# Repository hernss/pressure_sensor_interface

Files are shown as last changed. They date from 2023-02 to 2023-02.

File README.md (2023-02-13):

# Descripción del proyecto:

Se desea realizar un dispositivo que sirva de interface para un sensor analógico de presión. El sensor en cuestión es un sensor de presión absoluta que trabaja sobre una línea de aire comprimido, la salida de dicho sensor es del tipo 4-20mA y el rango te trabajo es de 0 a 10bar.
Este dispositivo tiene como objetivo mantener la línea de aire comprimido en un rango de presión predefinido por el usuario, y en caso de no encontrarse en dicho límite actúa como dispositivo de seguridad liberando la presión en la línea y haciendo sonar una alarma.
El núcleo de este proyecto es un Cortex M3 de la familia de STM el cual lleva implementado un sistema de control del estilo TDS el cual nos asegura el tiempo de respuesta en caso de presentarse una falla.
Por ser requerimiento de otra materia, se conectaron todos los periféricos a una línea de datos I2C. Estos periféricos son:

* Teclado Capacitivo (IQS316)
* Display LCD de 16 Caracteres 2 líneas con conversor I2C (PCF8754)
* Conversor Analógico Digital (ADS1115)
* Memoria EEPROM para parámetros de configuración (24LC16)
* Dos salidas a relé con optoacoplador de protección.

# Desarrollo en Kicad

Se optó por realizar dos PCB, uno para el teclado con el display y otro para el microcontrolador y los demás periféricos. Se desarrolló de esta manera ya que el teclado capacitivo necesitar ser implementado en el PCB y aplicado directamente sobre el panel frontal. Entonces, se hizo un PCB denominado PanelFrontal el cual lleva los pads del teclado capacitivo en la cara BOTTOM del PCB, se ubicaron los componentes en la cara TOP y se limitó el uso a solo componentes de montaje superficial, es así que al no tener componentes “through hole” no hay nada que sobresalga del lado BOTTOM y es así que el PCB puede ser apoyado directamente sobre el frente del gabinete. En el PCB denominado PlacaBase se implementó el micro-controlador y todos los periféricos ya que estos requieren varios componentes “through hole” y además de eso no hay una uniformidad de alturas lo cual complicaría el desarrollo en una sola placa junto al teclado.

# Calculo de los componentes:

## Fuente de Alimentación:
Nos vamos a encontrar con dos tipos de alimentación, el microcontrolador, la memoria EEPROM y el ADC se alimentan con 3,3V mientras que los demás dispositivos se alimentan con 5V. Es por esto que se decidió alimentar el dispositivo con una fuente externa de 5V DC 1A y se implementó en la placa base una fuente de alimentación de 3.3v basada en un LD1117 con sus respectivos capacitores.

## Capacitores de los cristales:
Para seleccionar estos capacitores vamos a referirnos a la hoja de datos de los cristales. Para el cristal de 8 MHz (ABM7-8.000MHZ-D2Y-T) vemos que la hoja de datos nos dice que capacitancia de carga es de 18 pF por ende se conectan dos capacitores de 18 pF en los pines del cristal a masa. Para el cristal de 32.768 KHz (ABS25-32.768KHZ-T) la hoja de datos nos dice que la capacitancia de carga es de 12.5 pF, en este caso se selecciona un capacitor de 12pF para conectar en los pines del cristal. Se diseña el circuito impreso de tal manera que ambas pistas que conectan al microcontrolador con el cristal tengan el mismo largo y la misma geometría.

## Leds internos de indicación:
Los leds se utilizaron los LTST-C171KRKT y LTST-C170KGKT ambos son excitados por una tensión de 3.3v ya que uno está conectado a una salida del microcontrolador y el otro directamente a los 3.3v de alimentación. Según la hoja de datos observamos que típicamente tienen 2v de tensión en directa. Se decidió usar una resistencia limitadora de 100 Ohms lo cual nos limitaría la corriente del diodo en 13 mA. Lo cual está por debajo de la corriente máxima de 30ma que acusa el fabricante.

I_F=(3.3v-2v)/(100 Ω)=13 mA

## Resistencias de los Optoacopladores:
Si nos referimos al datasheet de los optoacopladores PC817 vemos que la tensión en directa es de 1.2v mientras que la corriente es de 20 mA. En base a estos valores se calculó la resistencia limitadora.

R=(3.3v - 1.2v)/(20 mA)=105 Ω

Se adoptó una resistencia de 100 ohm siendo el valor comercial más cercano.

## Corriente de base en los transistores de los relés:
Se eligió los transistores BC846B para activar los relés. Estos transistores tienen una resistencia de base de 680 ohms. Si suponemos que los optoacopladores tiene la resistencia adecuada para su funcionamiento podemos calcular la corriente de base según la siguiente formula:

I_B=(5V- V_BE)/680Ω=(5V- 0.7v)/680Ω=6.3 mA

Teniendo en cuenta que el relé consume 80 mA, esta corriente nos asegura que el transistor se encuentra saturado con una tensión VCE menor a 0,2v

# Resistencia de entrada del ADC:
El sensor de presión con el que vamos a trabajar posee una salida de 4-20mA donde 4ma representa 0bar y 20mA 10bar. Es por esto que vamos a ajustar la resistencia para que esta corriente nos produzca una caída de tensión que podamos medir con el ADC. Se utilizó una resistencia de 100 ohms la cual se la eligió con una tolerancia de 0,1% ya que es fundamental que este valor de resistencia sea preciso ya que de ella depende la precisión de nuestra medición. Con este valor, la tensión en la entrada del ADC en el rango mínimo será de 0.4v y en el rango máximo de 2v. La tensión máxima admisible en la entrada del ADC es de 3.3v. Con esta configuración el ADC además de permitirnos medir el valor arrojado por el sensor nos da un margen como para medir si la entrada de corriente esta fuera de rango. El ADC tiene una resolución de 16bits, por ende tenemos una resolución de 3,3v / 2^16 = 50 µv/div, siendo para el rango mínimo de 0,4v / (50 µv/div) = 7943 y para el rango máximo 2v / (50 µv/div) = 39718

## Direcciones del Bus I2C:
Cada periférico tiene su propia dirección I2C para que todos puedan funcionar en el mismo bus. Estas especificaciones las obtenemos de las hojas de datos de los componentes. En general la mayoría tiene al menos un pin que podemos conectar a GND o Vcc para terminar de definir la dirección.
Para el caso de ADC el pin de configuración de dirección se conectó a GND asignándole una dirección “1001000x” (0x50h). En la memoria EEPROM los pines de dirección no se encuentran conectados ya que este tamaño de memoria no los implementa. La dirección I2C se usa en parte para direccionar internamente los bloques de memoria, es por esto que para la memoria se reservan las direcciones 0x60h hasta la 0x6Fh. El conversor I2C para el display LCD se le cablearon sus 3 pines de dirección a masa fijándole una dirección I2C de 0x70h. Para el integrado que controla el teclado capacitivo su pin de dirección se encuentra conectado a masa asignándole una dirección I2C de 0xE1h.
De esta manera, todos los periféricos nos quedan con direcciones distintas posibilitando la conexión al mismo bus I2C.

## Consumo total del Dispositivo:
Se analizaron los consumos máximos que podría llegar a tener el dispositivo así poder calcular la fuente de alimentación y el ancho de las pistas. Se analizaron solo los componentes más relevantes. Cada relé consume 80mA estando activados, el LCD tiene un consumo relevante el backligth que según la hoja de datos alcanza los 156 mA como máximo y podríamos sumarle algunos miliamperes mas por los demás componentes lo cual nos daría aproximadamente 330 mA sobre la línea de 5v.
 
# Diagrama Esquemático:

## Panel Frontal:
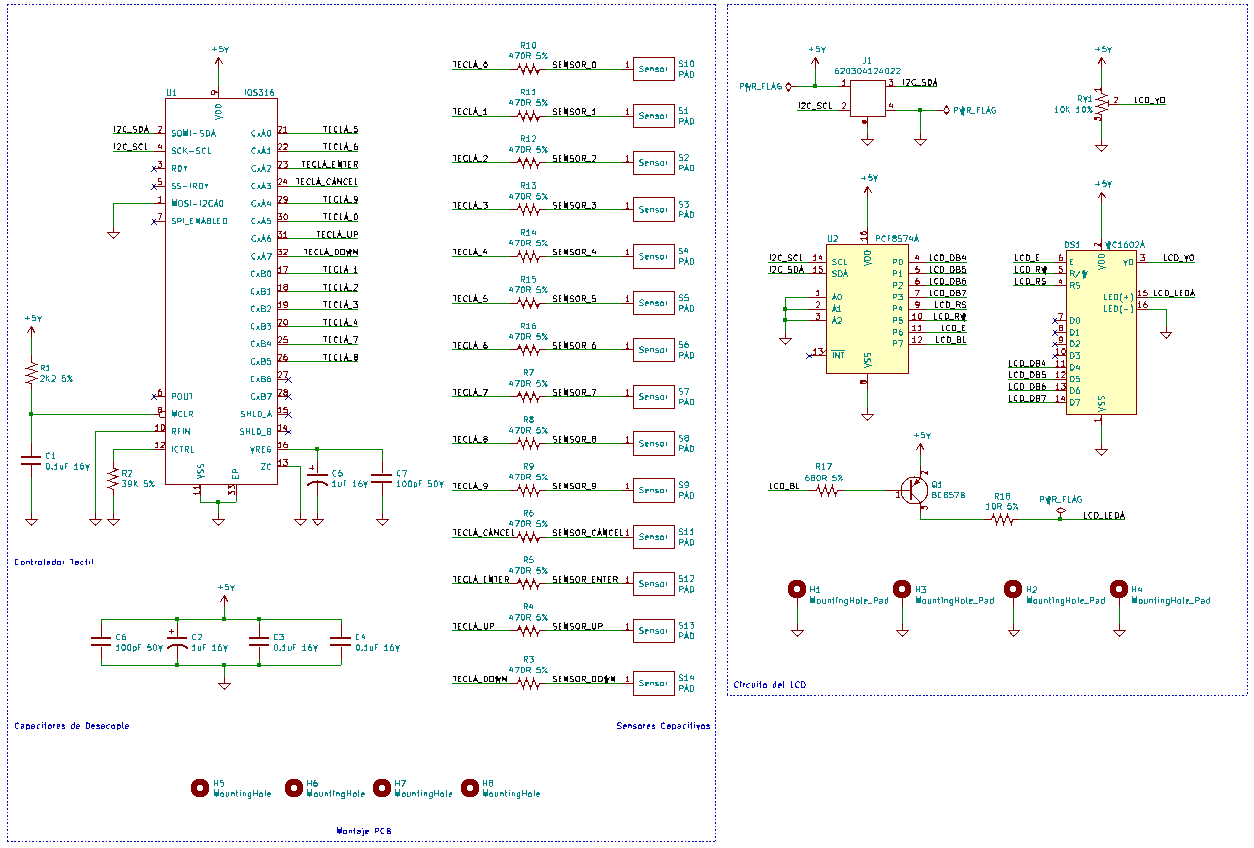
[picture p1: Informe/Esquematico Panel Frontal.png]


## Placa Base
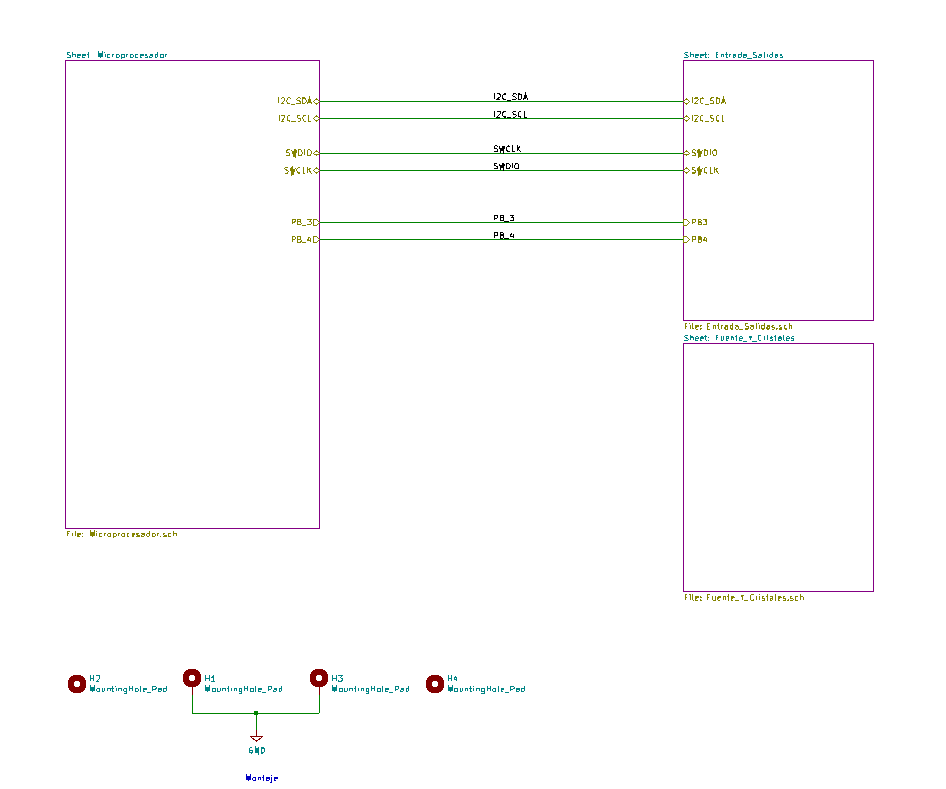
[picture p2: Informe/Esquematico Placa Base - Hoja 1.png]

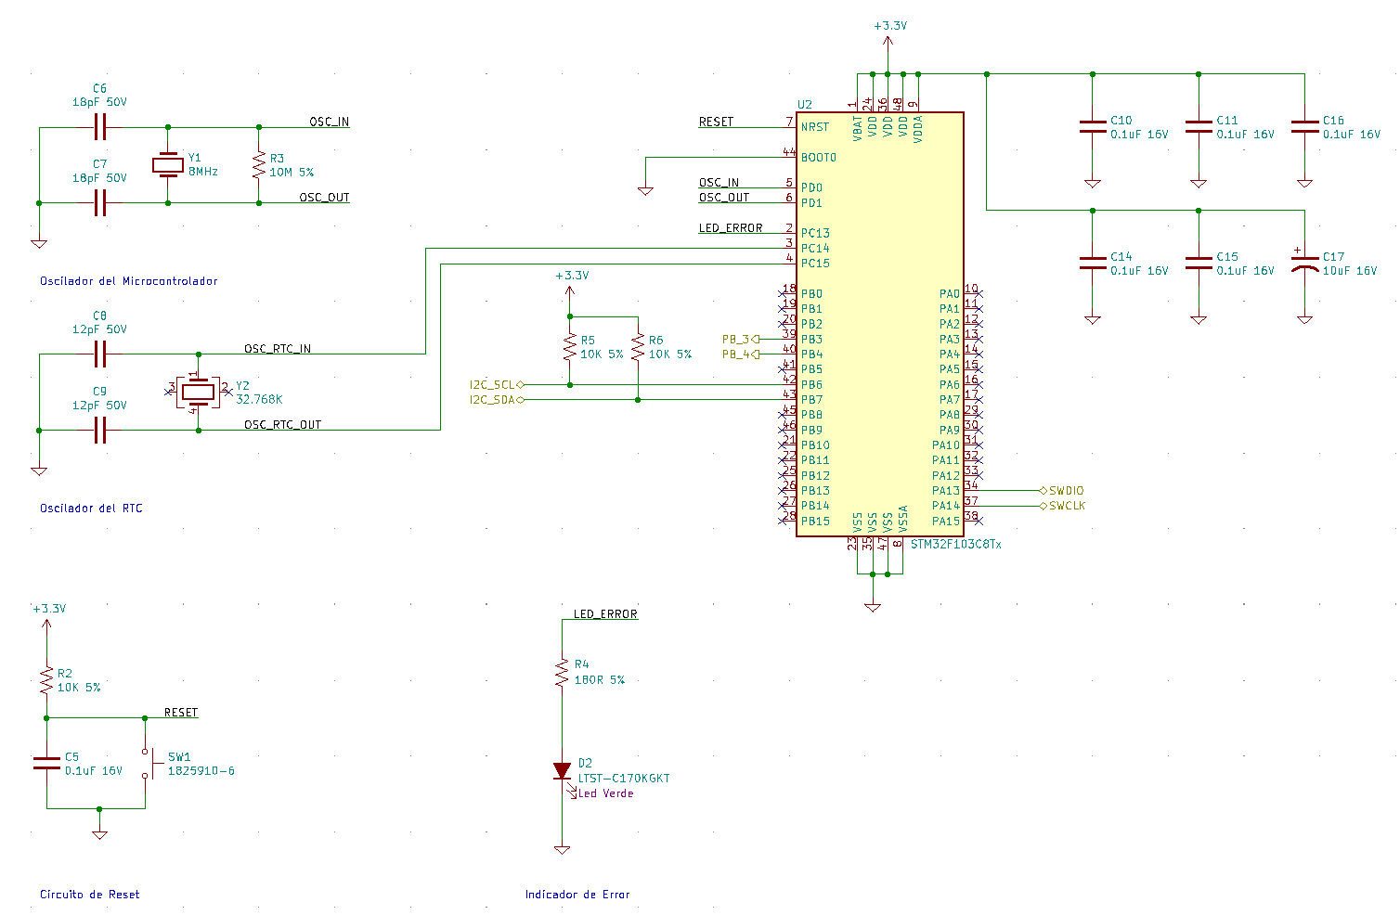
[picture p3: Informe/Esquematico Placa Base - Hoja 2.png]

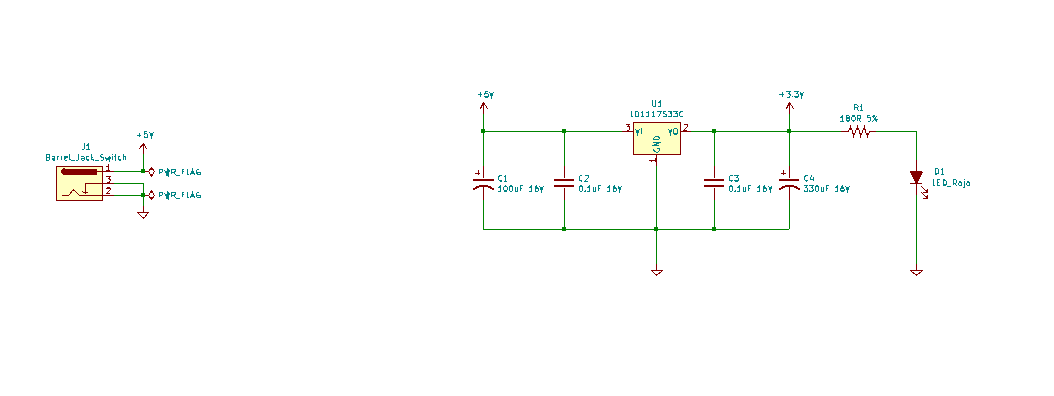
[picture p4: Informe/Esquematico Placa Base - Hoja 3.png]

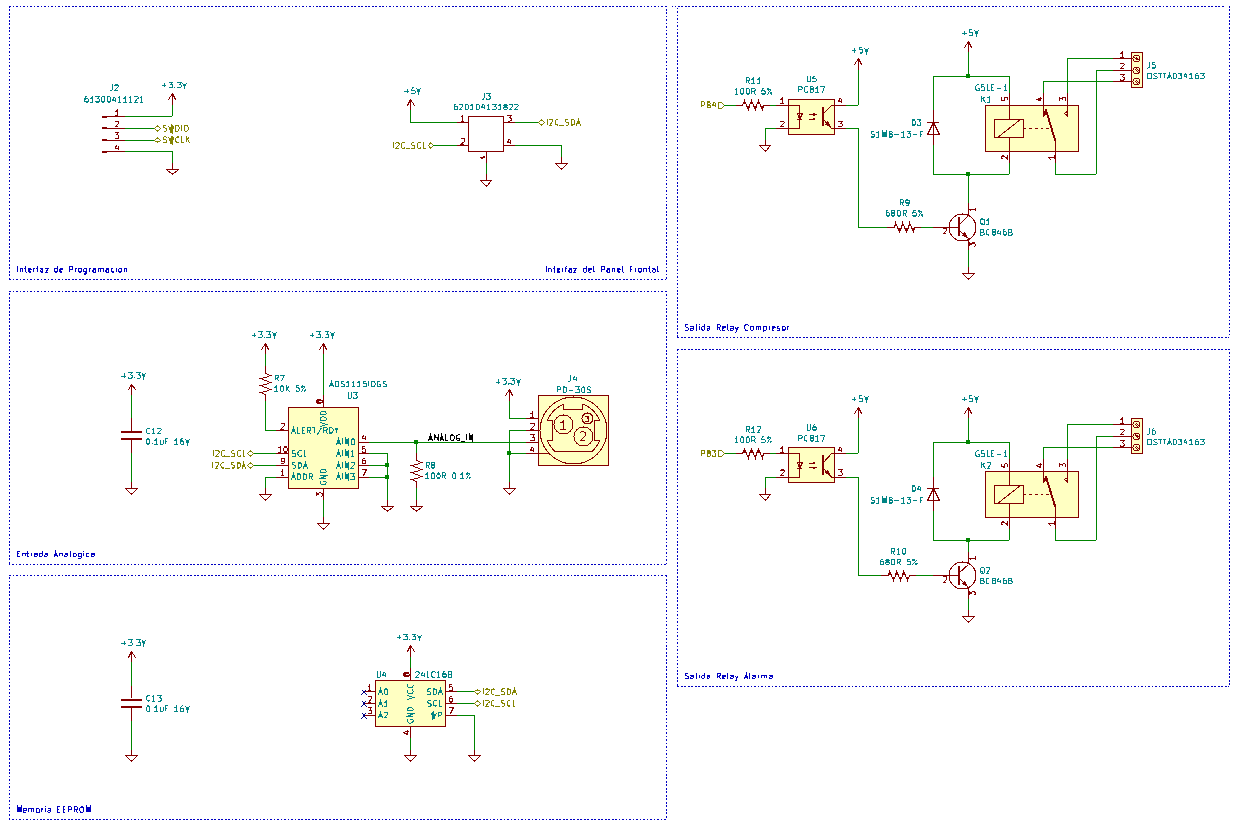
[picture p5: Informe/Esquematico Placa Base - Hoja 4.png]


# Circuito Impreso:

## Panel Frontal
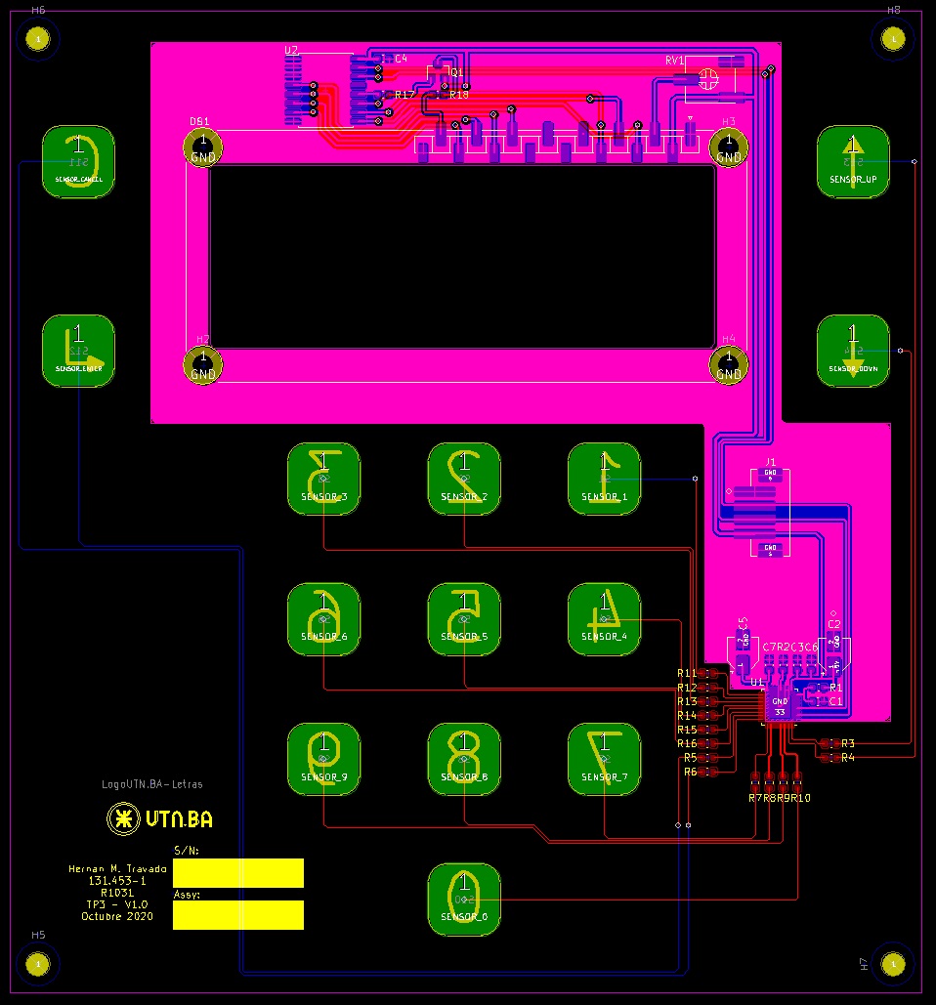
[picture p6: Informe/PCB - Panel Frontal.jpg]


## Placa Base
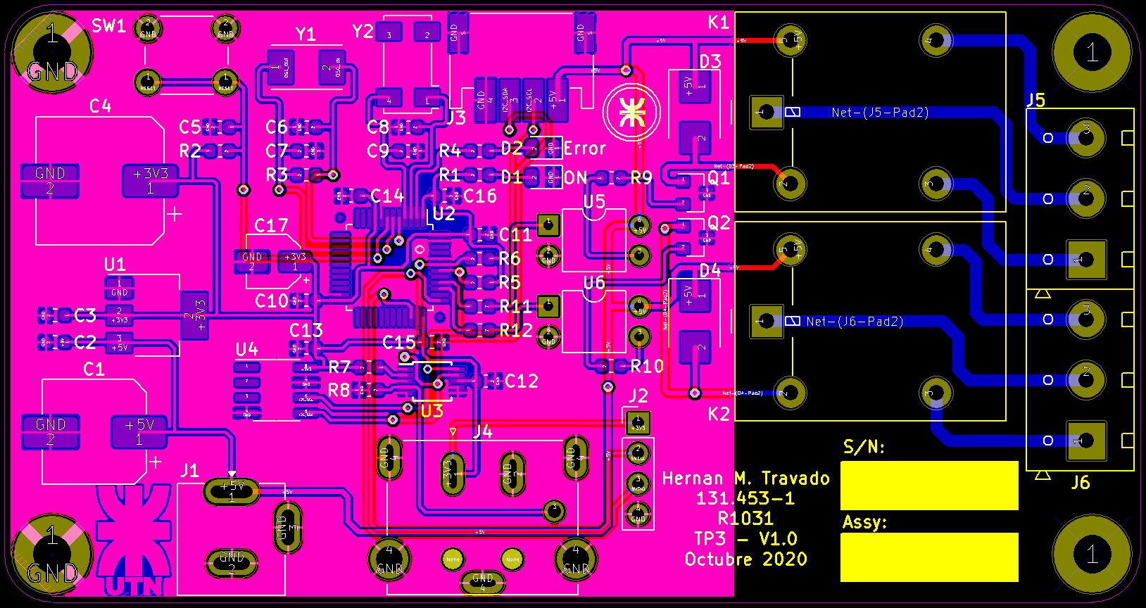
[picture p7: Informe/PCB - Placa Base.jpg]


# Vista 3D de la placa terminada:

## Panel Frontal
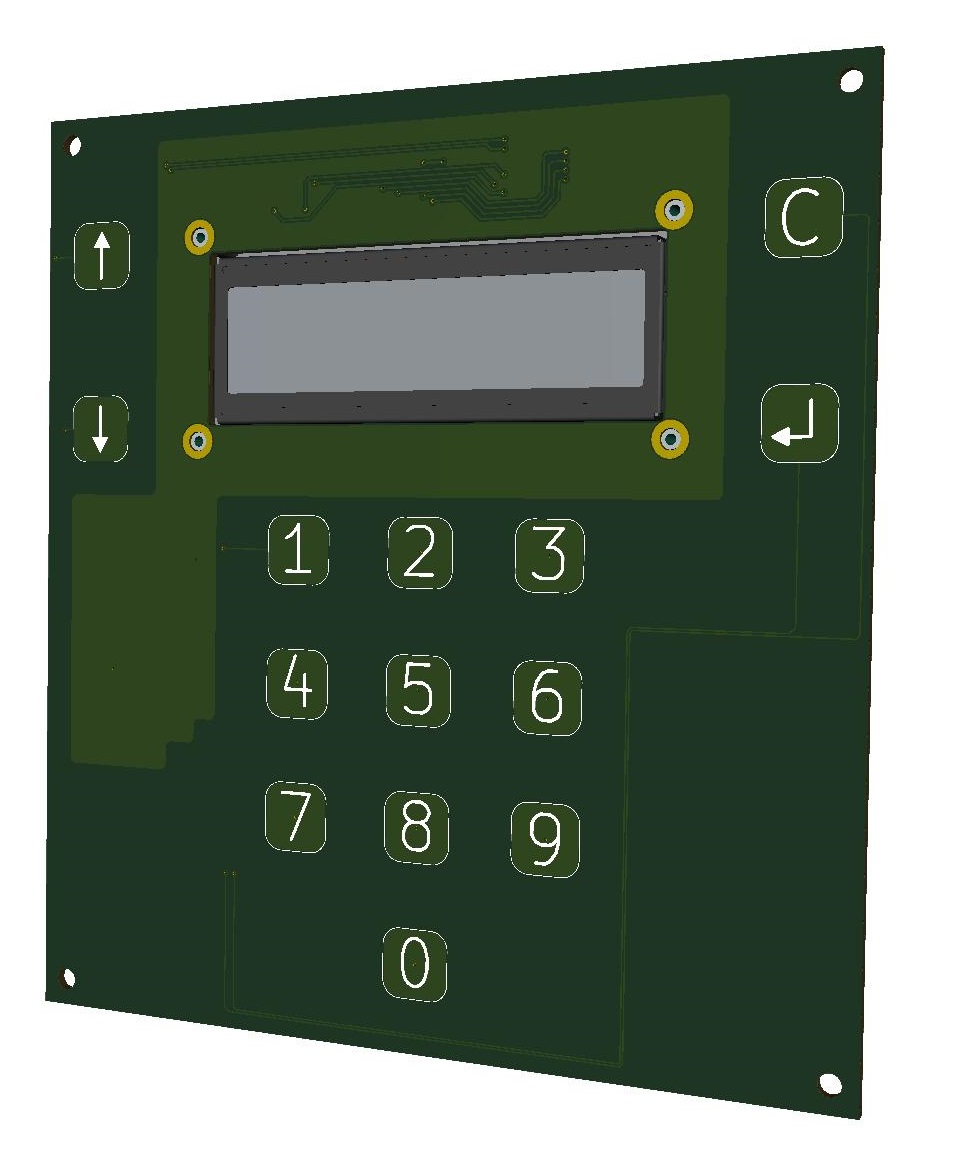
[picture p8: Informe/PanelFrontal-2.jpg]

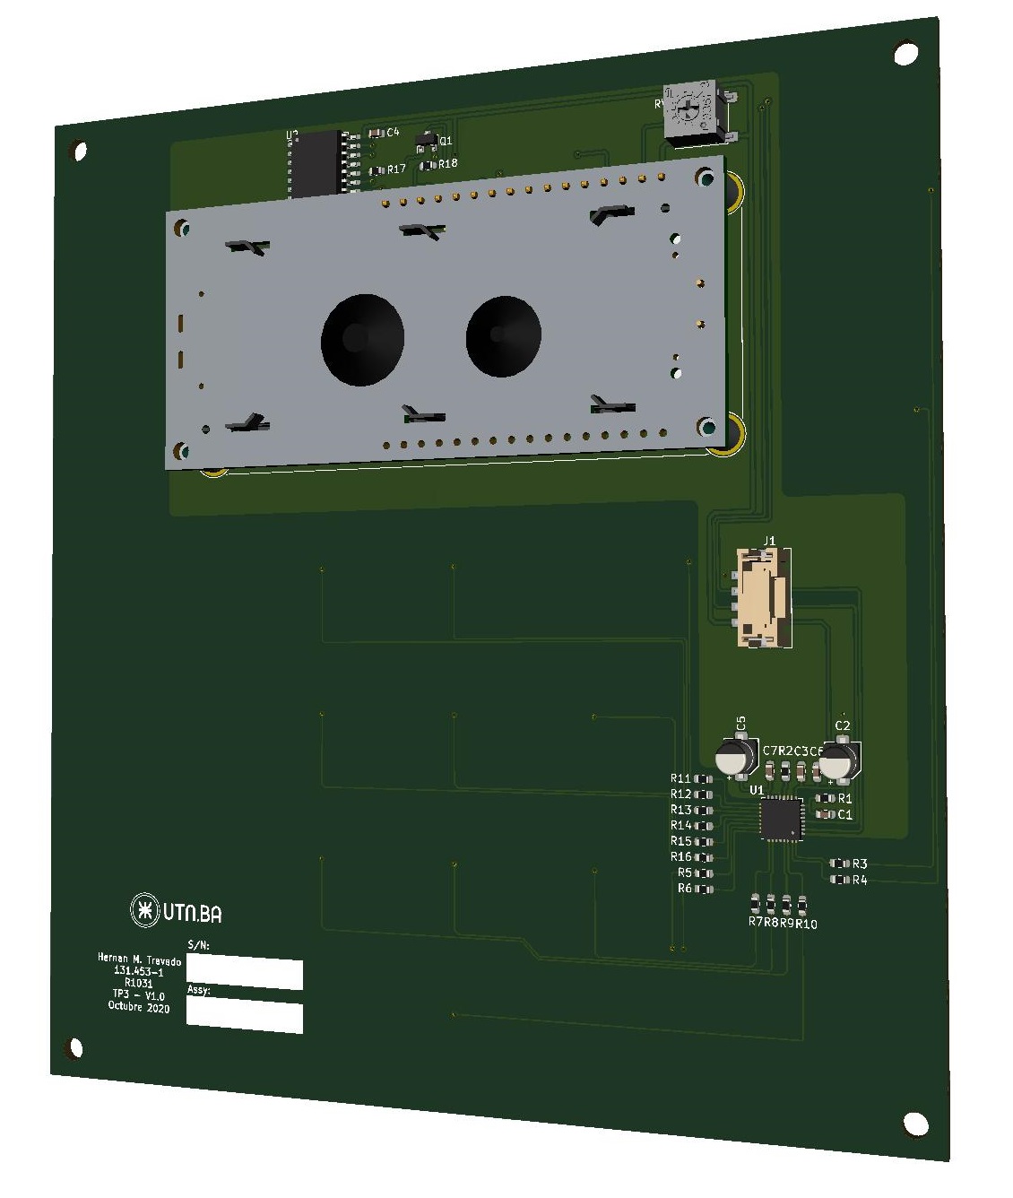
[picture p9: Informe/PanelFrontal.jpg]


## Placa Base
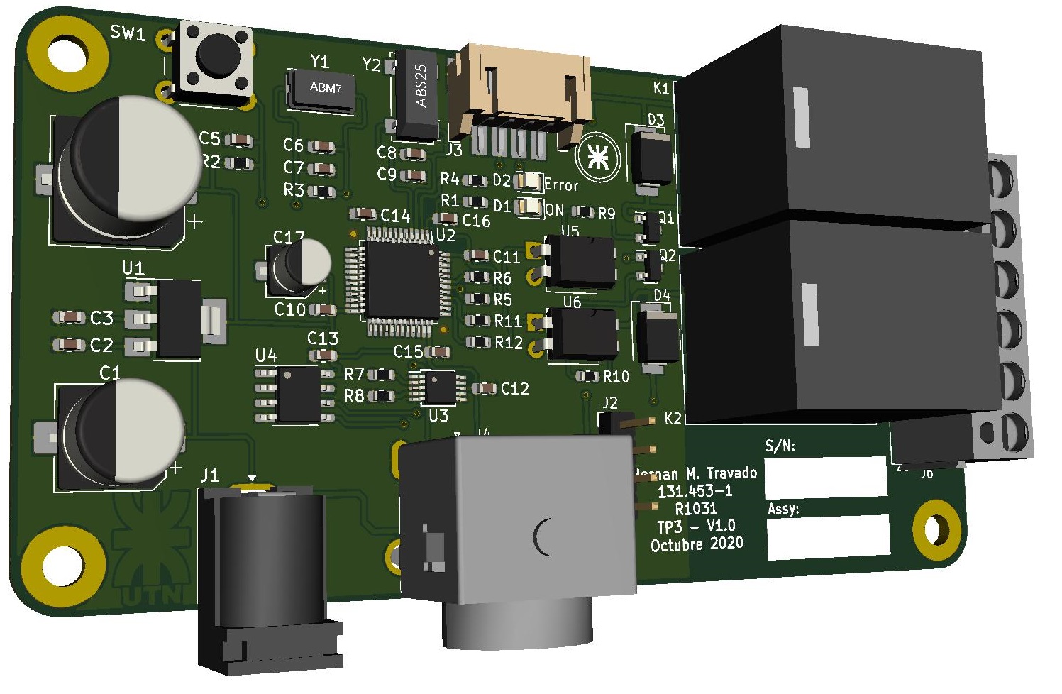
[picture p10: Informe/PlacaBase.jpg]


# Panelizado
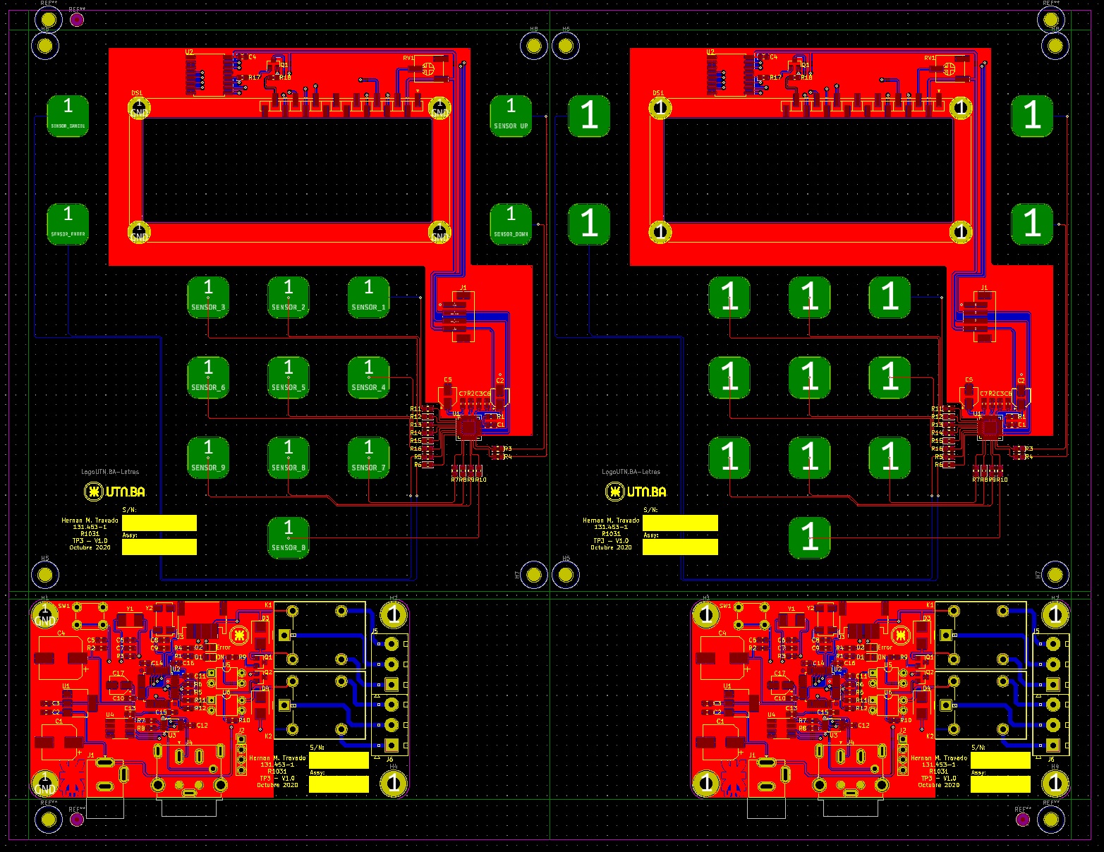
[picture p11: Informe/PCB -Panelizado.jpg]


# Gabinete

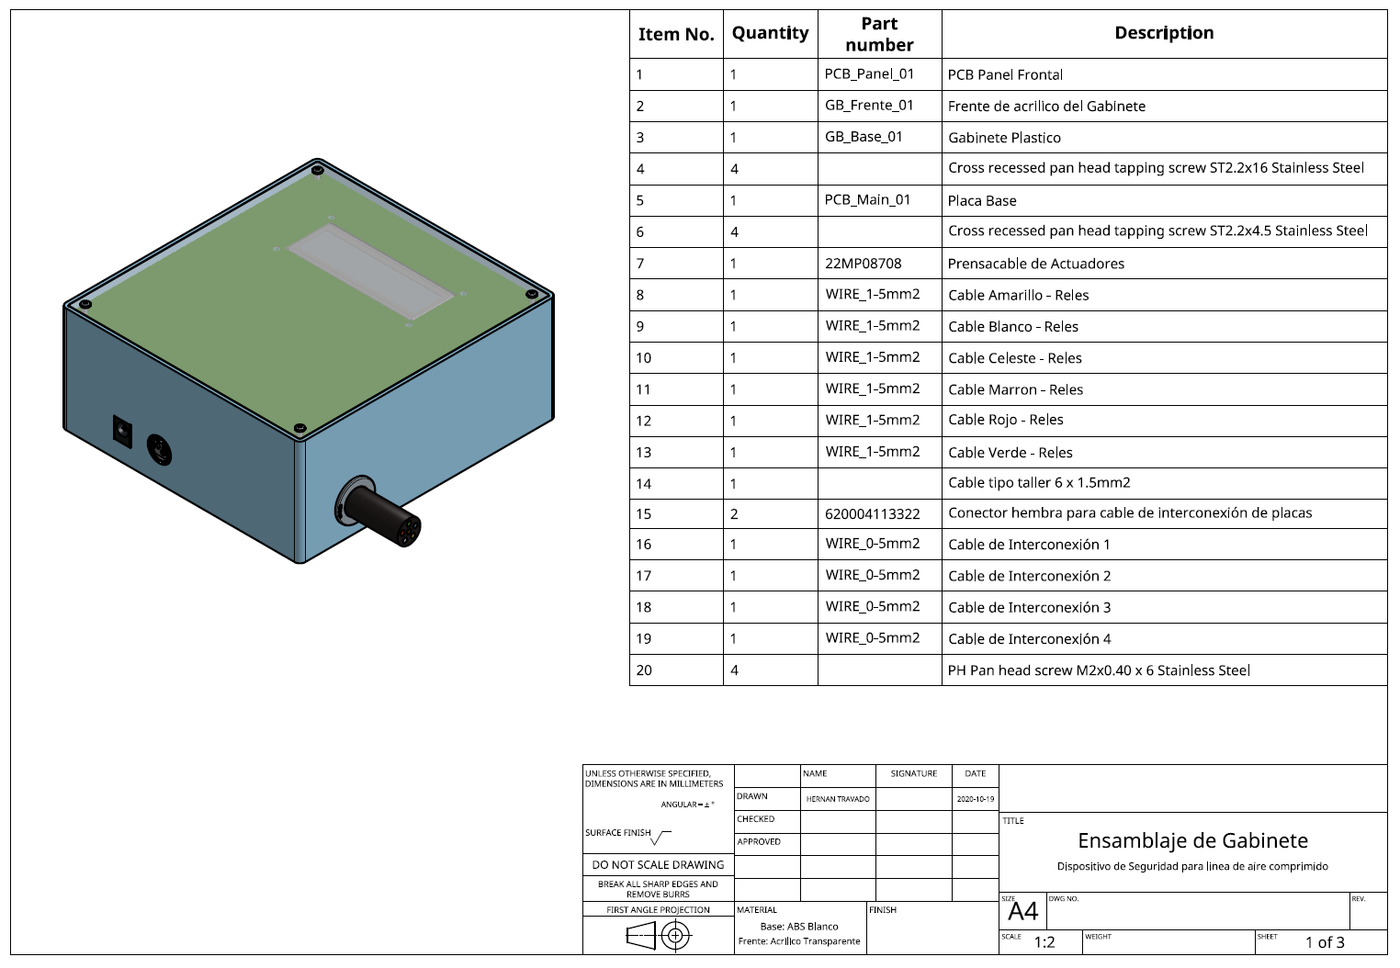
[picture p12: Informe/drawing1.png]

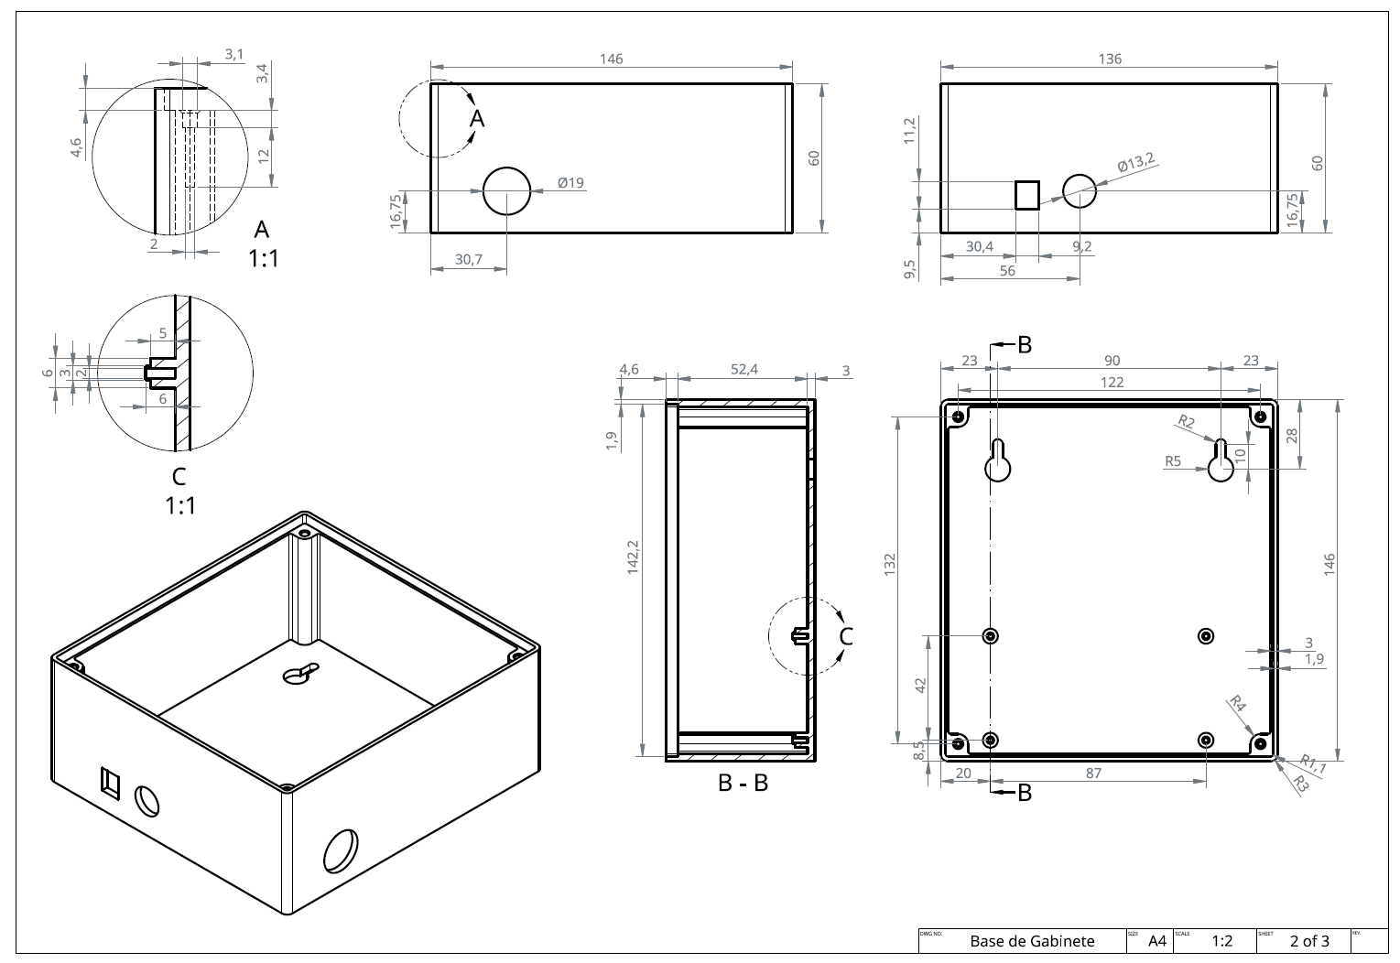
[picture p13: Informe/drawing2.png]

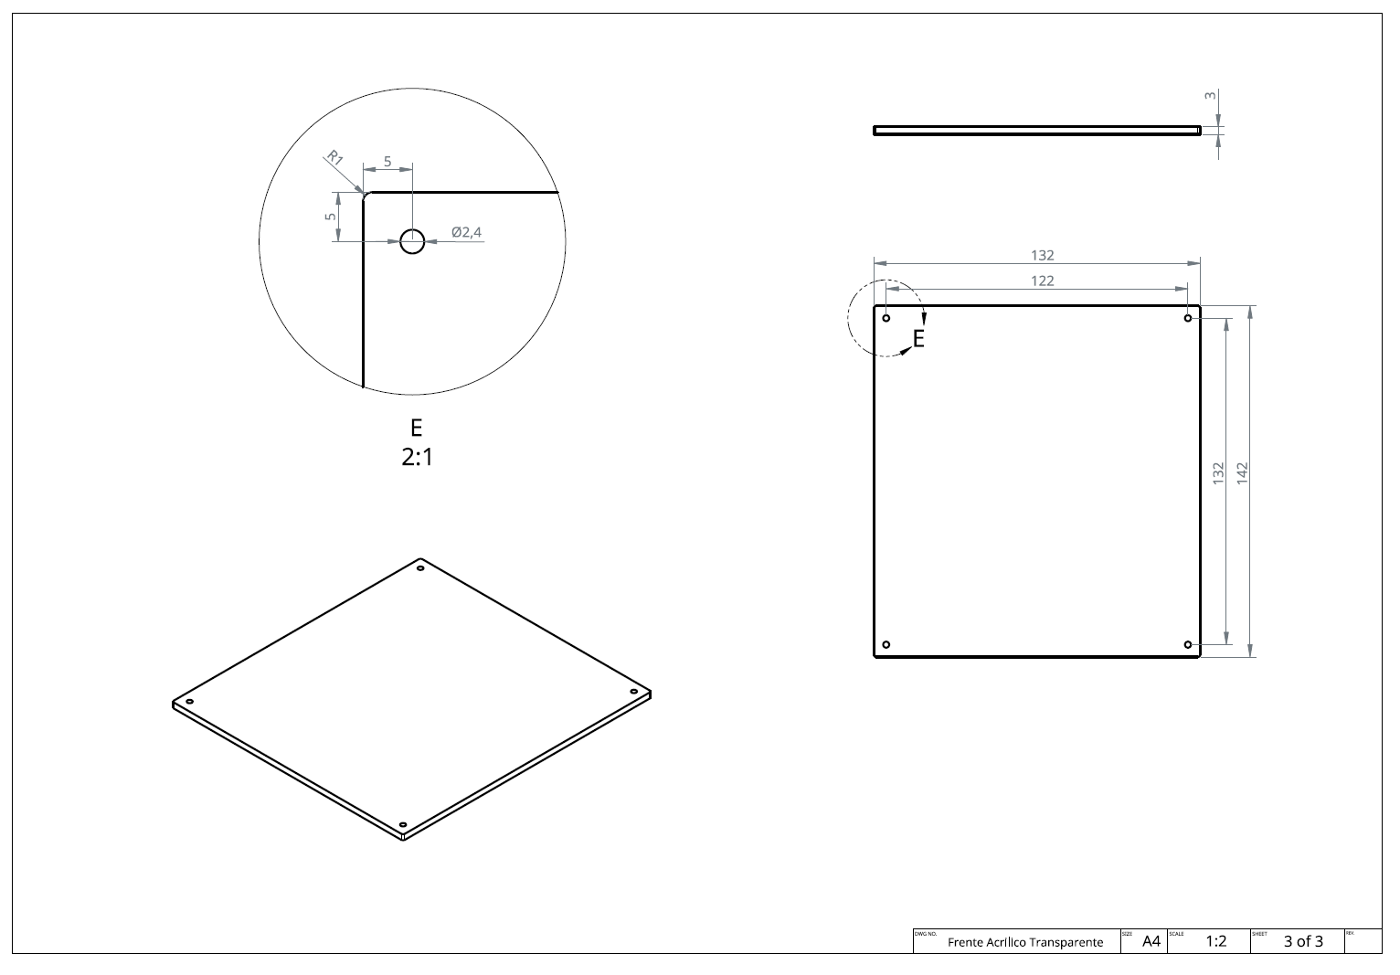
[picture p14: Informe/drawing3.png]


## Vista en 3D

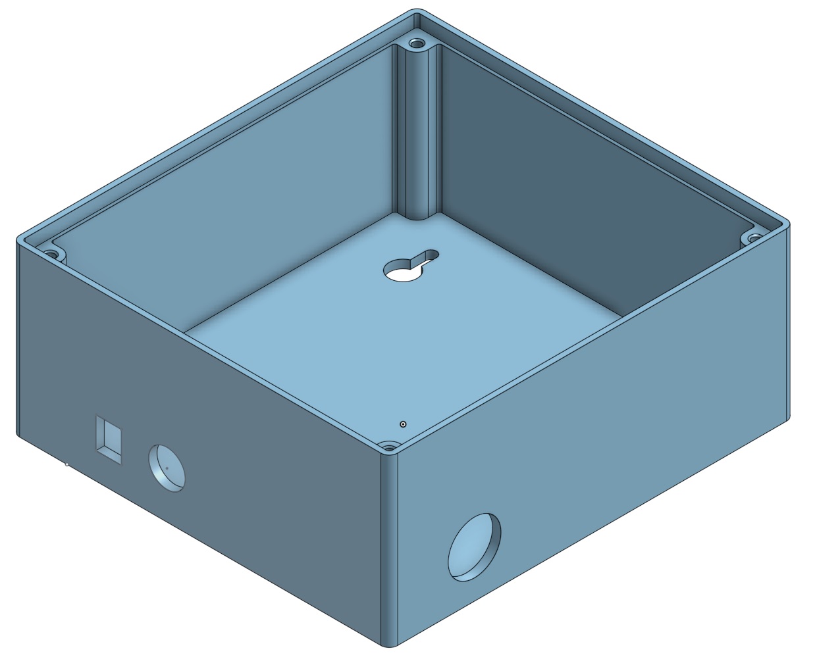
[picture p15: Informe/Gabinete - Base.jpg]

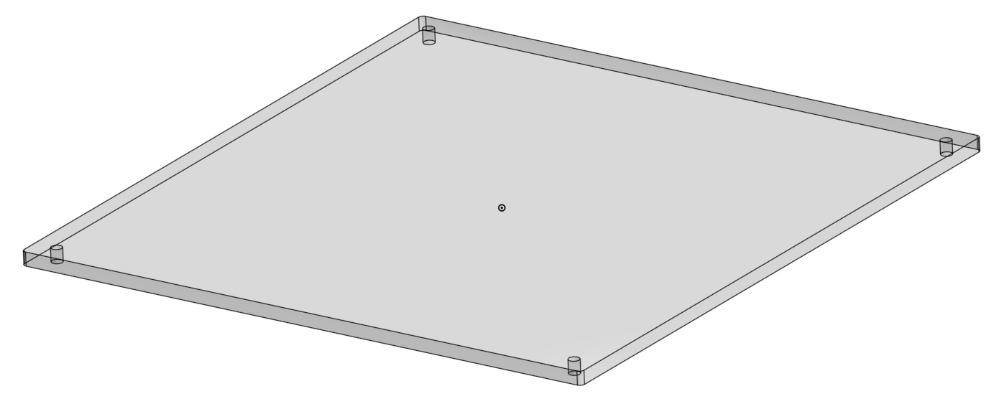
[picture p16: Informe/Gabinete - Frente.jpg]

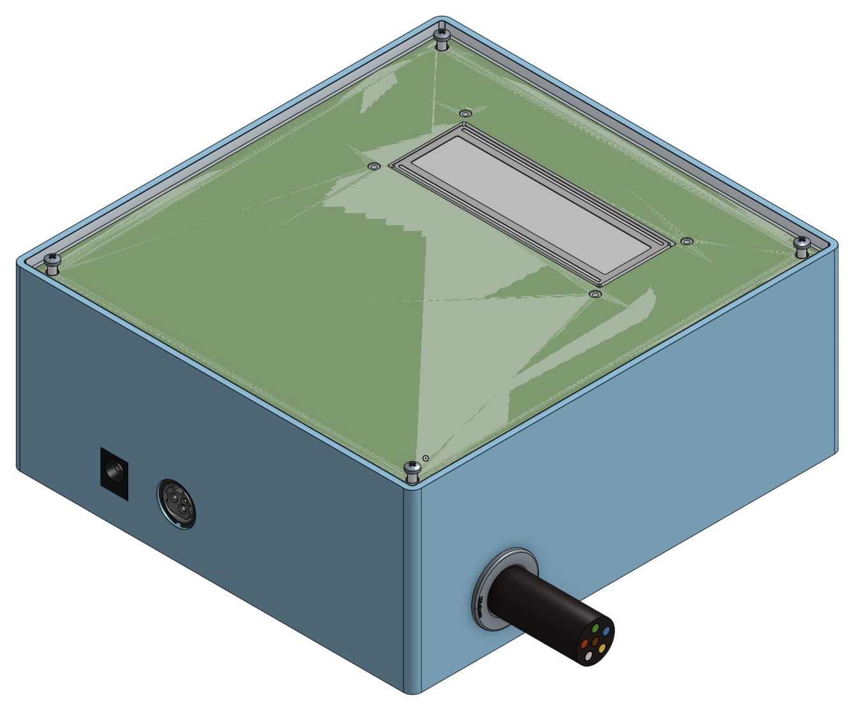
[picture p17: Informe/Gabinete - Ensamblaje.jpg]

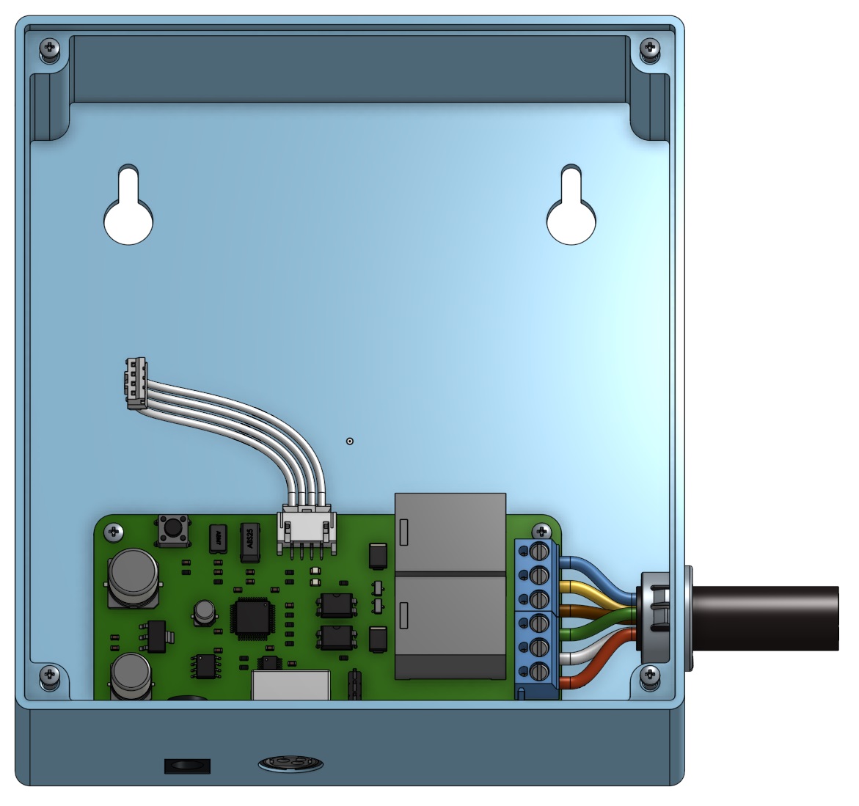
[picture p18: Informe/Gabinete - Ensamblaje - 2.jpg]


# Link a ON-Shape:

https://cad.onshape.com/documents/e1ddf4852ee30d10dbbbdde3/w/8d886781dbbcdb7a099e42b0/e/7b9d0c14e845cfce50a3e853

# Links a Octopart:

## Panel Frontal:

https://octopart.com/bom-tool/DTLM5kml

## Placa Base:

https://octopart.com/bom-tool/Puk0rRIS

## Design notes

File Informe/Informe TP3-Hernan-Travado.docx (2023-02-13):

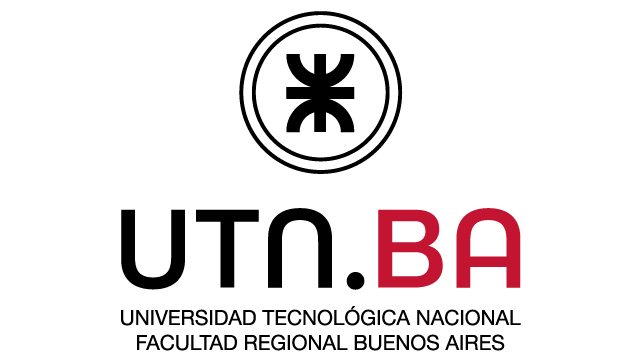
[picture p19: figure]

SISTEMAS DE REPRESENTACIÓN

Trabajo Práctico Nro. 3

Alumno: Hernán Matías Travado

Legajo: 131.453-1

Curso: R1031 – Jueves Tarde

Fecha de Entrega: 23/11/2020

Versión: 2.0

Profesores: Fernando Aló – Francisco Domínguez - Lucas Liaño

Tabla de Contenidos:

# Descripción del proyecto:

Se desea realizar un dispositivo que sirva de interface para un sensor analógico de presión. El sensor en cuestión es un sensor de presión absoluta que trabaja sobre una línea de aire comprimido, la salida de dicho sensor es del tipo 4-20mA y el rango te trabajo es de 0 a 10bar.

Este dispositivo tiene como objetivo mantener la línea de aire comprimido en un rango de presión predefinido por el usuario, y en caso de no encontrarse en dicho límite actúa como dispositivo de seguridad liberando la presión en la línea y haciendo sonar una alarma.

El núcleo de este proyecto es un Cortex M3 de la familia de STM el cual lleva implementado un sistema de control del estilo TDS el cual nos asegura el tiempo de respuesta en caso de presentarse una falla.

Por ser requerimiento de otra materia, se conectaron todos los periféricos a una línea de datos I2C. Estos periféricos son:

Teclado Capacitivo (IQS316)

Display LCD de 16 Caracteres 2 líneas con conversor I2C (PCF8754)

Conversor Analógico Digital (ADS1115)
Memoria EEPROM para parámetros de configuración (24LC16)

Dos salidas a relé con optoacoplador de protección.

# Desarrollo en Kicad

Se optó por realizar dos PCB, uno para el teclado con el display y otro para el microcontrolador y los demás periféricos. Se desarrolló de esta manera ya que el teclado capacitivo necesitar ser implementado en el PCB y aplicado directamente sobre el panel frontal. Entonces, se hizo un PCB denominado PanelFrontal el cual lleva los pads del teclado capacitivo en la cara BOTTOM del PCB, se ubicaron los componentes en la cara TOP y se limitó el uso a solo componentes de montaje superficial, es así que al no tener componentes “through hole” no hay nada que sobresalga del lado BOTTOM y es así que el PCB puede ser apoyado directamente sobre el frente del gabinete. En el PCB denominado PlacaBase se implementó el micro-controlador y todos los periféricos ya que estos requieren varios componentes “through hole” y además de eso no hay una uniformidad de alturas lo cual complicaría el desarrollo en una sola placa junto al teclado.

# Calculo de los componentes:

## Fuente de Alimentación:

Nos vamos a encontrar con dos tipos de alimentación, el microcontrolador, la memoria EEPROM y el ADC se alimentan con 3,3V mientras que los demás dispositivos se alimentan con 5V. Es por esto que se decidió alimentar el dispositivo con una fuente externa de 5V DC 1A y se implementó en la placa base una fuente de alimentación de 3.3v basada en un LD1117 con sus respectivos capacitores.

## Capacitores de los cristales:

Para seleccionar estos capacitores vamos a referirnos a la hoja de datos de los cristales. Para el cristal de 8 MHz (ABM7-8.000MHZ-D2Y-T) vemos que la hoja de datos nos dice que capacitancia de carga es de 18 pF por ende se conectan dos capacitores de 18 pF en los pines del cristal a masa. Para el cristal de 32.768 KHz (ABS25-32.768KHZ-T) la hoja de datos nos dice que la capacitancia de carga es de 12.5 pF, en este caso se selecciona un capacitor de 12pF para conectar en los pines del cristal. Se diseña el circuito impreso de tal manera que ambas pistas que conectan al microcontrolador con el cristal tengan el mismo largo y la misma geometría.

## Leds internos de indicación:

Los leds se utilizaron los LTST-C171KRKT y LTST-C170KGKT ambos son excitados por una tensión de 3.3v ya que uno está conectado a una salida del microcontrolador y el otro directamente a los 3.3v de alimentación. Según la hoja de datos observamos que típicamente tienen 2v de tensión en directa. Se decidió usar una resistencia limitadora de 100 Ohms lo cual nos limitaría la corriente del diodo en 13 mA. Lo cual está por debajo de la corriente máxima de 30ma que acusa el fabricante.

I_F =(3.3v-2v)/(100 Ω)=13 mA

## Resistencias de los Optoacopladores:

Si nos referimos al datasheet de los optoacopladores PC817 vemos que la tensión en directa es de 1.2v mientras que la corriente es de 20 mA. En base a estos valores se calculó la resistencia limitadora.

R=(3.3v - 1.2v)/(20 mA)=105 Ω

Se adoptó una resistencia de 100 ohm siendo el valor comercial más cercano.

## Corriente de base en los transistores de los relés:

Se eligió los transistores BC846B para activar los relés. Estos transistores tienen una resistencia de base de 680 ohms. Si suponemos que los optoacopladores tiene la resistencia adecuada para su funcionamiento podemos calcular la corriente de base según la siguiente formula:

I_B =(5V- V_(BE))/(680Ω)=(5V- 0.7v)/(680Ω)=6.3 mA

Teniendo en cuenta que el relé consume 80 mA, esta corriente nos asegura que el transistor se encuentra saturado con una tensión VCE menor a 0,2v

## Resistencia de entrada del ADC:

El sensor de presión con el que vamos a trabajar posee una salida de 4-20mA donde 4ma representa 0bar y 20mA 10bar. Es por esto que vamos a ajustar la resistencia para que esta corriente nos produzca una caída de tensión que podamos medir con el ADC. Se utilizó una resistencia de 100 ohms la cual se la eligió con una tolerancia de 0,1% ya que es fundamental que este valor de resistencia sea preciso ya que de ella depende la precisión de nuestra medición. Con este valor, la tensión en la entrada del ADC en el rango mínimo será de 0.4v y en el rango máximo de 2v. La tensión máxima admisible en la entrada del ADC es de 3.3v. Con esta configuración el ADC además de permitirnos medir el valor arrojado por el sensor nos da un margen como para medir si la entrada de corriente esta fuera de rango. El ADC tiene una resolución de 16bits, por ende tenemos una resolución de 3,3v / 2^16 = 50 µv/div, siendo para el rango mínimo de 0,4v / (50 µv/div) = 7943 y para el rango máximo 2v / (50 µv/div) = 39718

## Direcciones del Bus I2C:

Cada periférico tiene su propia dirección I2C para que todos puedan funcionar en el mismo bus. Estas especificaciones las obtenemos de las hojas de datos de los componentes. En general la mayoría tiene al menos un pin que podemos conectar a GND o Vcc para terminar de definir la dirección.

Para el caso de ADC el pin de configuración de dirección se conectó a GND asignándole una dirección “1001000x” (0x50h). En la memoria EEPROM los pines de dirección no se encuentran conectados ya que este tamaño de memoria no los implementa. La dirección I2C se usa en parte para direccionar internamente los bloques de memoria, es por esto que para la memoria se reservan las direcciones 0x60h hasta la 0x6Fh. El conversor I2C para el display LCD se le cablearon sus 3 pines de dirección a masa fijándole una dirección I2C de 0x70h. Para el integrado que controla el teclado capacitivo su pin de dirección se encuentra conectado a masa asignándole una dirección I2C de 0xE1h.

De esta manera, todos los periféricos nos quedan con direcciones distintas posibilitando la conexión al mismo bus I2C.

## Consumo total del Dispositivo:

Se analizaron los consumos máximos que podría llegar a tener el dispositivo así poder calcular la fuente de alimentación y el ancho de las pistas. Se analizaron solo los componentes más relevantes. Cada relé consume 80mA estando activados, el LCD tiene un consumo relevante el backligth que según la hoja de datos alcanza los 156 mA como máximo y podríamos sumarle algunos miliamperes mas por los demás componentes lo cual nos daría aproximadamente 330 mA sobre la línea de 5v.

# Estructura del ZIP entregado:

Travado_Hernan_v1.0.zip
├───BOM | Lista de Materiales | Archivos .xls /.ods con la lista de materiales del proyecto
├───Checklist | Checklist | Checklist actualizado del proyecto
├───Gabinete | Gabinete | Archivos STEP del Proyecto de OnShape
│ └───Planos | Planos | Dibujos con dimensiones de las piezas (1 hoja por pieza)
├───Informe | Informe | Informe de todo el proyecto en PDF
├───PanelFrontal | Proyecto Kicad | Proyecto de Kicad para el Panel Frontal
│ ├───footprints | Librerías de footprints | Carpeta contenedora de librerías de footprint
│ │ ├───LogoUTN.pretty | Librería del proyecto | Otras librerías
│ │ └───PanelFrontal.pretty | Librería del proyecto | Librería de footprints propias del proyecto
│ ├───gerber | Gerbers | Gerbers, archivos de fabricación, drill files, etc.
│ ├───libraries | Librería de símbolos | Carpeta contenedora de librerías de símbolos
│ ├───modelos3D | Modelos en 3D | Archivos .step, .stp o .wrl de los componentes
│ └───output | Output | Contiene la BOM en CSV y los esquemáticos en PDF
├───Panelizado | Panel | Contiene el Panelizado del PCB
│ ├───gerber | Gerbers | Gerbers, drill files, etc. del panel
│ └───modelos3D | Modelos en 3D | Archivos .step, .stp o .wrl de los componentes
└───PlacaBase | Proyecto Kicad | Proyecto de Kicad para la Placa Base
├───footprints | Librerías de footprints | Carpeta contenedora de librerías de footprint
│ ├───HMIconSTM32.pretty | Librería del proyecto | Librería de footprints propias del proyecto
│ └───LogoUTN.pretty | Librería del proyecto | Otras librerías
├───gerber | Gerbers | Gerbers, archivos de fabricación, drill files, etc.
├───libraries | Librería de símbolos | Carpeta contenedora de librerías de símbolos
├───modelos3D | Modelos en 3D | Archivos .step, .stp o .wrl de los componentes
└───output | Output | Contiene la BOM en CSV y los esquemáticos en PDF

# Diagrama Esquemático:

## Panel Frontal:


## Placa Base:


Hoja jerárquica principal.


Fuente de alimentación.


Esquemático del microcontrolador.


Esquemático de las entradas y salidas.

# Circuito Impreso:

## Panel Frontal:

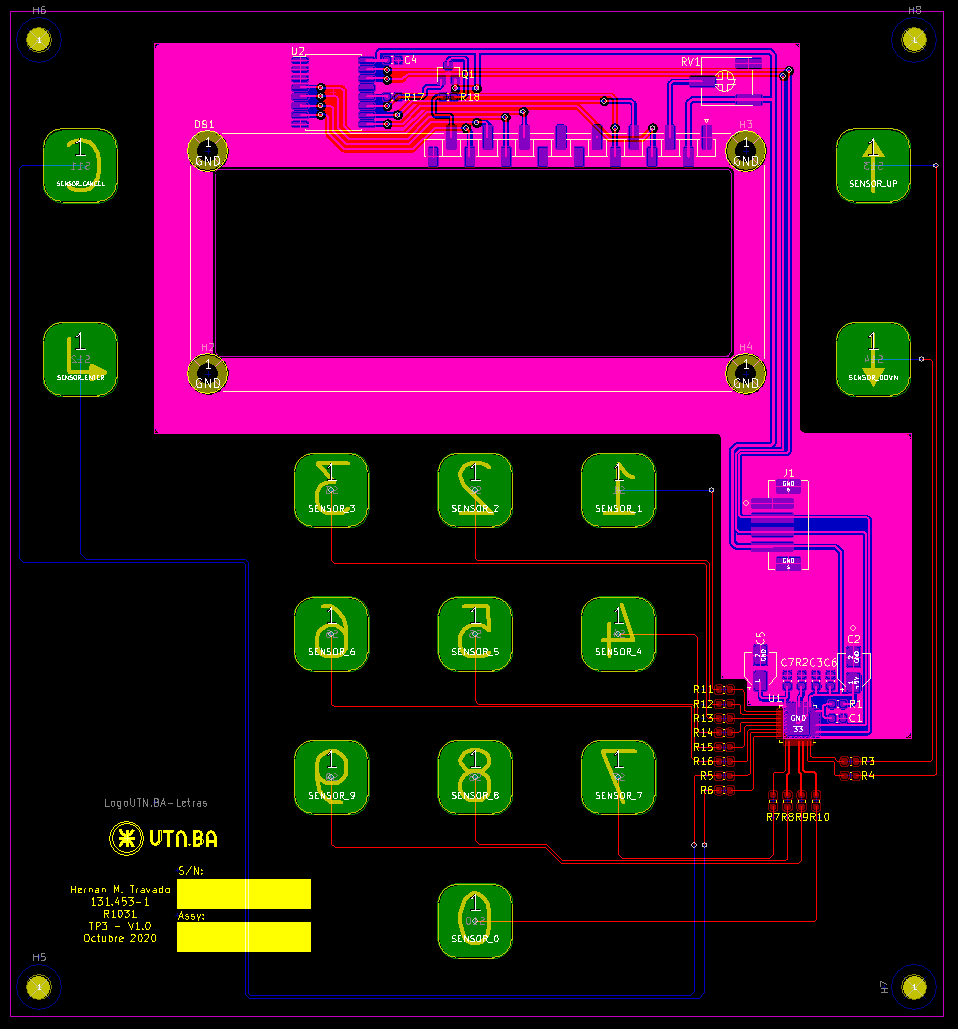
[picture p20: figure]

## Placa base:

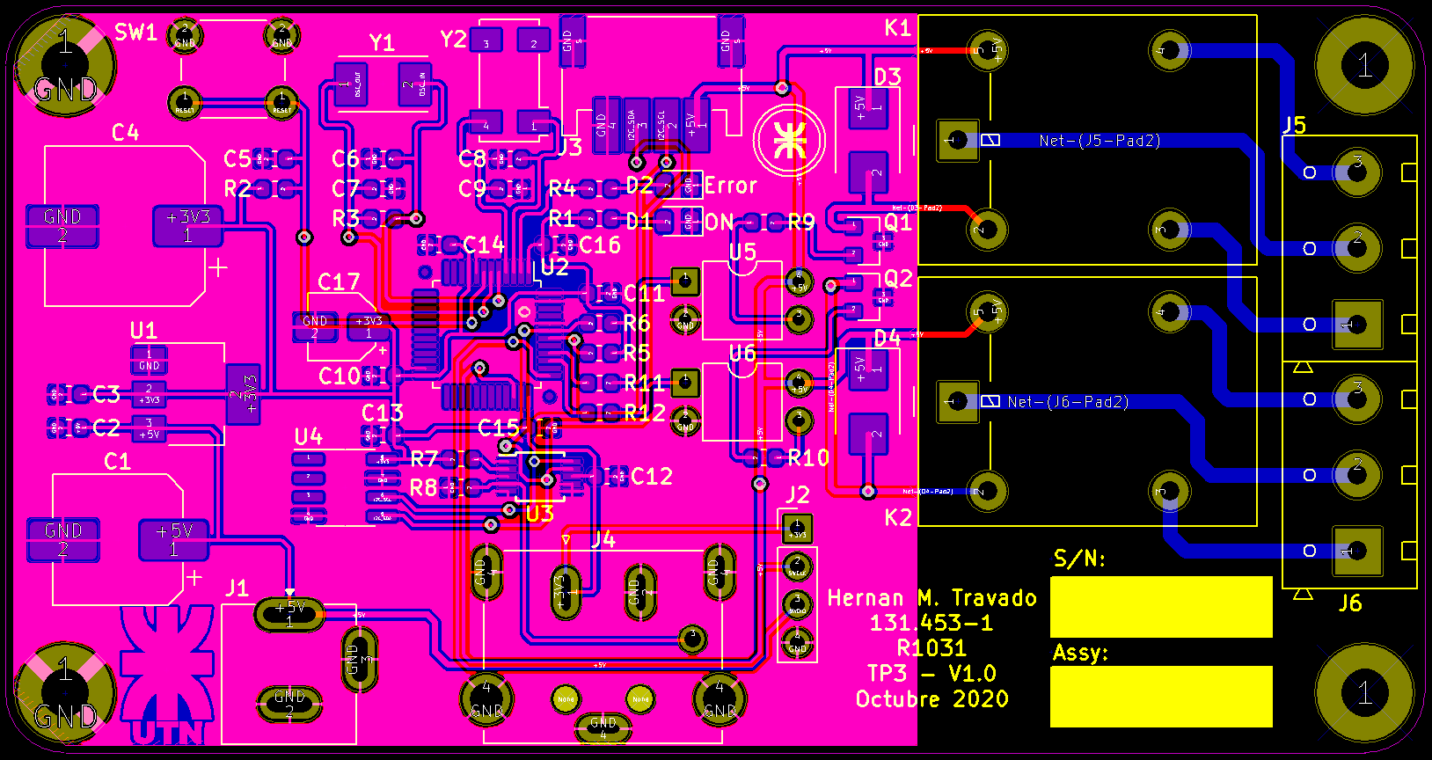
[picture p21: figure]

# Vista 3D de la placa terminada:

## Panel Frontal:

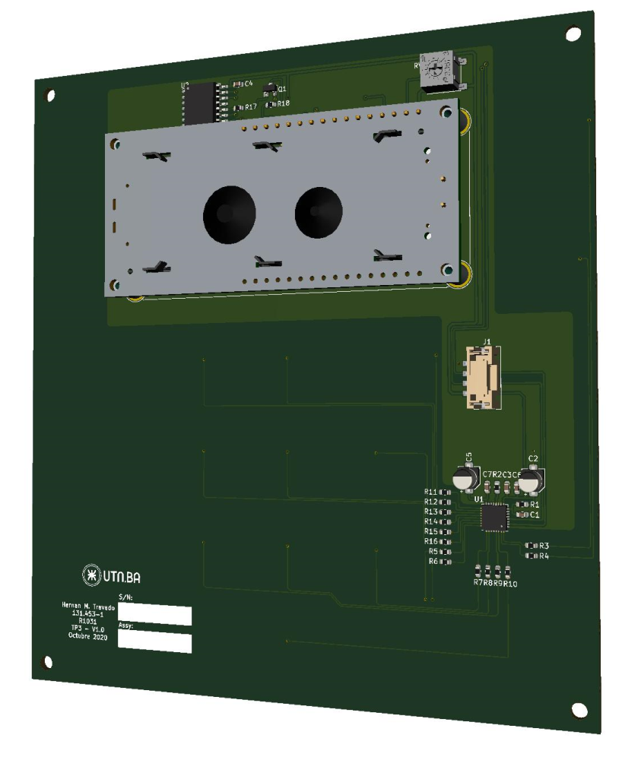
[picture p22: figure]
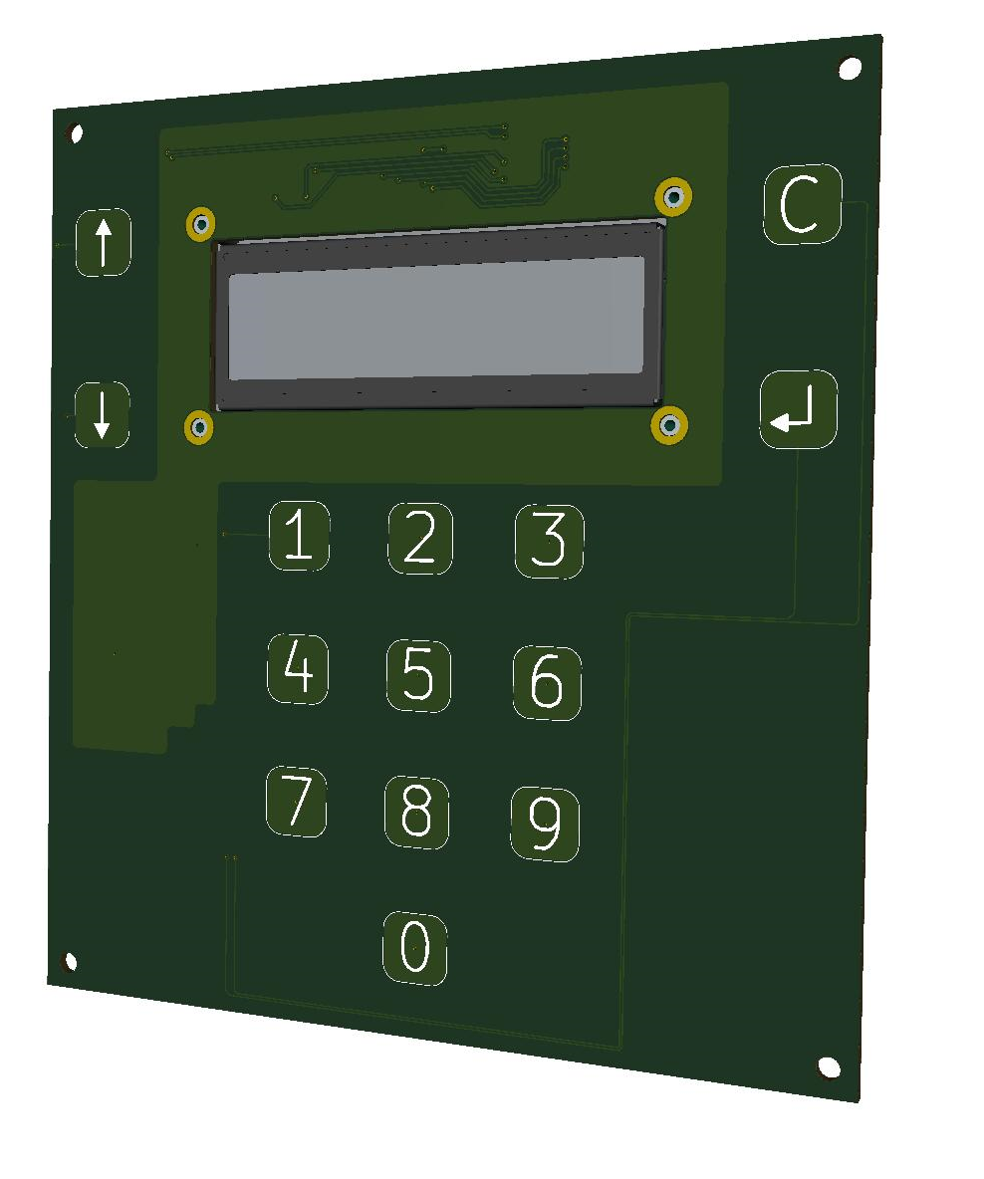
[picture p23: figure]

## Placa Base:

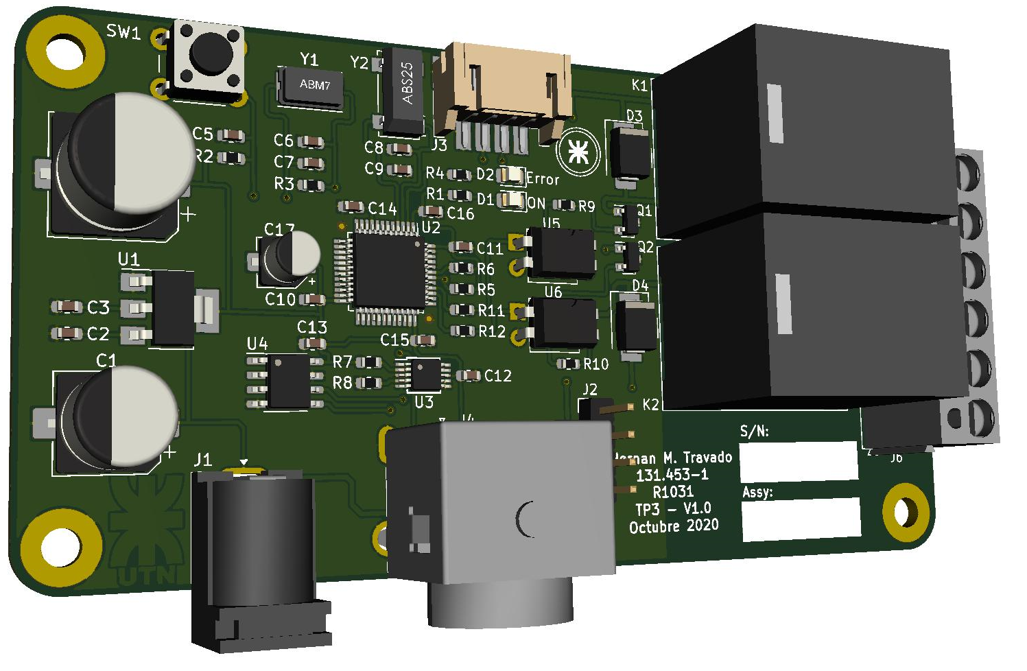
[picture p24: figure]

# Panelizado del PCB:

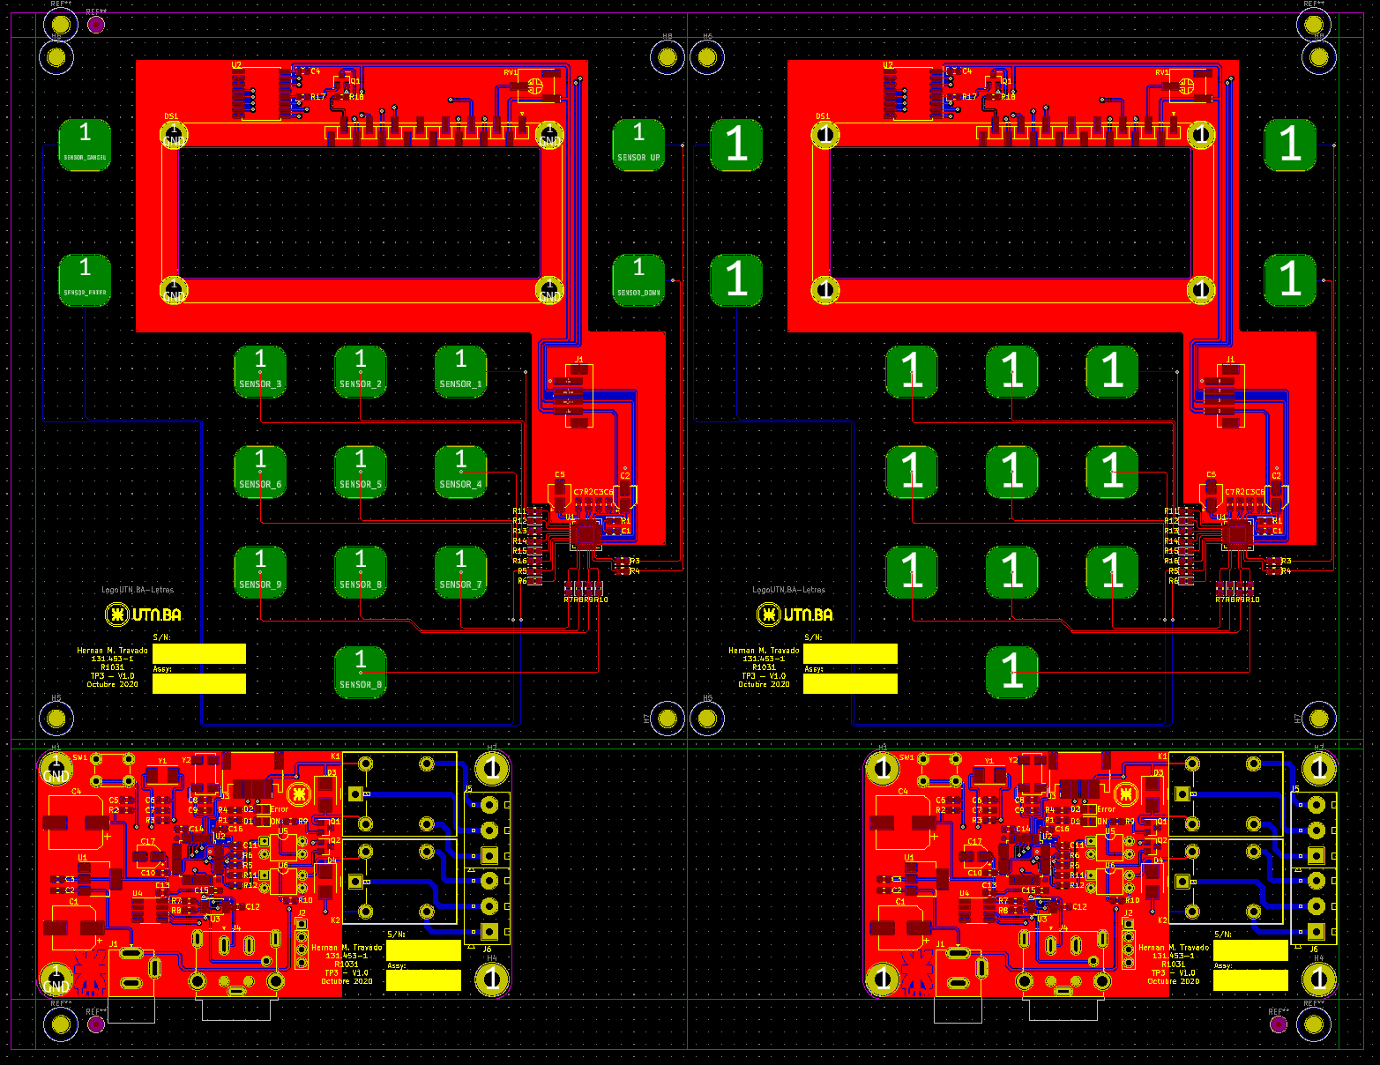
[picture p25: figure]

# Ejemplos de PCB y Overlay:

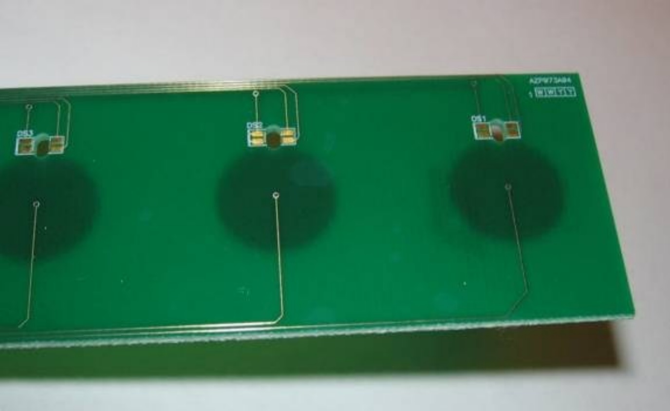
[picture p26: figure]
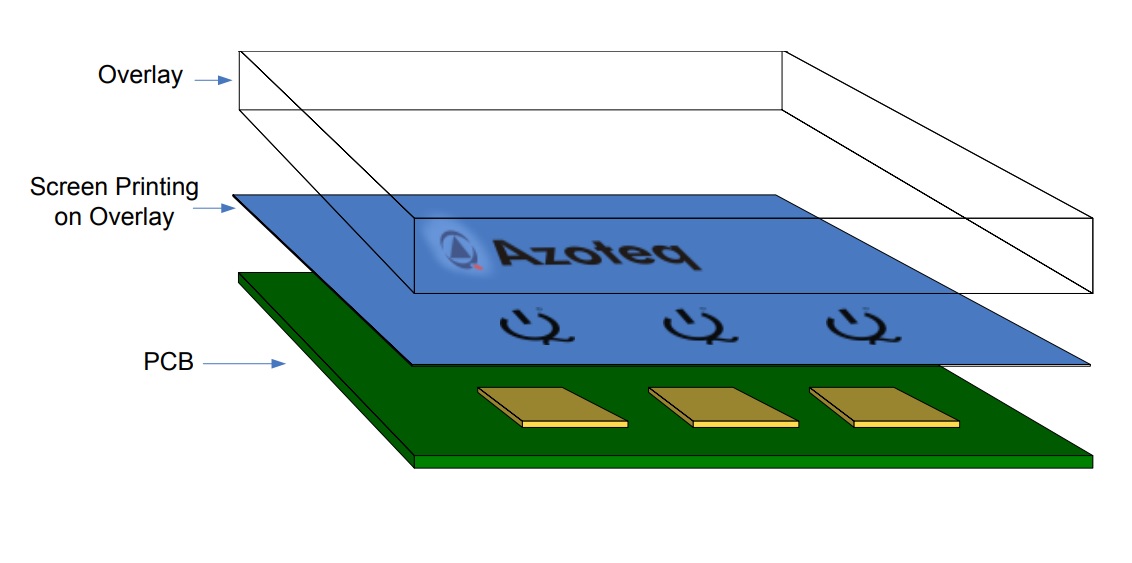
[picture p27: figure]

# Lista de Materiales (BOM):

Cant. | Valor | Fabricante | Numero de Parte
| Panel Frontal
3 | 0.1uF 16V | Samsung Electro-Mechanics | CL10B104KO8NNNC
2 | 1uF 16V | Panasonic Electronic Components | EEE-FC1V1R0R
2 | 100pF 50V | Samsung Electro-Mechanics | CL10C101JB8NNNC
1 | WC1602A | Newhaven Display Intl | NHD-0216K1Z-FL-YBW
4 | MountingHole_Pad | Wurth Elektronik | 9774070243R
1 | 620304124022 | Wurth Elektronik | 620304124022
1 | BC857B | ON Semiconductor | BC857BLT1G
1 | 2K2 5% | Yageo | RC0603JR-072K2L
1 | 39K 5% | Yageo | RC0603JR-0739KL
14 | 470R 5% | Yageo | RC0603JR-07100RL
1 | 680R 5% | Yageo | RC0603JR-07680RL
1 | 10R 5% | Yageo | RC0603JR-0710RL
1 | 10K 10% | Bourns Inc. | 3361P-1-103GLF
14 | PAD
1 | IQS316 | Azoteq (Pty) Ltd. | IQS316-0-QFR
1 | PCF8574A | NXP USA Inc. | PCF8574AT/3,518
| Placa Base
1 | 100uF 16V | Panasonic Electronic Components | EEE-HB1C101AP
10 | 0.1uF 16V | Samsung Electro-Mechanics | CL10B104KO8NNNC
1 | 330uF 16V | Panasonic Electronic Components | EEE-HB1C331AP
2 | 18pF 50V | Samsung Electro-Mechanics | CL10C180JB8NNNC
2 | 12pF 50V | Samsung Electro-Mechanics | CL10C120JB8NNNC
1 | 10uF 16V | Panasonic Electronic Components | EEE-HB1C100AR
1 | LTST-C171KRKT | Lite-On Inc. | LTST-C171KRKT
1 | LTST-C170KGKT | Lite-On Inc. | LTST-C170KGKT
2 | S1MB-13-F | Diodes Incorporated | S1MB-13-F
1 | PJ-002A | CUI Devices | PJ-002A
1 | 61300411121 | Wurth Elektronik | 61300411121
1 | 620104131822 | Wurth Elektronik | 620104131822
1 | PD-30S | CUI Devices | PD-30S
2 | OSTTA034163 | On Shore Technology Inc. | OSTTA034163
2 | G5LE-1 | Omron Electronics Inc-EMC Div | G5LE-14 DC5
2 | BC846B | ON Semiconductor | BC846BLT3G
2 | 180R 5% | Yageo | RC0603JR-07180RL
4 | 10K 5% | Yageo | AC0603JR-0710KL
1 | 10M 5% | Yageo | RC0603JR-0710ML
1 | 100R 0.1% | Yageo | RT0603BRD07100RL
2 | 680R 5% | Yageo | RC0603JR-07680RL
2 | 100R 5% | Yageo | RC0603JR-07100RL
1 | 1825910-6 | TE Connectivity ALCOSWITCH Switches | 1825910-6
1 | LD1117S33C | STMicroelectronics | LD1117S33CTR
1 | STM32F103C8Tx | STMicroelectronics | STM32F103C8T6TR
1 | ADS1115IDGS | Texas Instruments | ADS1115IDGSR
1 | 24LC16B | Microchip Technology | 24LC16BT-I/SN
2 | PC817 | SHARP/Socle Technology | PC81710NIP1B
1 | 8MHz | Abracon LLC | ABM7-8.000MHZ-D2Y-T
1 | 32.768K | Abracon LLC | ABS25-32.768KHZ-T

# Link a Octopart:

## Panel Frontal:

https://octopart.com/bom-tool/DTLM5kml

## Placa Base:

https://octopart.com/bom-tool/Puk0rRIS

# Checklist:

# | Ubicación de componentes | Comentarios | Cumple / No cumple / No aplica

1 | Orientación consistente de componentes SMD | | CUMPLE
2 | Espacio para herramientas de trabajo y extracción de ICs | | CUMPLE
3 | Verificar componentes polarizados | | CUMPLE
4 | Utilizar grilla de 50 mil (o 1.25mm) para componentes THT y 20 mils (o 0.5mm) para SMD | Se utilizó grilla de 0.25mm, Se alinearon todos los componentes respetando la misma separación | CUMPLE
5 | Verificar orientación de todos los conectores | | CUMPLE
6 | Verificar espacio mínimo entre cuerpo de componentes | | CUMPLE
7 | Capacitores de desacople (bypass) cerca de pines de alimentación de los IC | | CUMPLE
8 | Verificar terminadores en serie cercanos a la fuente | | CUMPLE
9 | Drivers I/O cercanos a donde las señales abandonan el PCB | | CUMPLE
10 | Pistas de alimentación y test points, todos etiquetados. | | CUMPLE
11 | Filtros EMI y RFI lo más cerca posible a puntos de entrada y salida en áreas blindadas. | No tiene filtro EMI ni RFI | NO APLICA
12 | Verificar que los potenciómetros incrementar la cantidad controlada en sentido de las agujas del reloj. | | CUMPLE
13 | Verificar si los orificios de montaje deben estar aislados eléctricamente o no. | | CUMPLE
14 | Verificar distancia de seguridad de los orificios de montaje hacia otros componentes. | | CUMPLE
15 | Verificar factor de forma de los pads SMD. | | CUMPLE
16 | Fiduciales locales y en panel para ensamble automático. | Se agregaron fiduciales locales en el microcontrolador por ser FP | CUMPLE
17 | Distancia de seguridad suficiente para ICs con zócalo. | No hay ICs con zócalos | NO APLICA
# | Ruteo/pistas | Comentarios | Cumple / No cumple / No aplica

18 | Comunes digitales y analógicos unidos en un solo punto. | | CUMPLE
19 | Verificar pistas debajo de componentes ruidosos o sensibles. | | CUMPLE
20 | No ubicar vías debajo de resistores de metalfilm u otros componentes con aislación pobre. | | CUMPLE
21 | Verificar pistas susceptibles a puentes de soldadura. | | CUMPLE
22 | Verificar pistas sin conexión en un extremo, a menos que sea a propósito. | | CUMPLE
23 | Asegurar que el CAD unifica o no señales Vcc/Vdd y Vss/GND según lo requiera el diseño. | | CUMPLE
24 | Utilizar múltiples vías en pistas de alta corriente y/o baja impedancia. | | CUMPLE
25 | Observar keepout de componentes y pistas. | No necesitamos keepout específicos en esta implementación | NO APLICA
26 | Utilizar planos de GND donde sea posible. | Se evitó usar plano de masa debajo de los relés para evitar cualquier cortocircuito con la tensión de la red | CUMPLE

# | Dimensiones | Comentarios | Cumple / No cumple / No aplica

27 | Diámetro de orificios debe considerar el metalizado. | | CUMPLE
28 | Diámetro de orificios más grande que el diámetro de pata al menos en 10 mils. | | CUMPLE
29 | Ancho de texto en silkscreen 0.20mm o más. | | CUMPLE
30 | Pad al menos 0.4mm más grande que drill. | | CUMPLE
31 | Componentes ubicados al menos a 1mm del borde del PCB. | | CUMPLE
32 | Test point ubicados al menos a 5mm del borde del PCB. | No utilizamos testpoints | NO APLICA
33 | Pistas al menos a 0.5mm del borde del PCB. | | CUMPLE
34 | Tolerancia de drills especificada. | | CUMPLE
35 | Tolerancia de máscara antisoldante especificada. | | CUMPLE
36 | Tolerancia de pistas especificada. | | CUMPLE
37 | Tolerancia de serigrafía especificada. | | CUMPLE
38 | Ancho de pista suficiente para la corriente que conduce. | | CUMPLE
39 | Distancia suficiente entre pistas de alto voltaje. | | CUMPLE
# | Serigrafía (silkscreen) | Comentarios | Cumple / No cumple / No aplica

40 | Evitar serigrafía sobre vías u orificios. | | CUMPLE
41 | Todos los textos y leyendas legibles en una o dos direcciones. | | CUMPLE
42 | Logo de la compañía en serigrafía y/o en cobre (logo de la facultad en nuestro caso) | | CUMPLE
43 | Nota de copyright en PCB. | No tiene un copyright especifico | NO CUMPLE
44 | Fecha en PCB. | | CUMPLE
45 | Número de parte en PCB. (En nuestro caso TP1/TP2, etc.) | | CUMPLE
46 | Revisión del PCB en serigrafía. (v1.0 o R01) | | CUMPLE
47 | Espacio para revisión de montaje en serigrafía. (ASSY) | | CUMPLE
48 | Espacio para número de serie en serigrafía. (S/N) | | CUMPLE
49 | Ubicar todo el texto de la serigrafía de manera tal que sea legible cuando los componentes están montados. | | CUMPLE
50 | Todos los ICs deben tener el pin 1 debidamente marcado y visible con el IC instalado. | | CUMPLE
51 | ICs de muchos pines deberían tener los pines extremos numerados para facilitar su identificación. | No tenemos ICs de muchos pines | NO APLICA
52 | Marcas cada 5 o 10 pines en ICs o conectores de muchos pines para facilitar su identificación. | No tenemos ICs de muchos pines | NO APLICA

# | Otros | Comentarios | Cumple / No cumple / No aplica

53 | Utilizar DRC y ERC habilitados en el CAD. (chequeo de errores en esquemático y PCB) | | CUMPLE
54 | Tomar las precauciones necesarias en circuitos de alta frecuencia. | | CUMPLE
55 | Colocar conectores y pines extra en prototipos para pruebas, por si es necesario. | Al ser una versión final no se consideraron necesarios | NO CUMPLE
56 | Verificar dimensiones y formas de orificios en conectores raros (rectangulares, ovalados). | | CUMPLE
57 | Verificar si la máscara antisoldante cubre o no cubre las vías. | | CUMPLE
58 | No rutear ángulos agudos. | | CUMPLE
59 | Verificar profundidad de la máscara antisoldante. | | CUMPLE
60 | Verificar el netlist manualmente o por inspección visual. | | CUMPLE
61 | Verificar si el origen de orificios es un pad de referencia. | | CUMPLE
62 | Anotar en layer auxiliar ancho del PCB, material y espesor del cobre. | | CUMPLE
63 | Utilizar aislamiento térmico (thermal relief) en capas internas de distribución de alimentación. | | CUMPLE
64 | Verificar que las aperturas para pasta de estaño sean del tamaño adecuado. | | CUMPLE
65 | Verificar si se permiten blind/buried vías en PCB multicapa. | No es un pcb multicapa | NO APLICA
66 | Definir correctamente el panelizado del PCB. | | CUMPLE
67 | Encapsulados metálicos de cristales de alta frecuencia deberían conectarse a GND. | Los cristales utilizados no tienen encapsulados metálicos | NO APLICA

# Gabinete:

## Planos de las piezas


## Vistas en 3D

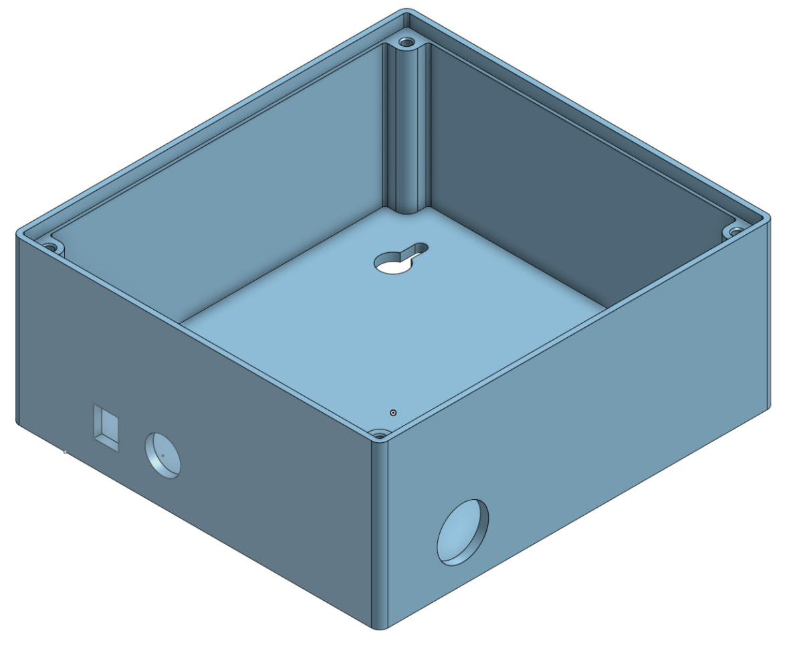
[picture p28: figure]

Gabinete - Base

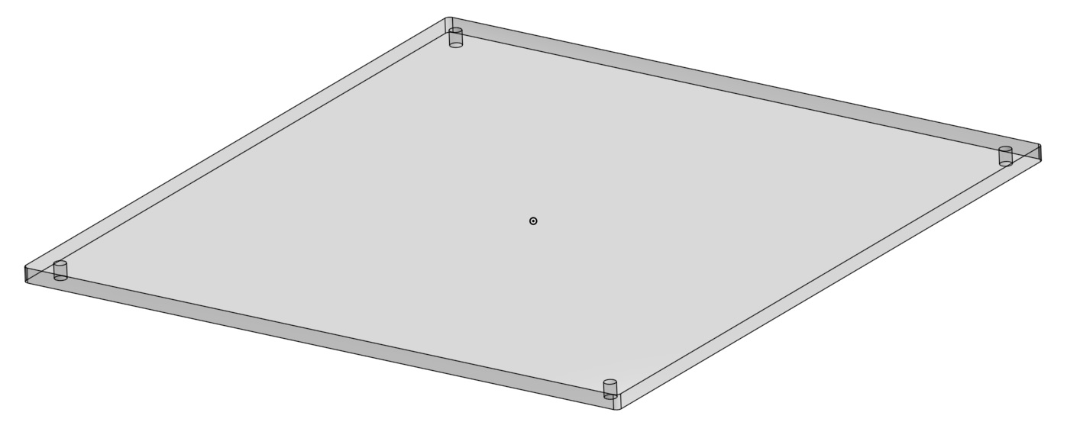
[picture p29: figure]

Gabinete – Frente Acrílico

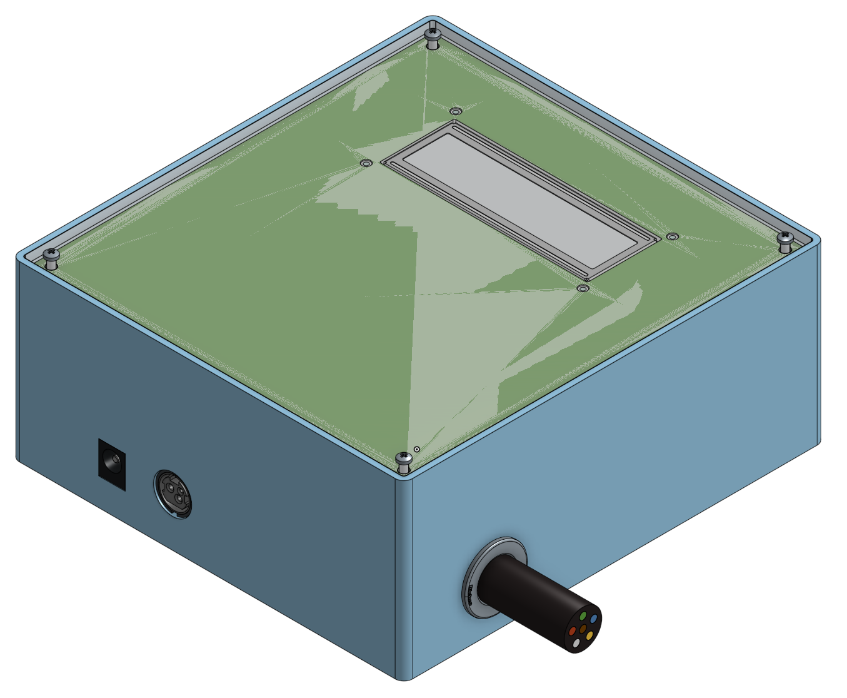
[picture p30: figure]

Gabinete – Ensamblaje

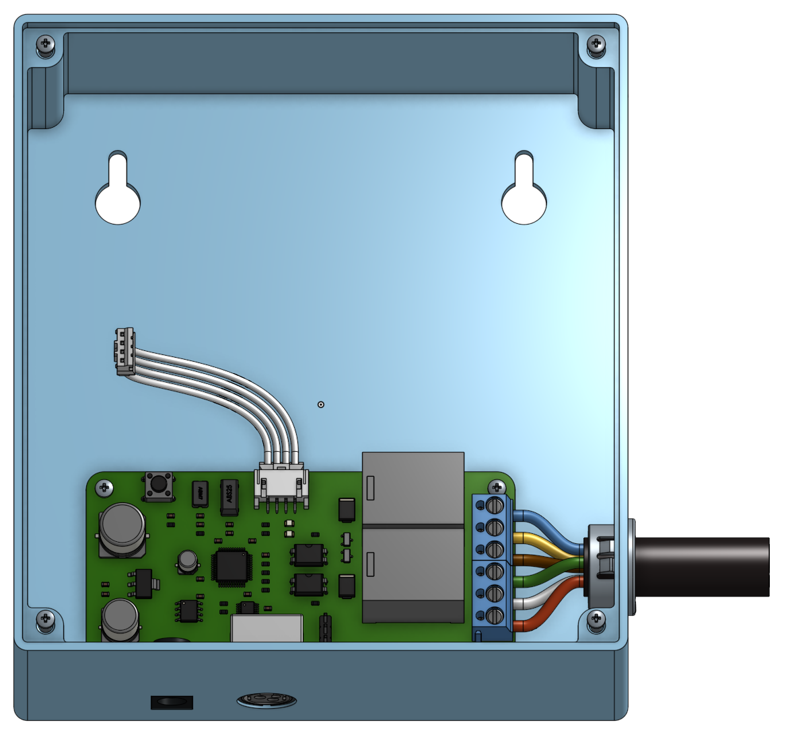
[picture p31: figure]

Gabinete – Vista Interior

# Link a ON-Shape:

https://cad.onshape.com/documents/e1ddf4852ee30d10dbbbdde3/w/8d886781dbbcdb7a099e42b0/e/7b9d0c14e845cfce50a3e853

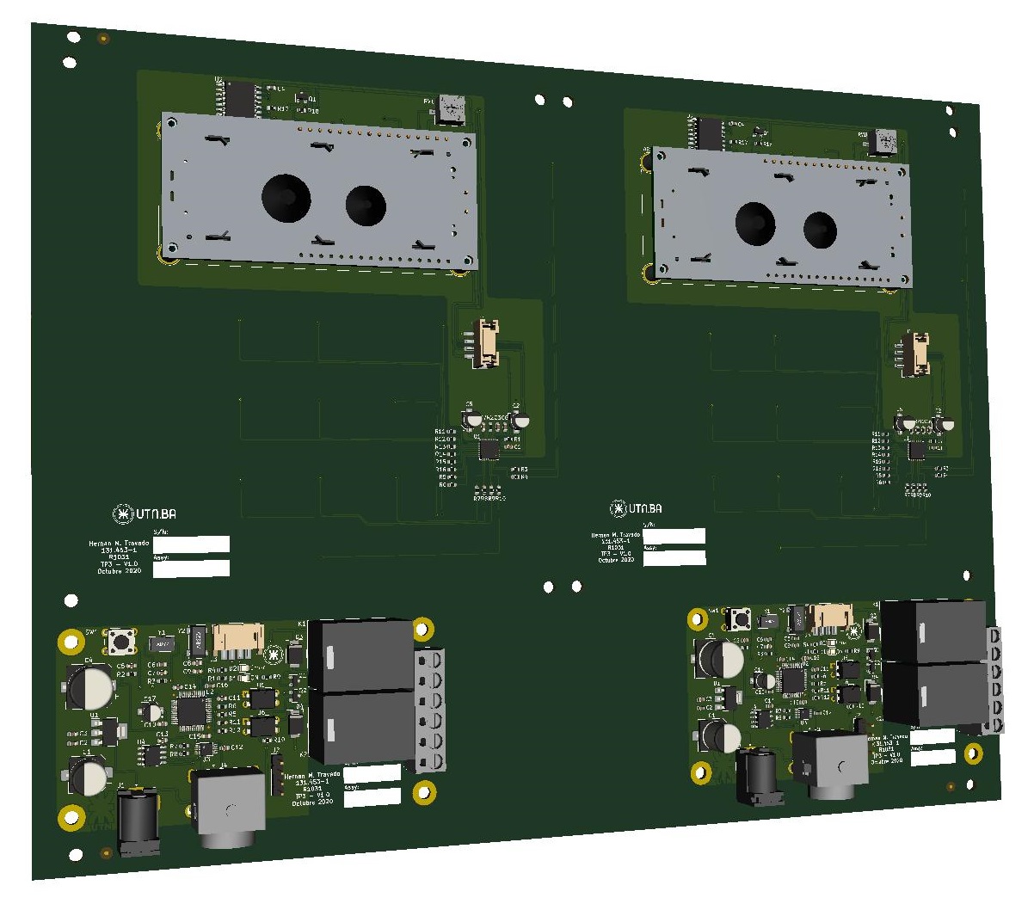
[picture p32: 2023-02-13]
Informe/Panelizado - 3D.jpg

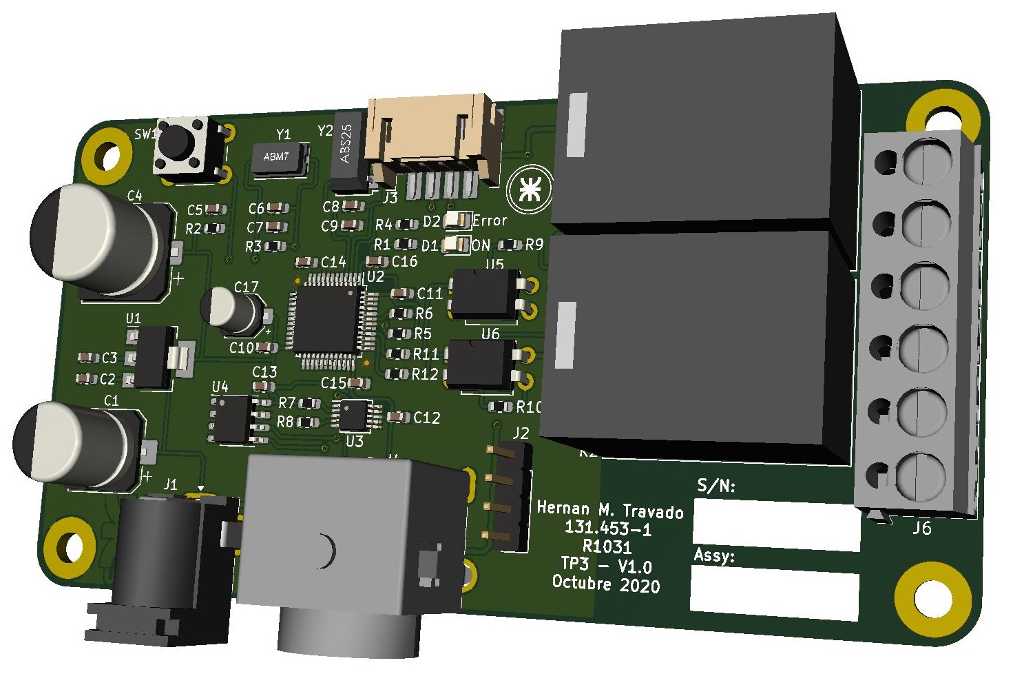
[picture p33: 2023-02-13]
Informe/PlacaBase-2.jpg

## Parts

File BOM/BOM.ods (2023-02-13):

Qty | Reference(s) | Value | Datasheet | Digikey P/N | Manufacturer | Manufacturer P/N | Notes
 | Panel Frontal
3 | C1, C3, C4 | 0.1uF 16V | https://media.digikey.com/pdf/Data%20Sheets/Samsung%20PDFs/CL_Series_MLCC_ds.pdf | 1276-1005-1-ND | Samsung Electro-Mechanics | CL10B104KO8NNNC
2 | C2, C5 | 1uF 16V | https://industrial.panasonic.com/cdbs/www-data/pdf/RDE0000/ABA0000C1172.pdf | PCE4024CT-ND | Panasonic Electronic Components | EEE-FC1V1R0R
2 | C6, C7 | 100pF 50V | https://media.digikey.com/pdf/Data%20Sheets/Samsung%20PDFs/CL_Series_MLCC_ds.pdf | 1276-1008-1-ND | Samsung Electro-Mechanics | CL10C101JB8NNNC
1 | DS1 | WC1602A | http://www.newhavendisplay.com/specs/NHD-0216K1Z-FL-YBW.pdf | NHD-0216K1Z-FL-YBW-ND | Newhaven Display Intl | NHD-0216K1Z-FL-YBW | Pin Header: 732-5369-ND
4 | H1, H2, H3, H4 | MountingHole_Pad | https://media.digikey.com/pdf/Data%20Sheets/Wurth%20Electronics%20PDFs/WA-SMSx_Performance_Flyer.pdf | 732-7107-1-ND | Wurth Elektronik | 9774070243R
1 | J1 | 620304124022 | https://katalog.we-online.de/em/datasheet/6203xx124022.pdf | 732-2709-1-ND | Wurth Elektronik | 620304124022 | Conector Hembra: 732-2874-ND (620004113322)
1 | Q1 | BC857B | http://www.onsemi.com/pub/Collateral/BC856ALT1-D.PDF | BC857BLT1GOSCT-ND | ON Semiconductor | BC857BLT1G
1 | R1 | 2K2 5% | https://www.yageo.com/upload/media/product/productsearch/datasheet/rchip/PYu-RC_Group_51_RoHS_L_11.pdf | 311-2.2KGRCT-ND | Yageo | RC0603JR-072K2L
1 | R2 | 39K 5% | https://www.yageo.com/upload/media/product/productsearch/datasheet/rchip/PYu-RC_Group_51_RoHS_L_11.pdf | 311-39KGRCT-ND | Yageo | RC0603JR-0739KL
14 | R3, R4, R5, R6, R7, R8, R9, R10, R11, R12, R13, R14, R15, R16 | 470R 5% | https://www.yageo.com/upload/media/product/productsearch/datasheet/rchip/PYu-RC_Group_51_RoHS_L_11.pdf | 311-100GRCT-ND | Yageo | RC0603JR-07100RL
1 | R17 | 680R 5% | https://www.yageo.com/upload/media/product/productsearch/datasheet/rchip/PYu-RC_Group_51_RoHS_L_11.pdf | 311-680GRCT-ND | Yageo | RC0603JR-07680RL
1 | R18 | 10R 5% | https://www.yageo.com/upload/media/product/productsearch/datasheet/rchip/PYu-RC_Group_51_RoHS_L_11.pdf | 311-10GRCT-ND | Yageo | RC0603JR-0710RL
1 | RV1 | 10K 10% | https://www.bourns.com/docs/Product-Datasheets/3361.pdf | 3361P-103GLFCT-ND | Bourns Inc. | 3361P-1-103GLF
14 | S1, S2, S3, S4, S5, S6, S7, S8, S9, S10, S11, S12, S13, S14 | PAD
1 | U1 | IQS316 | http://www.azoteq.com/images/stories/pdf/iqs316_datasheet.pdf | 1790-1042-1-ND | Azoteq (Pty) Ltd | IQS316-0-QFR | Application Note: https://www.azoteq.com/images/stories/pdf/azd008_design_guidelines_for_touchpads.pdf
1 | U2 | PCF8574A | https://www.nxp.com/docs/en/data-sheet/PCF8574_PCF8574A.pdf | 568-1074-1-ND | NXP USA Inc. | PCF8574AT/3,518
 | Placa Base
1 | C1 | 100uF 16V | https://industrial.panasonic.com/cdbs/www-data/pdf/RDE0000/ABA0000C1157.pdf | PCE4744CT-ND | Panasonic Electronic Components | EEE-HB1C101AP
10 | C2, C3, C5, C10, C11, C12, C13, C14, C15, C16 | 0.1uF 16V | https://media.digikey.com/pdf/Data%20Sheets/Samsung%20PDFs/CL_Series_MLCC_ds.pdf | 1276-1005-1-ND | Samsung Electro-Mechanics | CL10B104KO8NNNC
1 | C4 | 330uF 16V | https://industrial.panasonic.com/cdbs/www-data/pdf/RDE0000/ABA0000C1157.pdf | PCE4748CT-ND | Panasonic Electronic Components | EEE-HB1C331AP
2 | C6, C7 | 18pF 50V | https://media.digikey.com/pdf/Data%20Sheets/Samsung%20PDFs/CL_Series_MLCC_ds.pdf | 1276-1089-1-ND | Samsung Electro-Mechanics | CL10C180JB8NNNC
2 | C8, C9 | 12pF 50V | https://media.digikey.com/pdf/Data%20Sheets/Samsung%20PDFs/CL_Series_MLCC_ds.pdf | 1276-1254-1-ND | Samsung Electro-Mechanics | CL10C120JB8NNNC
1 | C17 | 10uF 16V | https://industrial.panasonic.com/cdbs/www-data/pdf/RDE0000/ABA0000C1157.pdf | PCE4743CT-ND | Panasonic Electronic Components | EEE-HB1C100AR
1 | D1 | LTST-C171KRKT | http://optoelectronics.liteon.com/upload/download/DS22-2000-109/LTST-C171KRKT.pdf | 160-1427-2-ND | Lite-On Inc. | LTST-C171KRKT | Led Rojo
1 | D2 | LTST-C170KGKT | http://optoelectronics.liteon.com/upload/download/DS22-2000-109/LTST-C171KRKT.pdf | 160-1414-1-ND | Lite-On Inc. | LTST-C170KGKT | Led Verde
2 | D3, D4 | S1MB-13-F | https://www.diodes.com/assets/Datasheets/ds16003.pdf | S1MB-FDICT-ND | Diodes Incorporated | S1MB-13-F
1 | J1 | PJ-002A | https://www.cuidevices.com/product/resource/digikeypdf/pj-002a.pdf | CP-002A-ND | CUI Devices | PJ-002A
1 | J2 | 61300411121 | https://katalog.we-online.de/em/datasheet/6130xx11121.pdf | 732-5317-ND | Wurth Elektronik | 61300411121
1 | J3 | 620104131822 | https://katalog.we-online.de/em/datasheet/6201xx131822.pdf | 732-2713-1-ND | Wurth Elektronik | 620104131822 | Conector Hembra: 732-2874-ND (620004113322)
1 | J4 | PD-30S | https://www.cuidevices.com/product/resource/digikeypdf/pd-30s.pdf | CP-7230-ND | CUI Devices | PD-30S | Plug: https://www.digikey.com/product-detail/en/cui-devices/PDP-30/CP-7330-ND/2119403
2 | J5, J6 | OSTTA034163 | https://www.on-shore.com/wp-content/uploads/OSTTAXX4163.pdf | ED2581-ND | On Shore Technology Inc. | OSTTA034163
2 | K1, K2 | G5LE-1 | http://www.omron.com/ecb/products/pdf/en-g5le.pdf | Z1011-ND | Omron Electronics Inc-EMC Div | G5LE-14 DC5
2 | Q1, Q2 | BC846B | http://www.onsemi.com/pub/Collateral/BC846ALT1-D.PDF | BC846BLT3GOSCT-ND | ON Semiconductor | BC846BLT3G
2 | R1, R4 | 180R 5% | https://www.yageo.com/upload/media/product/productsearch/datasheet/rchip/PYu-RC_Group_51_RoHS_L_11.pdf | 311-180GRCT-ND | Yageo | RC0603JR-07180RL
4 | R2, R5, R6, R7 | 10K 5% | https://www.yageo.com/upload/media/product/productsearch/datasheet/rchip/PYu-AC_51_RoHS_L_7.pdf | 311-10KLECT-ND | Yageo | AC0603JR-0710KL
1 | R3 | 10M 5% | https://www.yageo.com/upload/media/product/productsearch/datasheet/rchip/PYu-RC_Group_51_RoHS_L_11.pdf | 311-10MGRCT-ND | Yageo | RC0603JR-0710ML
1 | R8 | 100R 0.1% | https://www.yageo.com/upload/media/product/productsearch/datasheet/rchip/PYu-RT_1-to-0.01_RoHS_L_11.pdf | YAG1497DKR-ND | Yageo | RT0603BRD07100RL
2 | R9, R10 | 680R 5% | https://www.yageo.com/upload/media/product/productsearch/datasheet/rchip/PYu-RC_Group_51_RoHS_L_11.pdf | 311-680GRCT-ND | Yageo | RC0603JR-07680RL
2 | R11, R12 | 100R 5% | https://www.yageo.com/upload/media/product/productsearch/datasheet/rchip/PYu-RC_Group_51_RoHS_L_11.pdf | 311-100GRCT-ND | Yageo | RC0603JR-07100RL
1 | SW1 | 1825910-6 | https://www.te.com/commerce/DocumentDelivery/DDEController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 | 450-1650-ND | TE Connectivity ALCOSWITCH Switches | 1825910-6
1 | U1 | LD1117S33C | https://www.st.com/content/ccc/resource/technical/document/datasheet/99/3b/7d/91/91/51/4b/be/CD00000544.pdf/files/CD00000544.pdf/jcr:content/translations/en.C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 | 497-1241-1-ND | STMicroelectronics | LD1117S33CTR
1 | U2 | STM32F103C8Tx | https://www.st.com/resource/en/datasheet/stm32f103cb.pdf | 497-17666-1-ND | STMicroelectronics | STM32F103C8T6TR
1 | U3 | ADS1115IDGS | http://www.ti.com/lit/ds/symlink/ads1113.pdf | 296-38849-1-ND | Texas Instruments | ADS1115IDGSR
1 | U4 | 24LC16B | https://ww1.microchip.com/downloads/en/DeviceDoc/20001703M.pdf | 24LC16BT-I/SNCT-ND | Microchip Technology | 24LC16BT-I/SN
2 | U5, U6 | PC817 | https://media.digikey.com/pdf/Data%20Sheets/Sharp%20PDFs/PC817_Spec.pdf | 425-2763-ND | SHARP/Socle Technology | PC817X1NSZ0F
1 | Y1 | 8MHz | https://abracon.com/Resonators/abm7.pdf | 535-9831-1-ND | Abracon LLC | ABM7-8.000MHZ-D2Y-T
1 | Y2 | 32.768K | https://abracon.com/Resonators/abs25.pdf | 535-9166-1-ND | Abracon LLC | ABS25-32.768KHZ-T

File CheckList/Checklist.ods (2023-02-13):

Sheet: Completa
# | Ubicación de componentes | Comentarios | Cumple / No cumple / No aplica
1 | Orientación consistente de componentes SMD |  | CUMPLE
2 | Espacio para herramientas de retrabajo y extraccion de ICs |  | CUMPLE
3 | Verificar componentes polarizados |  | CUMPLE
4 | Utilizar grilla de 50 mil (o 1.25mm) para componentes THT y 20 mils (o 0.5mm) para SMD | Se utilizo grilla de 0.25mm, Se alinearon todos los componentes respetando la misma separacion | CUMPLE
5 | Verificar orientación de todos los conectores |  | CUMPLE
6 | Verificar espacio mínimo entre cuerpo de componentes |  | CUMPLE
7 | Capacitores de desacople (bypass) cerca de pines de alimentación de los IC |  | CUMPLE
8 | Verificar terminadores en serie cercanos a la fuente |  | CUMPLE
9 | Drivers I/O cercanos a donde las señales abandonan el PCB |  | CUMPLE
10 | Pistas de alimentación y test points, todos etiquetados. |  | CUMPLE
11 | Filtros EMI y RFI lo más cerca posible a puntos de entrada y salida en áreas blindadas. | No tiene filtro EMI ni RFI | NO APLICA
12 | Verificar que los potenciómetros incrementar la cantidad controlada en sentido de las agujas del reloj. |  | CUMPLE
13 | Verificar si los orificios de montaje deben estar aislados eléctricamente o no. |  | CUMPLE
14 | Verificar distancia de seguridad de los orificios de montaje hacia otros componentes. |  | CUMPLE
15 | Verificar factor de forma de los pads SMD. |  | CUMPLE
16 | Fiduciales locales y en panel para ensamle automático. | Se agregaron fiduciales locales en el microcontrolador por ser FP | CUMPLE
17 | Distancia de seguridad suficiente para ICs con zócalo. | No hay ICs con zocalos | NO APLICA
# | Ruteo/pistas | Comentarios | Cumple / No cumple / No aplica
18 | Comunes digitales y analógicos unidos en un solo punto. |  | CUMPLE
19 | Verificar pistas debajo de componentes ruidosos o sensibles. |  | CUMPLE
20 | No ubicar vias debajo de resistores de metalfilm u otros componentes con aislación pobre. |  | CUMPLE
21 | Verificar pistas susceptibles a puentes de soldadura. |  | CUMPLE
22 | Verificar pistas sin conexión en un extremo, a menos que sea a propósito. |  | CUMPLE
23 | Asegurar que el CAD unifica o no señales Vcc/Vdd y Vss/GND según lo requiera el diseño. |  | CUMPLE
24 | Utilizar múltiples vías en pistas de alta corriente y/o baja impedancia. |  | CUMPLE
25 | Observar keepout de componentes y pistas. | No necesitamos keepout especificos en esta implementacion | NO APLICA
26 | Utilizar planos de GND donde sea posible. | Se evito usar plano de masas debajos de los reles para evitar cualquier cortocircuito con la tension de la red | CUMPLE
# | Dimensiones | Comentarios | Cumple / No cumple / No aplica
27 | Diámetro de orificios debe considerar el metalizado. |  | CUMPLE
28 | Diámetro de orificios más grande que el diámetro de pata al menos en 10 mils. |  | CUMPLE
29 | Ancho de texto en silkscreen 0.20mm o más. |  | CUMPLE
30 | Pad al menos 0.4mm más grande que drill. |  | CUMPLE
31 | Componentes ubicados al menos a 1mm del borde del PCB. |  | CUMPLE
32 | Test point ubicados al menos a 5mm del borde del PCB. | No utilizamos testpoints | NO APLICA
33 | Pistas al menos a 0.5mm del borde del PCB. |  | CUMPLE
34 | Tolerancia de drills especificada. |  | CUMPLE
35 | Tolerancia de máscara antisoldante especificada. |  | CUMPLE
36 | Tolerancia de pistas especificada. |  | CUMPLE
37 | Tolerancia de serigrafía especificada. |  | CUMPLE
38 | Ancho de pista suficiente para la corriente que conduce. |  | CUMPLE
39 | Distancia suficiente entre pistas de alto voltaje. |  | CUMPLE
# | Serigrafía (silkscreen) | Comentarios | Cumple / No cumple / No aplica
40 | Evitar serigrafía sobre vías u orificios. |  | CUMPLE
41 | Todos los textos y leyendas legibles en una o dos direcciones. |  | CUMPLE
42 | Logo de la compañía en serigrafía y/o en cobre (logo de la facultad en nuestro caso) |  | CUMPLE
43 | Nota de copyright en PCB. | No tiene un copyright especifico | NO CUMPLE
44 | Fecha en PCB. |  | CUMPLE
45 | Número de parte en PCB. (en nuesto caso TP1/TP2, etc) |  | CUMPLE
46 | Revisión del PCB en serigrafía. (v1.0 o R01) |  | CUMPLE
47 | Espacio para revisión de montaje en serigrafía. (ASSY) |  | CUMPLE
48 | Espacio para número de serie en serigrafía. (S/N) |  | CUMPLE
49 | Ubicar todo el texto de la serigrafía de manera tal que sea legible cuando los componentes están montados. |  | CUMPLE
50 | Todos los ICs deben tener el pin 1 debidamente marcado y visible con el IC instalado. |  | CUMPLE
51 | ICs de muchos pines deberían tener los pines extremos numerados para facilitar su identificación. | No tenemos ICs de muchos pines | NO APLICA
52 | Marcas cada 5 o 10 pines en ICs o conectores de muchos pines para facilitar su identificación. | No tenemos ICs de muchos pines | NO APLICA
# | Otros | Comentarios | Cumple / No cumple / No aplica
53 | Utilizar DRC y ERC habilitados en el CAD. (chequeo de errores en esquemático y PCB) |  | CUMPLE
54 | Tomar las precauciones necesarias en circuitos de alta frecuencia. |  | CUMPLE
55 | Colocar conectores y pines extra en prototipos para pruebas, por si es necesario. | Al ser una version final no se consideraron necesarios | NO CUMPLE
56 | Verificar dimensiones y formas de orificios en conectores raros (rectangulares, ovalados). |  | CUMPLE
57 | Verificar si la máscara antisoldante cubre o no cubre las vías. |  | CUMPLE
58 | No rutear ángulos agudos. |  | CUMPLE
59 | Verificar profundidad de la máscara antisoldante. |  | CUMPLE
60 | Verificar el netlist manualmente o por inspección visual. |  | CUMPLE
61 | Verificar si el origen de orificios es un pad de referencia. |  | CUMPLE
62 | Anotar en layer auxiliar ancho del PCB, material y espesor del cobre. |  | CUMPLE
63 | Utilizar aislamiento térmico (thermal relief) en capas internas de distribución de alimentación. |  | CUMPLE
64 | Verificar que las aperturas para pasta de estaño sean del tamaño adecuado. |  | CUMPLE
65 | Verificar si se permiten blind/buried vias en PCB multicapa. | No es un pcb multicapa | NO APLICA
66 | Definir correctamente el panelizado del PCB. |  | CUMPLE
67 | Encapsulados metálicos de cristales de alta frecuencia deberían conectarse a GND. | Los cristales utilizados no tienen encapsulados metalicos | NO APLICA

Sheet: Reducida
# | Ubicación de componentes | Comentarios | Cumple / No cumple / No aplica
1 | Orientación consistente de componentes SMD
2 | Espacio para herramientas de retrabajo y extraccion de ICs
3 | Verificar componentes polarizados
4 | Utilizar grilla de 50 mil (o 1.25mm) para componentes THT y 20 mils (o 0.5mm) para SMD
5 | Verificar orientación de todos los conectores
6 | Verificar espacio mínimo entre cuerpo de componentes
7 | Capacitores de desacople (bypass) cerca de pines de alimentación de los IC
8 | Pistas de alimentación y test points, todos etiquetados.
9 | Verificar que los potenciómetros incrementar la cantidad controlada en sentido de las agujas del reloj.
10 | Verificar distancia de seguridad de los orificios de montaje hacia otros componentes.
11 | Fiduciales locales y en panel para ensamle automático.
# | Ruteo/pistas | Comentarios | Cumple / No cumple / No aplica
12 | Verificar pistas debajo de componentes ruidosos o sensibles.
13 | Verificar pistas sin conexión en un extremo, a menos que sea a propósito.
14 | Utilizar múltiples vías en pistas de alta corriente y/o baja impedancia.
15 | Observar keepout de componentes y pistas.
16 | Utilizar planos de GND donde sea posible.
# | Dimensiones | Comentarios | Cumple / No cumple / No aplica
17 | Ancho de texto en silkscreen 0.20mm o más.
18 | Componentes ubicados al menos a 1mm del borde del PCB.
19 | Test point ubicados al menos a 5mm del borde del PCB.
20 | Pistas al menos a 0.5mm del borde del PCB.
21 | Ancho de pista suficiente para la corriente que conduce.
# | Serigrafía (silkscreen) | Comentarios | Cumple / No cumple / No aplica
22 | Evitar serigrafía sobre vías u orificios.
23 | Todos los textos y leyendas legibles en una o dos direcciones.
24 | Logo de la compañía en serigrafía y/o en cobre (logo de la facultad en nuestro caso)
25 | Nota de copyright en PCB.
26 | Fecha en PCB.
27 | Número de parte en PCB. (en nuesto caso TP1/TP2, etc)
28 | Revisión del PCB en serigrafía. (v1.0 o R01)
29 | Espacio para revisión de montaje en serigrafía. (ASSY)
30 | Espacio para número de serie en serigrafía. (S/N)
31 | Ubicar todo el texto de la serigrafía de manera tal que sea legible cuando los componentes están montados.
32 | Todos los ICs deben tener el pin 1 debidamente marcado y visible con el IC instalado.
33 | ICs de muchos pines deberían tener los pines extremos numerados para facilitar su identificación.
34 | Marcas cada 5 o 10 pines en ICs o conectores de muchos pines para facilitar su identificación.
# | Otros | Comentarios | Cumple / No cumple / No aplica
35 | Utilizar DRC y ERC habilitados en el CAD. (chequeo de errores en esquemático y PCB)
36 | Verificar si la máscara antisoldante cubre o no cubre las vías.
37 | No rutear ángulos agudos.
38 | Anotar en layer auxiliar ancho del PCB, material y espesor del cobre.
39 | Utilizar aislamiento térmico (thermal relief) en capas internas de distribución de alimentación.
40 | Definir correctamente el panelizado del PCB.

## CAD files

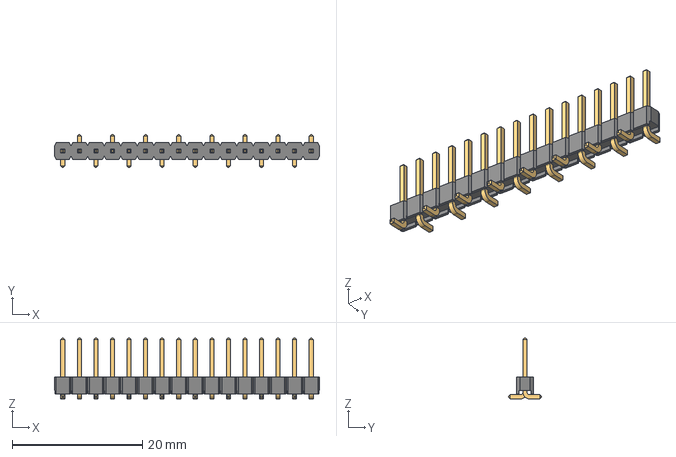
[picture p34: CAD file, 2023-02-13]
Panelizado/modelos3D/NREC016SABC.stp
40.6 x 5.00 x 9.33 mm
6100xx18221_PIN x 16

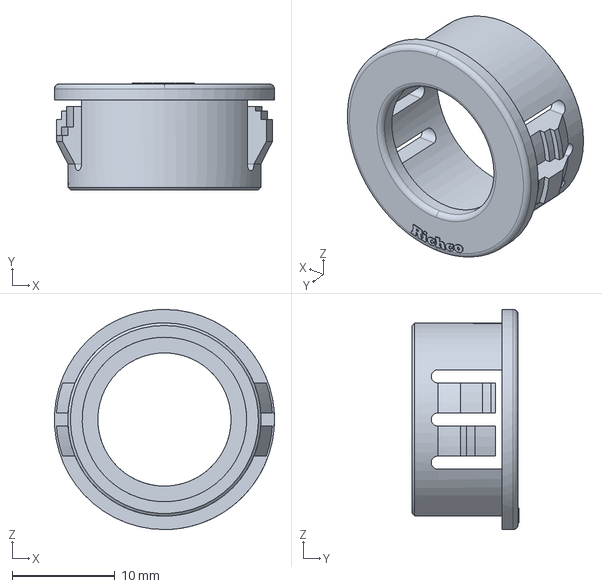
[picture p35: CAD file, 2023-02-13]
PlacaBase/modelos3D/PGSB-22.stp
21.4 x 10.4 x 21.4 mm

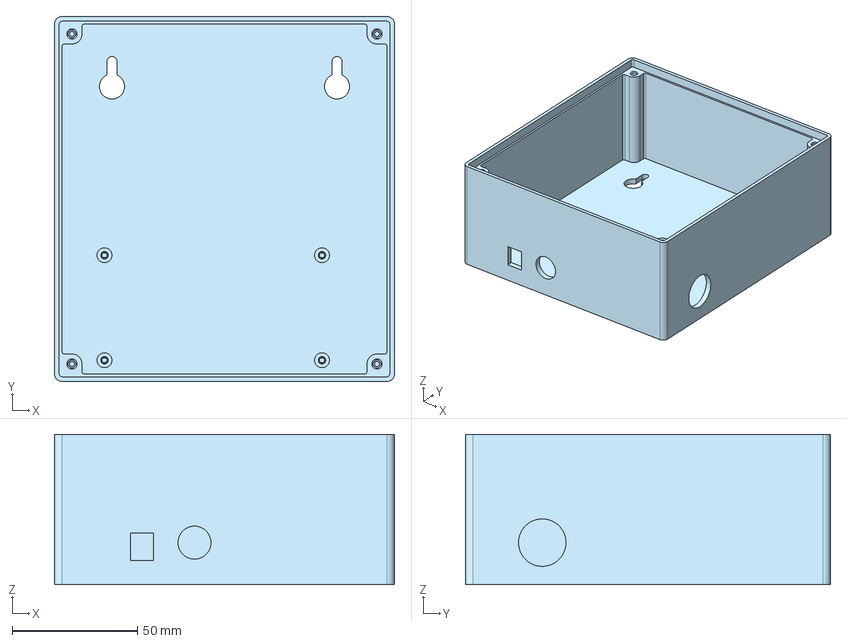
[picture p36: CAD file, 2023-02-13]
Gabinete/Gabinete - Base.step
136.0 x 146.0 x 60.0 mm

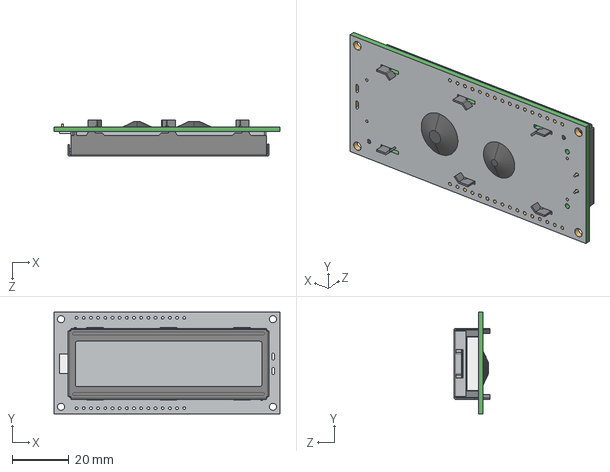
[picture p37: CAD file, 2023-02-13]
Panelizado/modelos3D/NHD-0216.STEP
80.0 x 36.0 x 12.7 mm

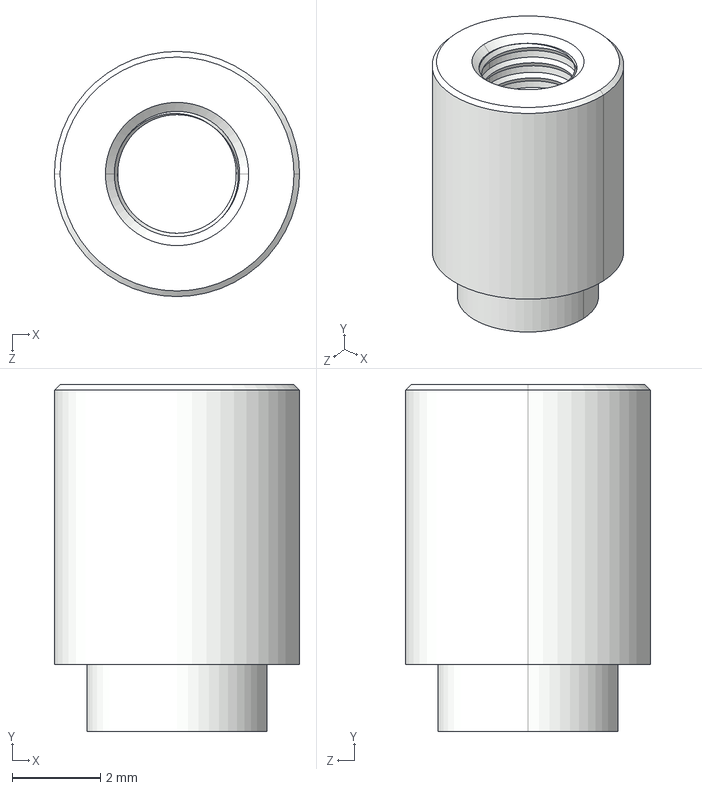
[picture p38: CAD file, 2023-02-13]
PlacaBase/modelos3D/keystone-4883.STEP
5.56 x 7.87 x 5.56 mm

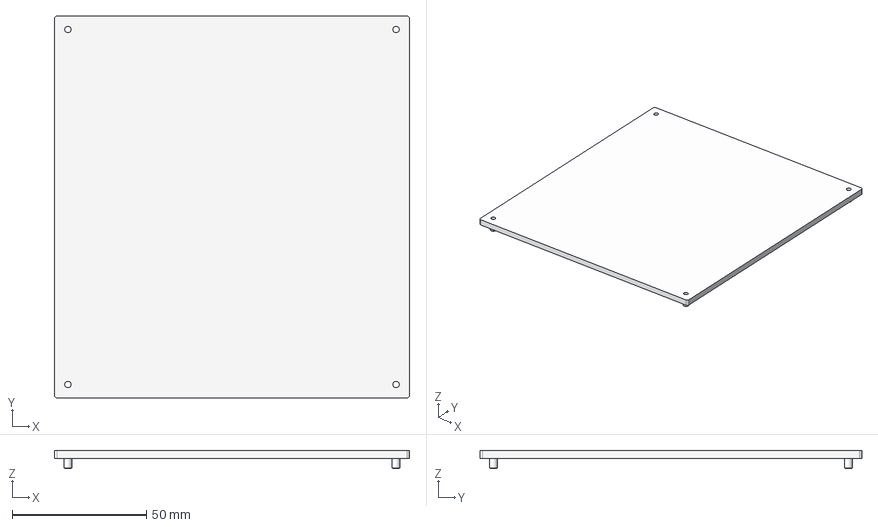
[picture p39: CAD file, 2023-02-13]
Gabinete/Gabinete - Frente Acrilico.step
132.0 x 142.0 x 6.80 mm

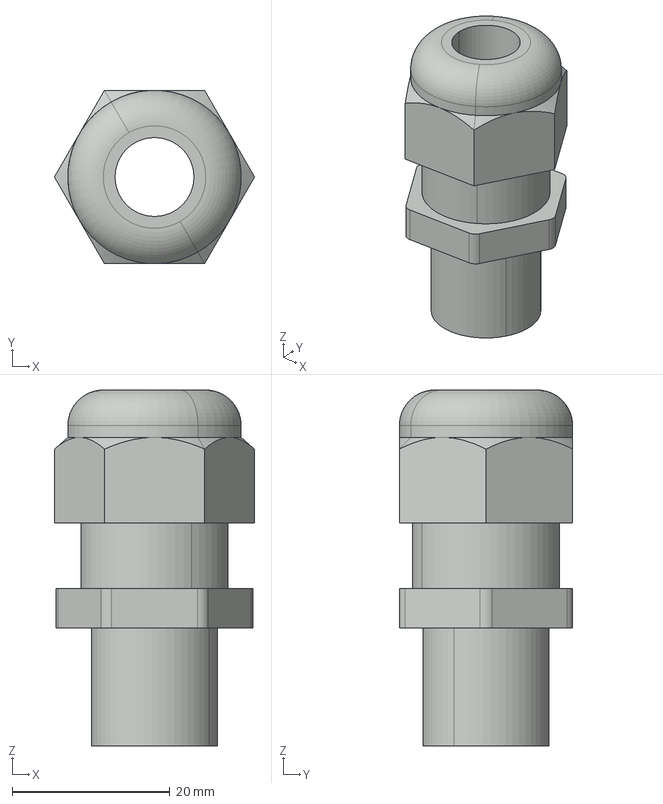
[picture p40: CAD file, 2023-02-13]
Panelizado/modelos3D/prensacable.stp
25.4 x 22.0 x 45.2 mm

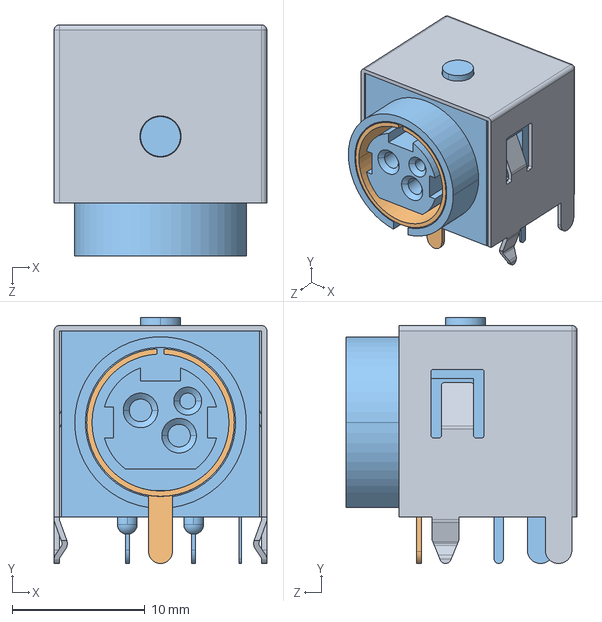
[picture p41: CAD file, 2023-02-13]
PlacaBase/modelos3D/CUI_DEVICES_PD-30S.step
16.0 x 18.5 x 17.4 mm

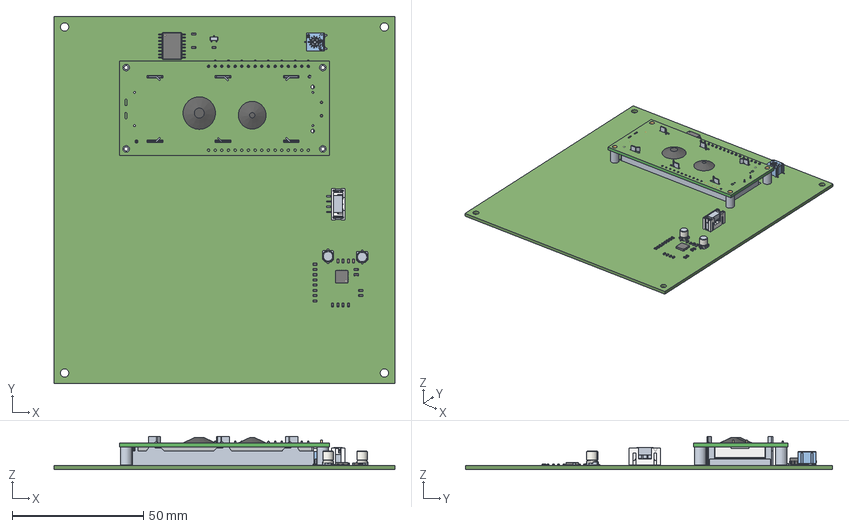
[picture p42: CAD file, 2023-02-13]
Gabinete/PCB - PanelFrontal.step
130.0 x 140.0 x 12.7 mm

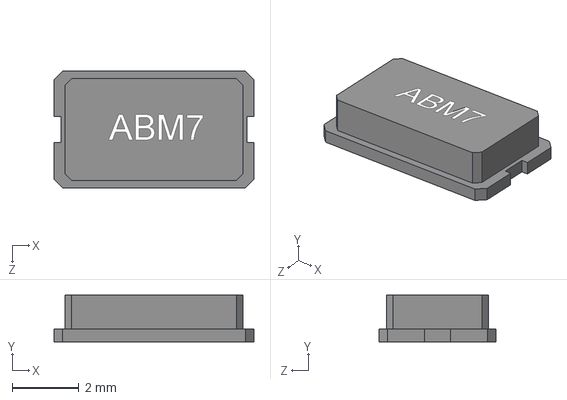
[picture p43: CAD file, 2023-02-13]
PlacaBase/modelos3D/ABM7.STEP
5.99 x 1.40 x 3.51 mm

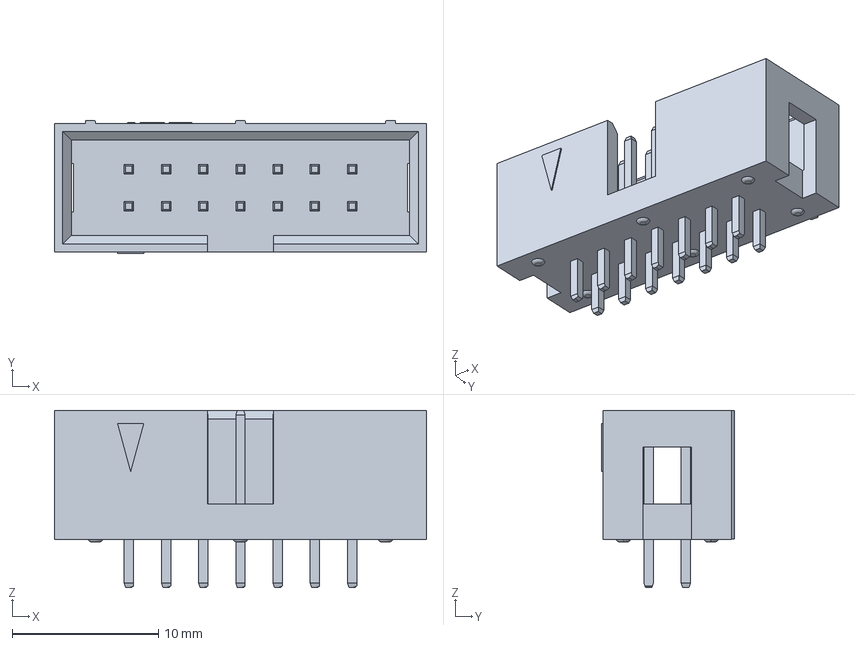
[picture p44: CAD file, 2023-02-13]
PlacaBase/modelos3D/302-S141.step
25.4 x 9.10 x 12.1 mm

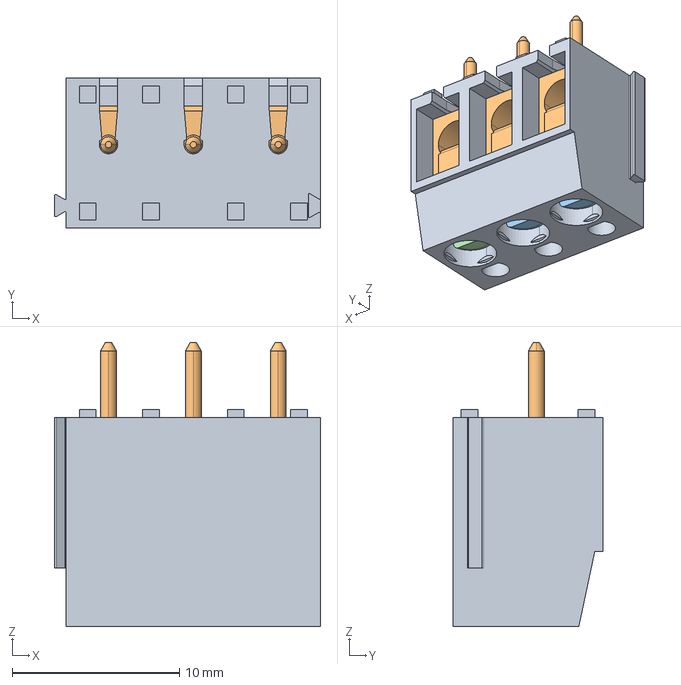
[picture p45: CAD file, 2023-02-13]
Panelizado/modelos3D/OSTTA034163.stp
15.9 x 9.00 x 17.0 mm

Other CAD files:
Gabinete/PGSB-22.step
Gabinete/620004113322.step
Gabinete/Cross recessed pan head tapping screw ST2.2x16.step
Gabinete/Cross recessed pan head tapping screw ST2.2x4.5.step
Gabinete/PH Pan head screw M2x0.40 x 6.step
PanelFrontal/modelos3D/3361p001.stp
PanelFrontal/modelos3D/3362F001XXX0A.stp
PanelFrontal/modelos3D/620104131822.stp
PanelFrontal/modelos3D/620304124022.stp
PanelFrontal/modelos3D/9774070243R.stp
Panelizado/modelos3D/3361p001.stp
Panelizado/modelos3D/3362F001XXX0A.stp
Panelizado/modelos3D/620104131822.stp
Panelizado/modelos3D/620304124022.stp
Panelizado/modelos3D/9774070243R.stp
Panelizado/modelos3D/ABS25.STEP
Panelizado/modelos3D/Omron-G5LE-14.step
Panelizado/modelos3D/PJ-002A.step
PlacaBase/modelos3D/3362F001XXX0A.stp
PlacaBase/modelos3D/620104131822.stp
PlacaBase/modelos3D/9774070243R.stp
PlacaBase/modelos3D/ABS25.STEP
PlacaBase/modelos3D/Omron-G5LE-14.step
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

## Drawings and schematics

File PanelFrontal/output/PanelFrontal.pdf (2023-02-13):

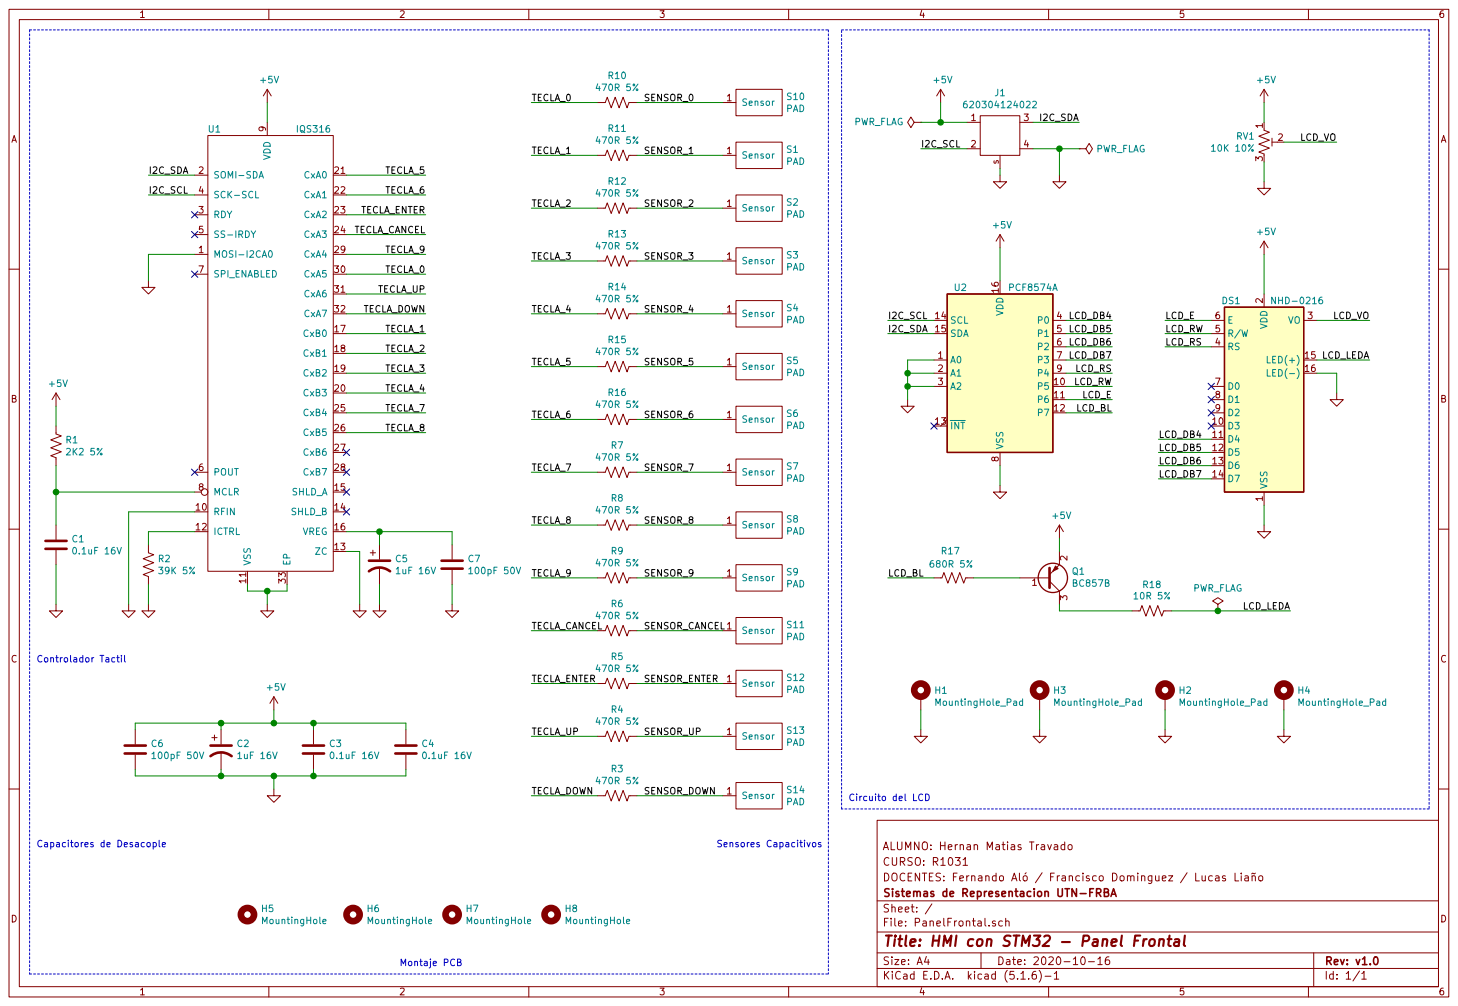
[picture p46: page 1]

DOCENTES: Fernando Aló / Francisco Dominguez / Lucas Liaño CURSO: R1031 ALUMNO: Hernan Matias Travado H6MountingHole

Id: 1/1 Title: HMI con STM32 - Panel Frontal File: PanelFrontal.sch Sheet: / Sistemas de Representacion UTN-FRBA

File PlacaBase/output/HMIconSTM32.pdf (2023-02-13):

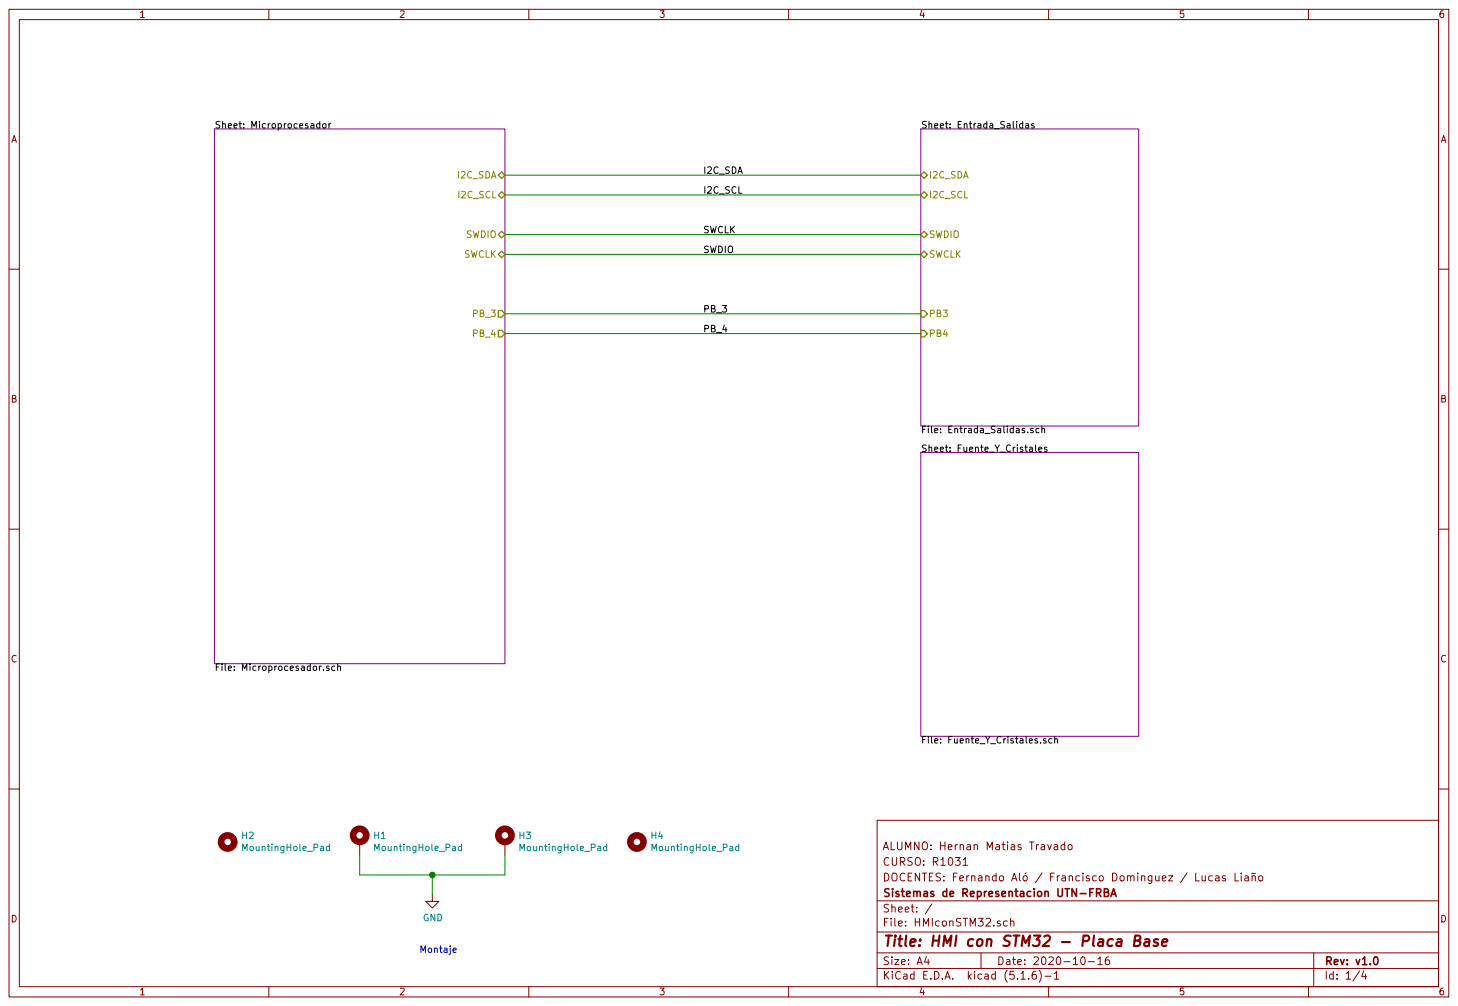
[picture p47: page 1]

DOCENTES: Fernando Aló / Francisco Dominguez / Lucas Liaño CURSO: R1031 ALUMNO: Hernan Matias Travado Sheet: Fuente_Y_Cristales File: Fuente_Y_Cristales.sch

File: HMIconSTM32.sch Sheet: / Sistemas de Representacion UTN-FRBA

Id: 1/4 Title: HMI con STM32 - Placa Base

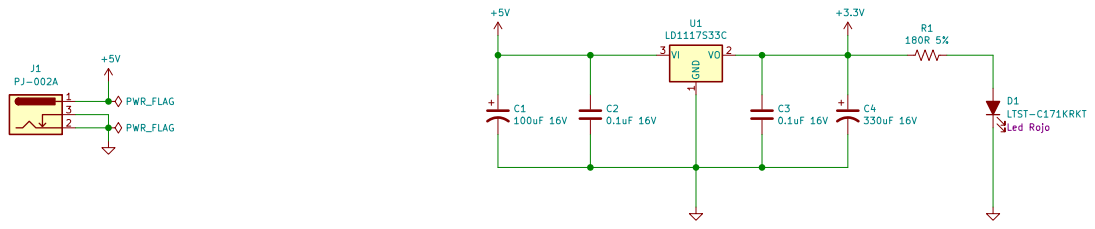
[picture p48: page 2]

DOCENTES: Fernando Aló / Francisco Dominguez / Lucas Liaño CURSO: R1031 ALUMNO: Hernan Matias Travado

Sistemas de Representacion UTN-FRBA
Sheet: /Fuente_Y_Cristales/
File: Fuente_Y_Cristales.sch
Id: 2/4 Title: HMI con STM32 - Placa Base

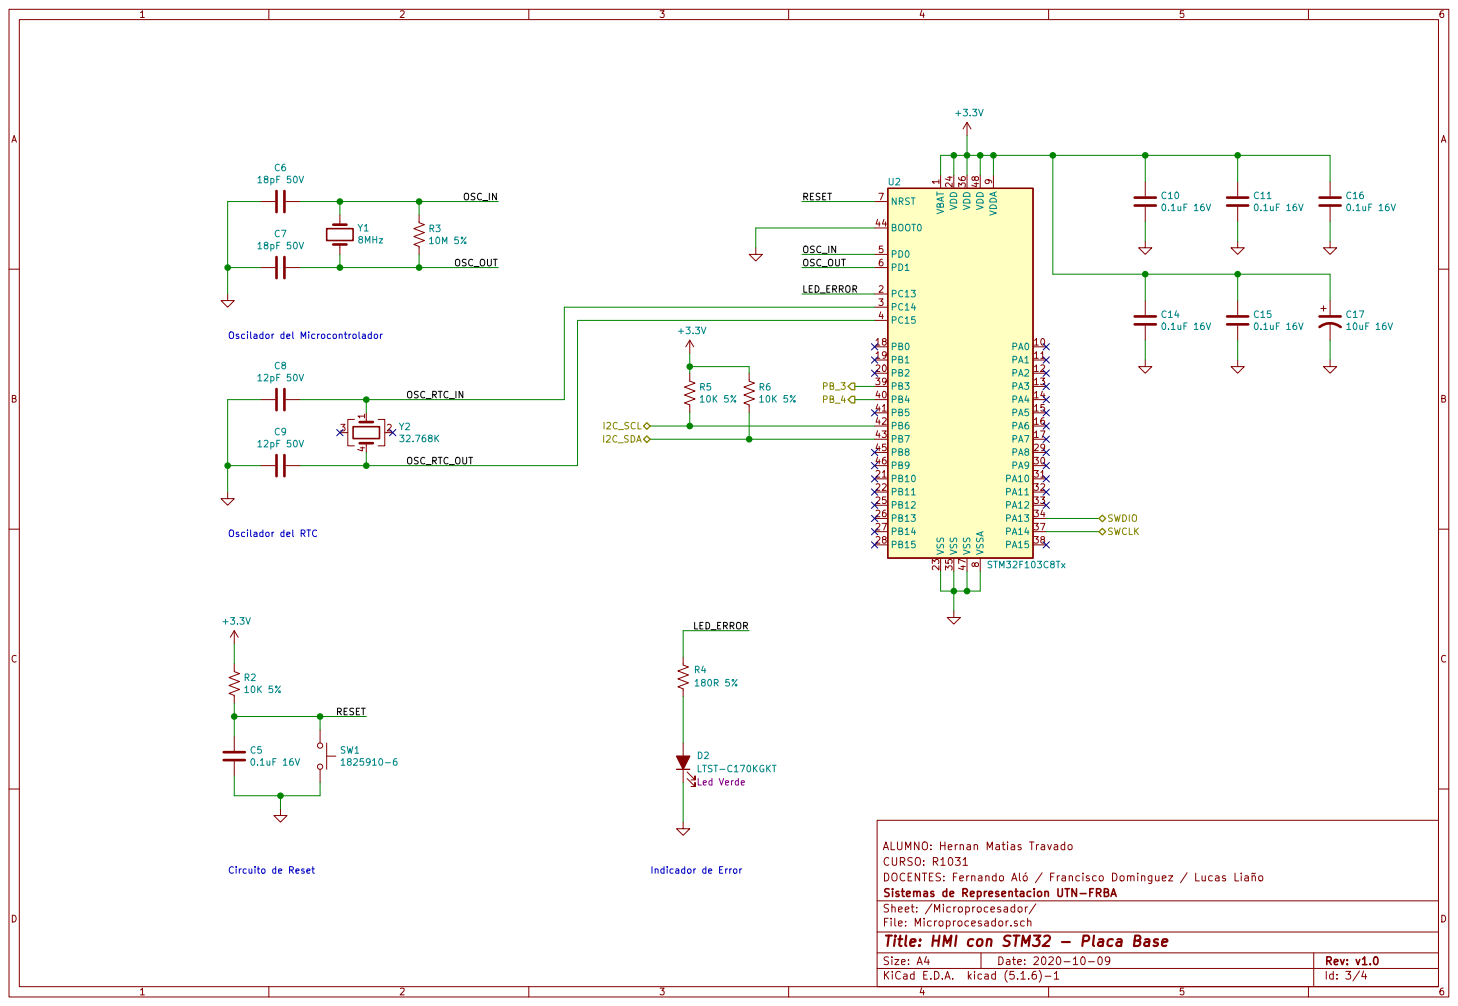
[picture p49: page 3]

Oscilador del Microcontrolador Circuito de Reset Oscilador del RTC

1 VDD 24 VDD 36 VDD 48 VDDA

9 VSS 23 VSS 35 VSS 47 VSSA

DOCENTES: Fernando Aló / Francisco Dominguez / Lucas Liaño CURSO: R1031 ALUMNO: Hernan Matias Travado

Sistemas de Representacion UTN-FRBA
Sheet: /Microprocesador/
File: Microprocesador.sch
Id: 3/4 Title: HMI con STM32 - Placa Base

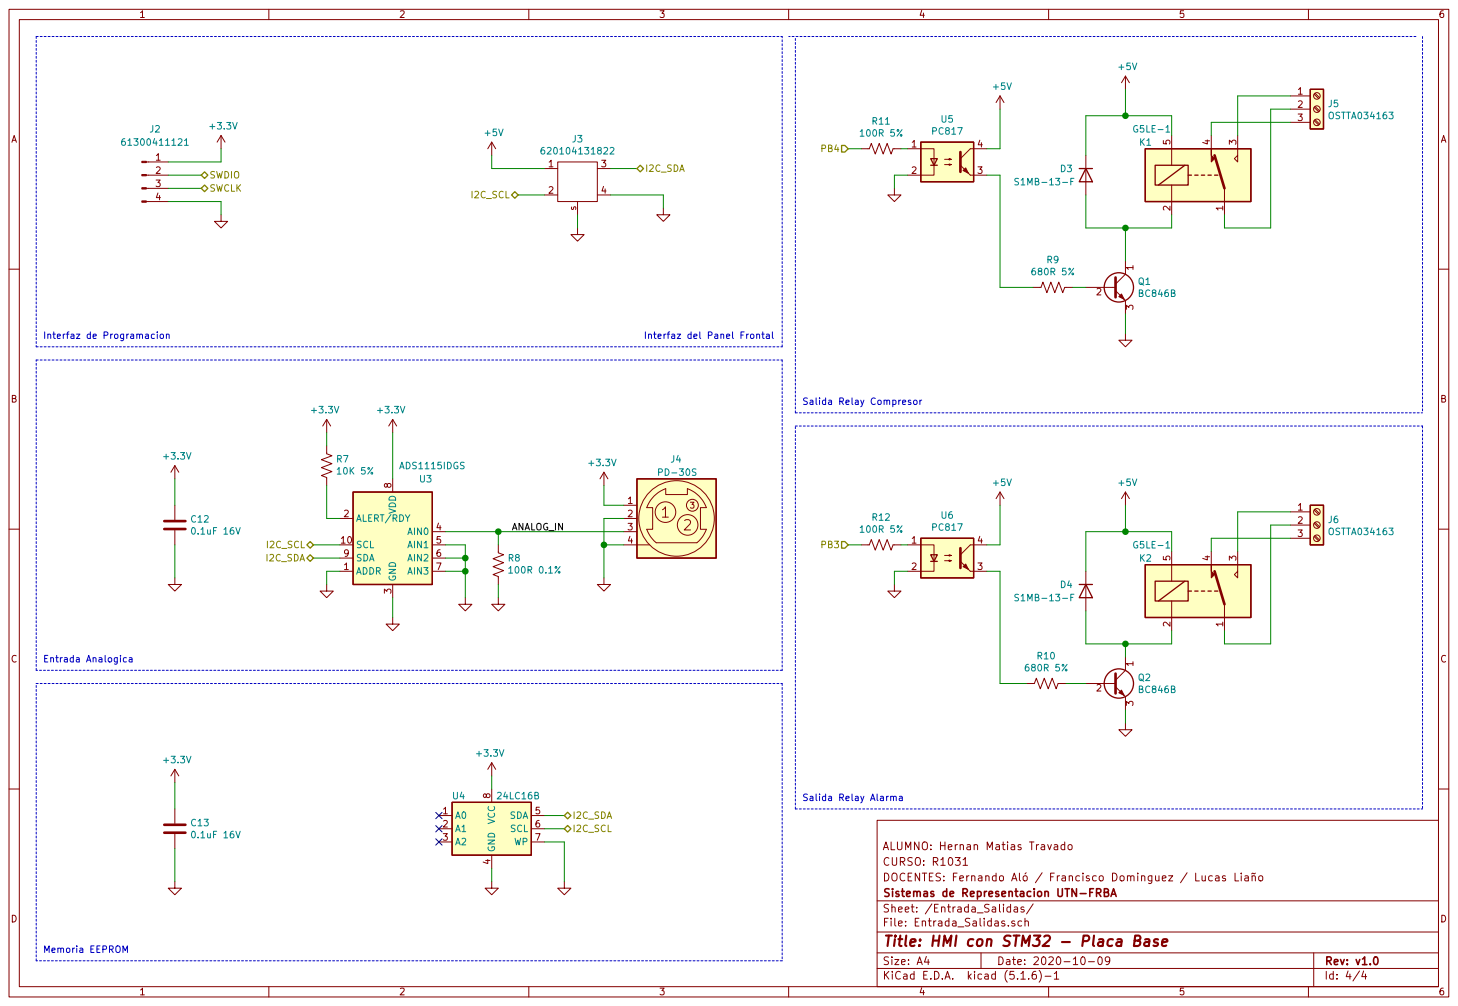
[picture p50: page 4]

4 SDA 5 SCL 6 WP 7 VCC

DOCENTES: Fernando Aló / Francisco Dominguez / Lucas Liaño CURSO: R1031 ALUMNO: Hernan Matias Travado

Sistemas de Representacion UTN-FRBA
Sheet: /Entrada_Salidas/
File: Entrada_Salidas.sch
Id: 4/4 Title: HMI con STM32 - Placa Base

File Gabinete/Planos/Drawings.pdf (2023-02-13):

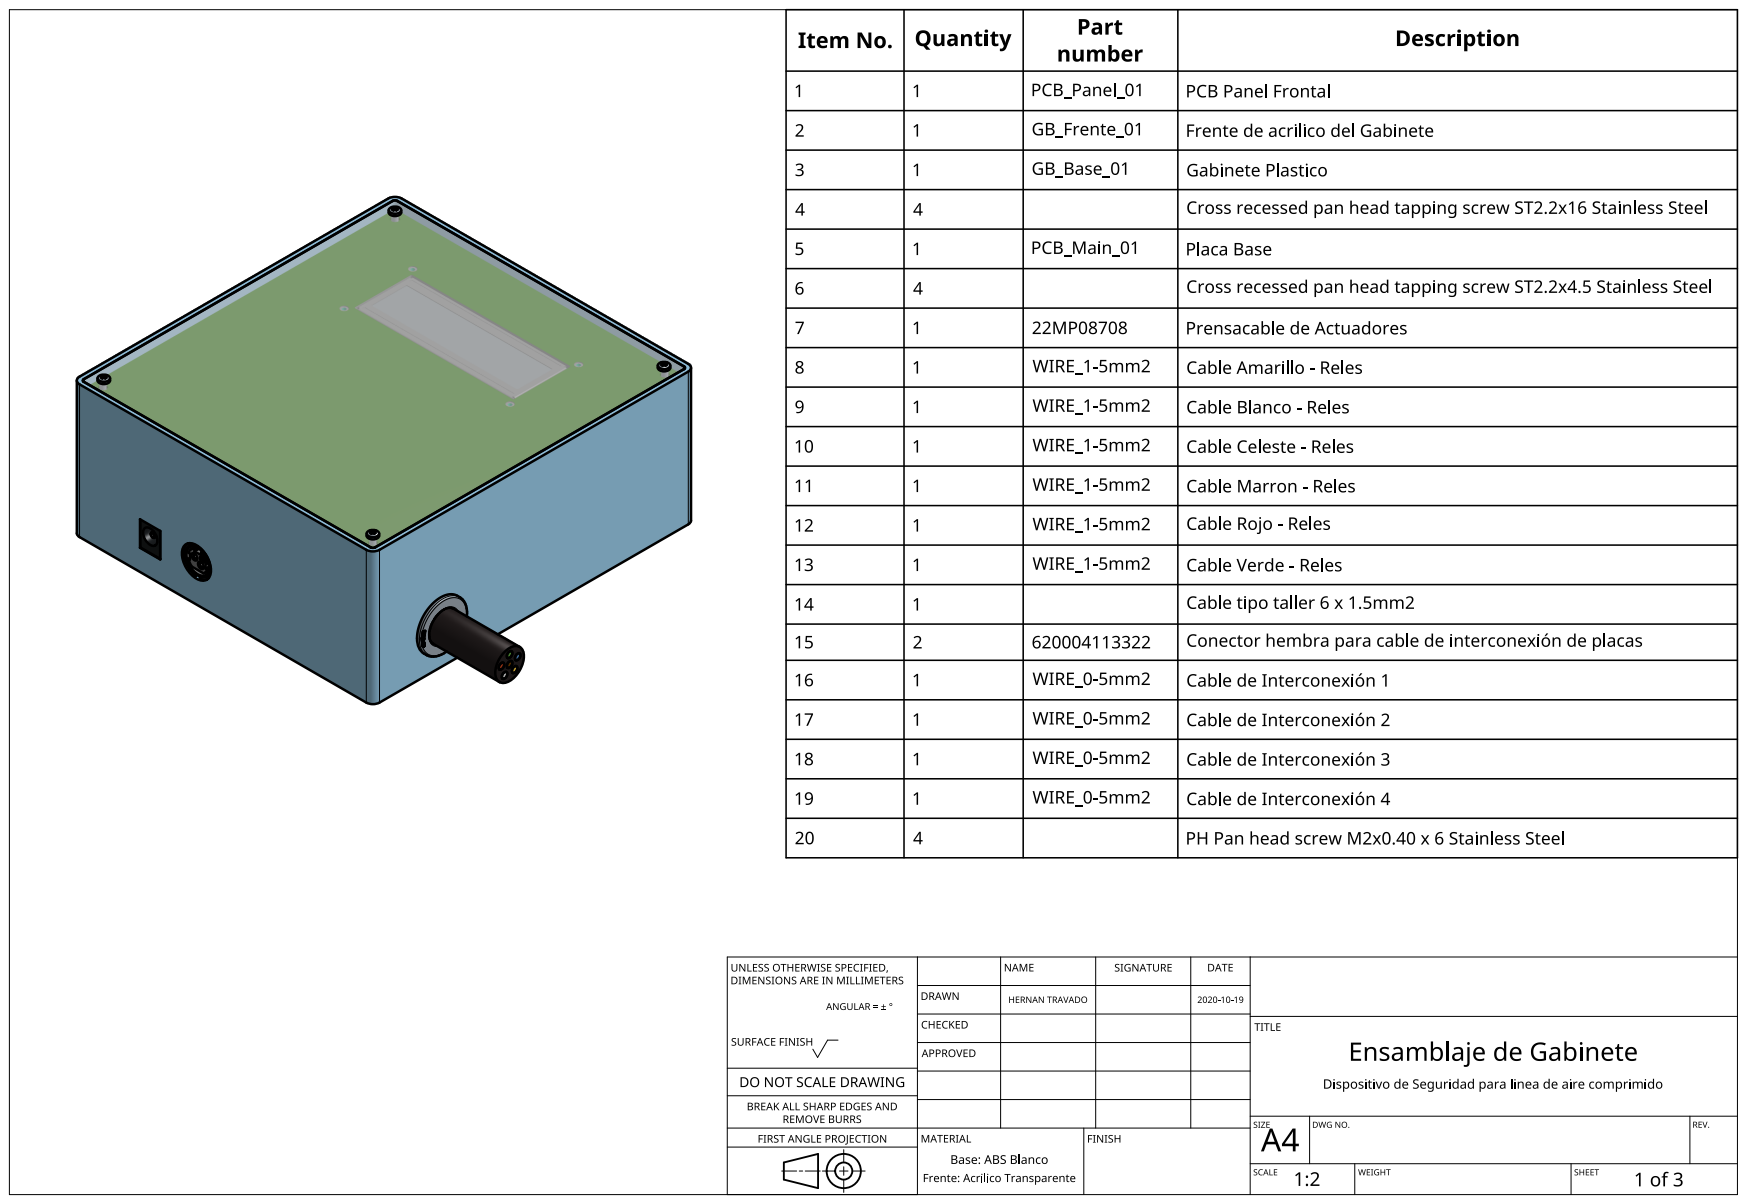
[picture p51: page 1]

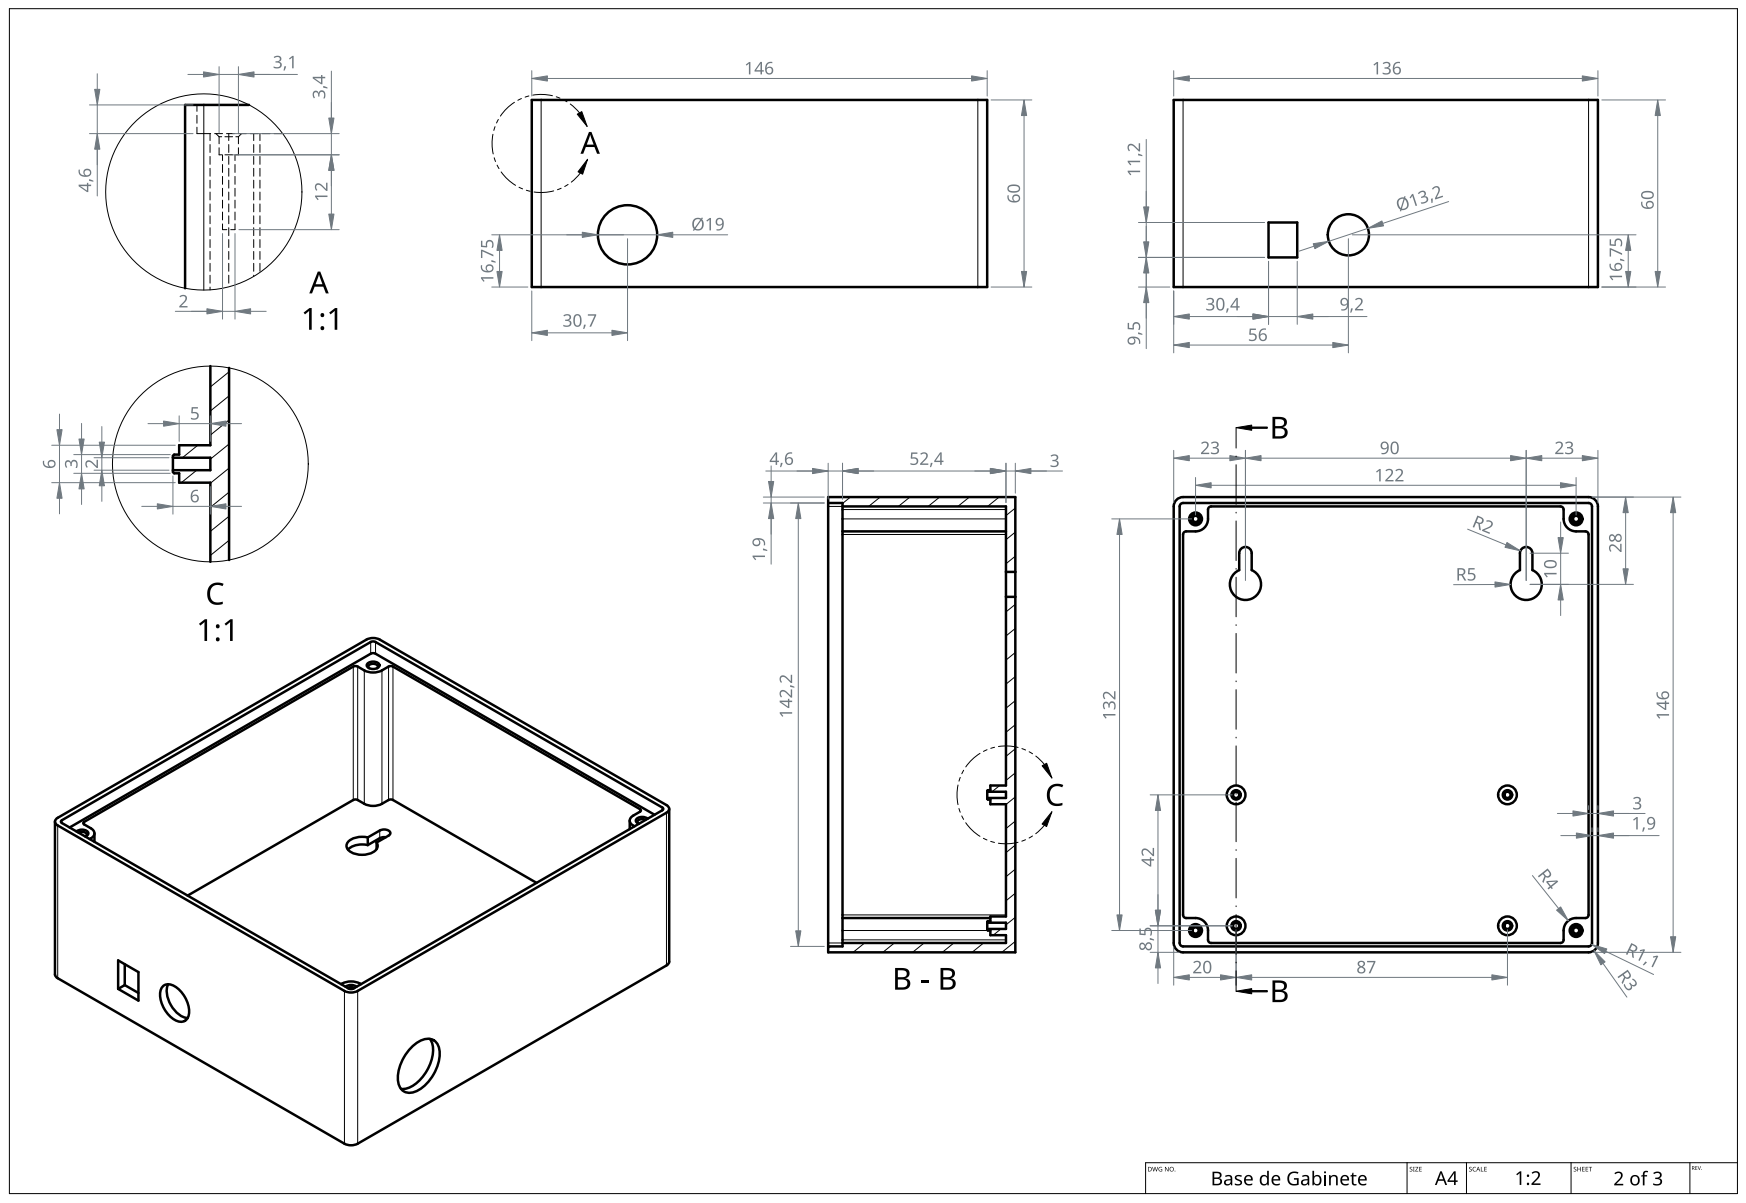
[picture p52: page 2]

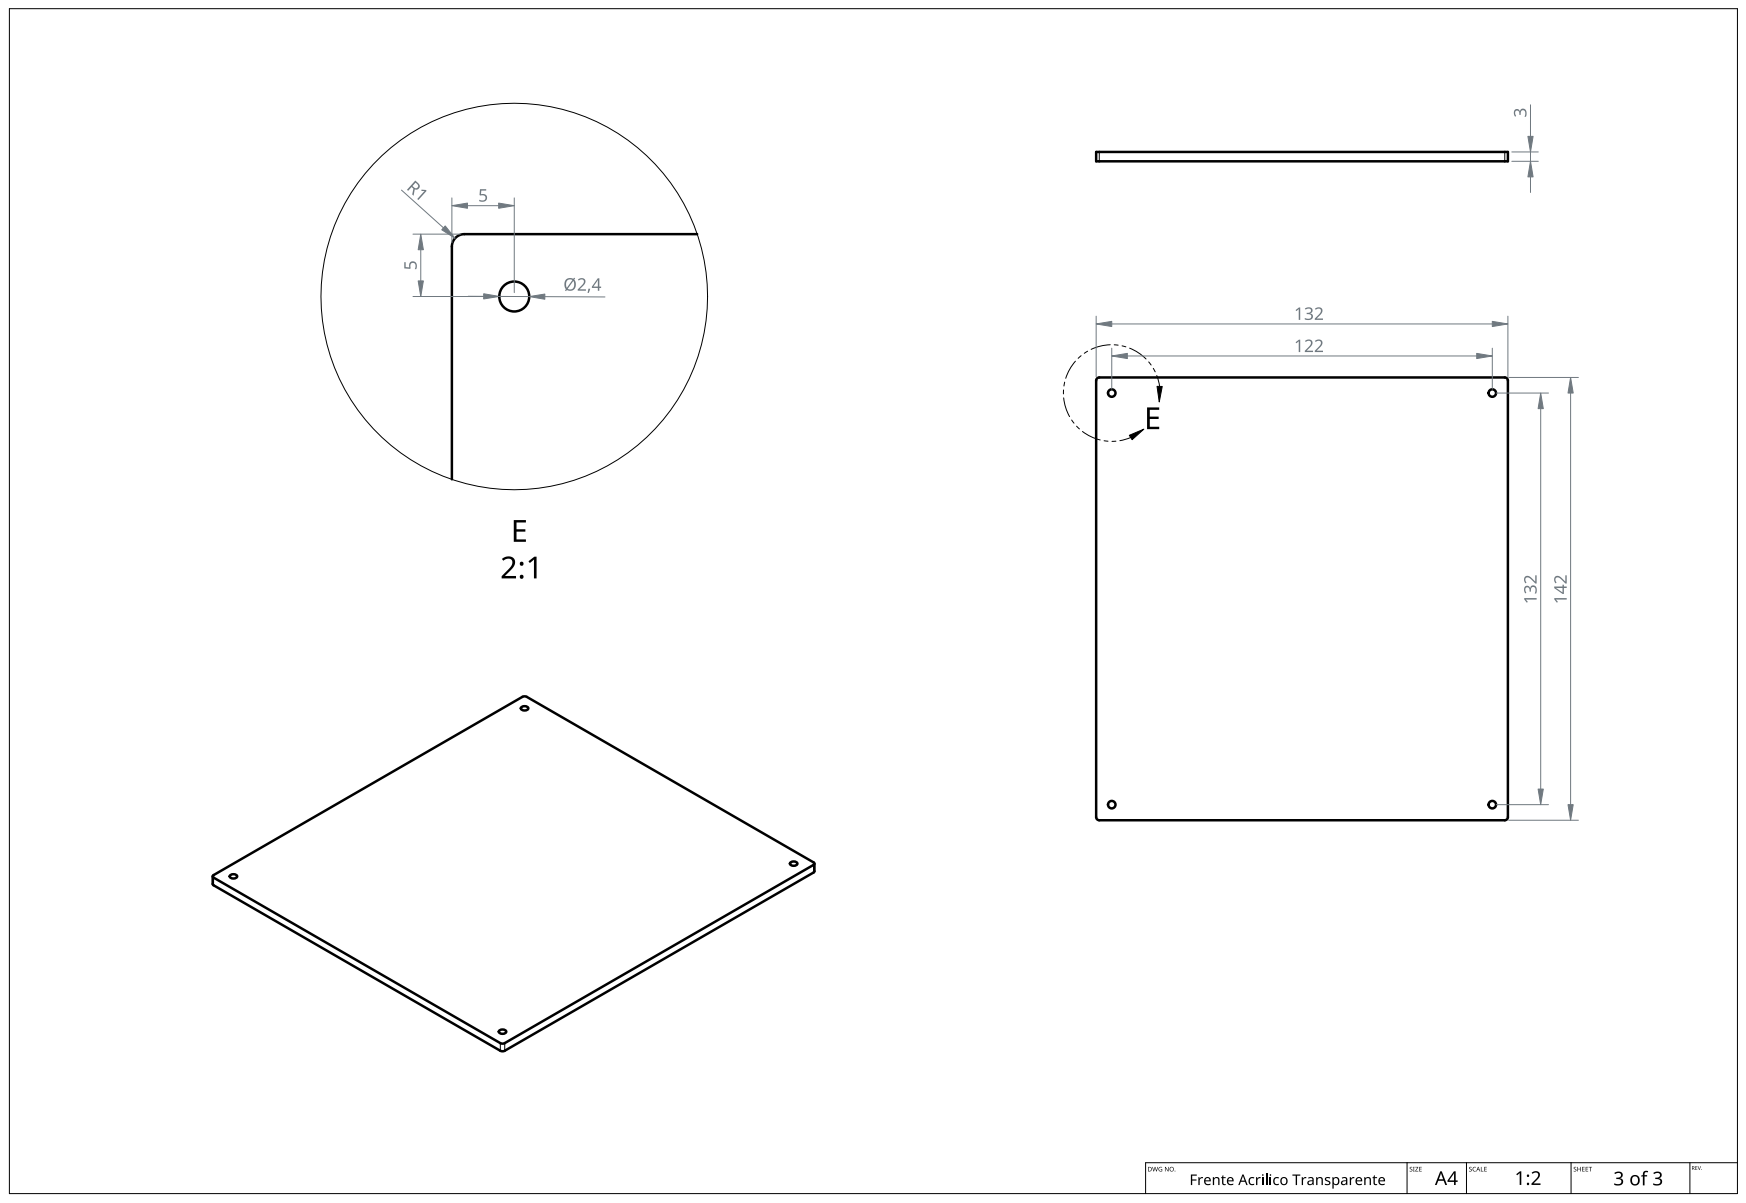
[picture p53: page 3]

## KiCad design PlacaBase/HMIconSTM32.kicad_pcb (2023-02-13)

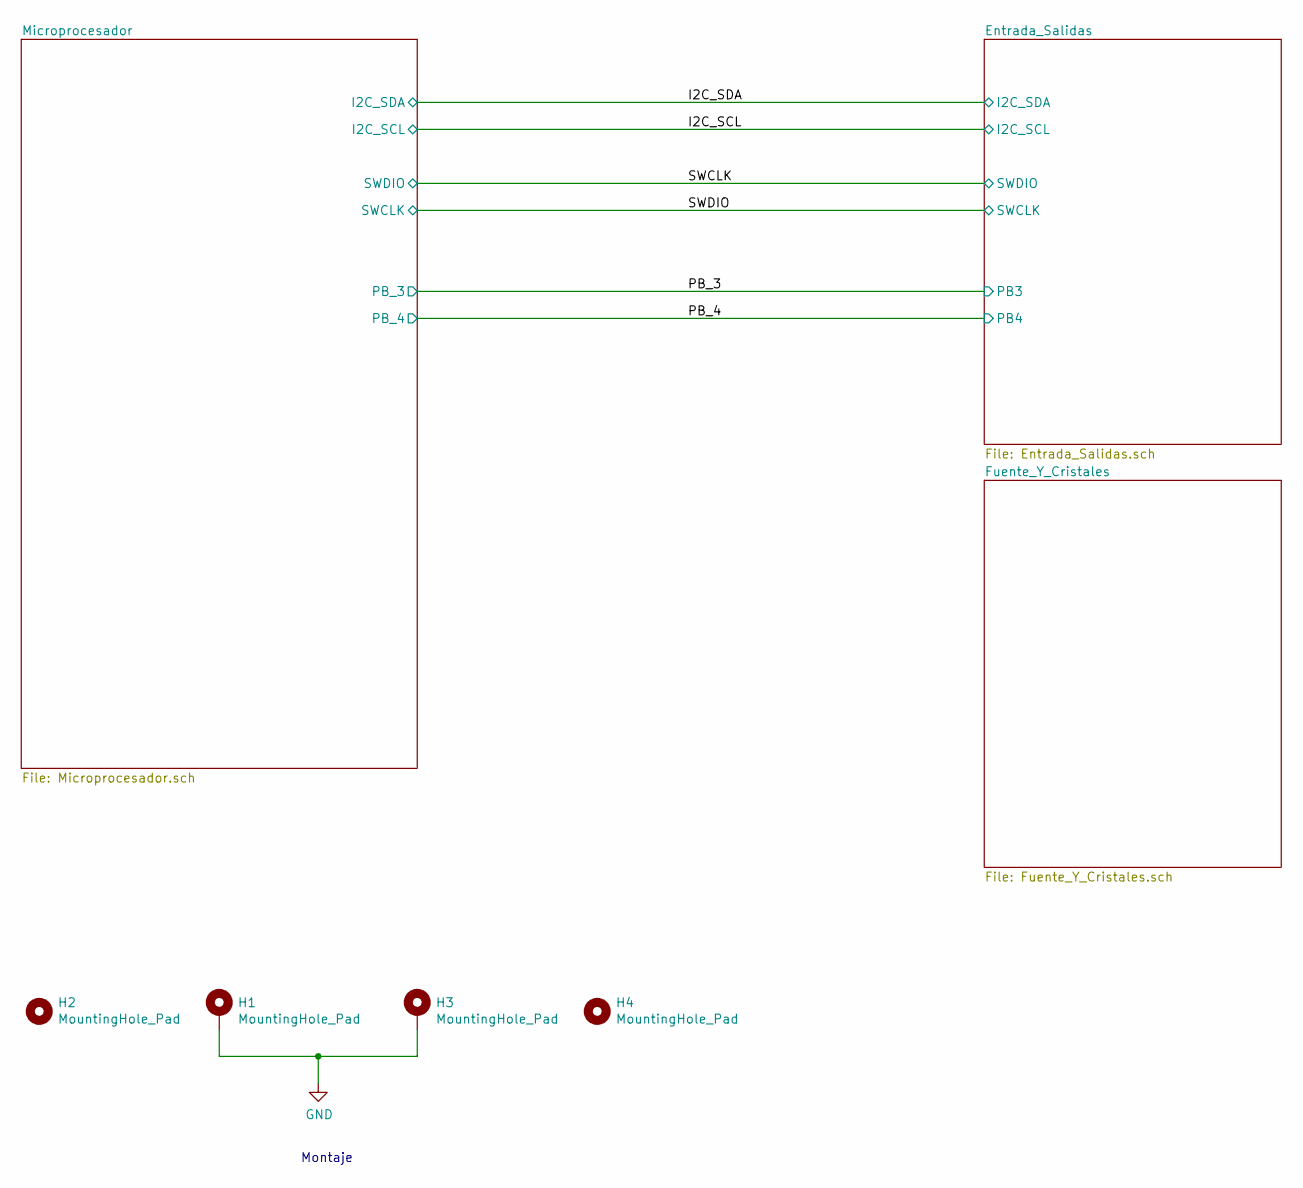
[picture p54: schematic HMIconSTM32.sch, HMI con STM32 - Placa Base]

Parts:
H1, H3: MountingHole_Pad; MountingHole_3.2mm_M3_Pad
H2, H4: MountingHole_Pad; MountingHole_3.2mm_M3

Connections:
GND: H1.1, H3.1; also elsewhere on the board

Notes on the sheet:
Montaje

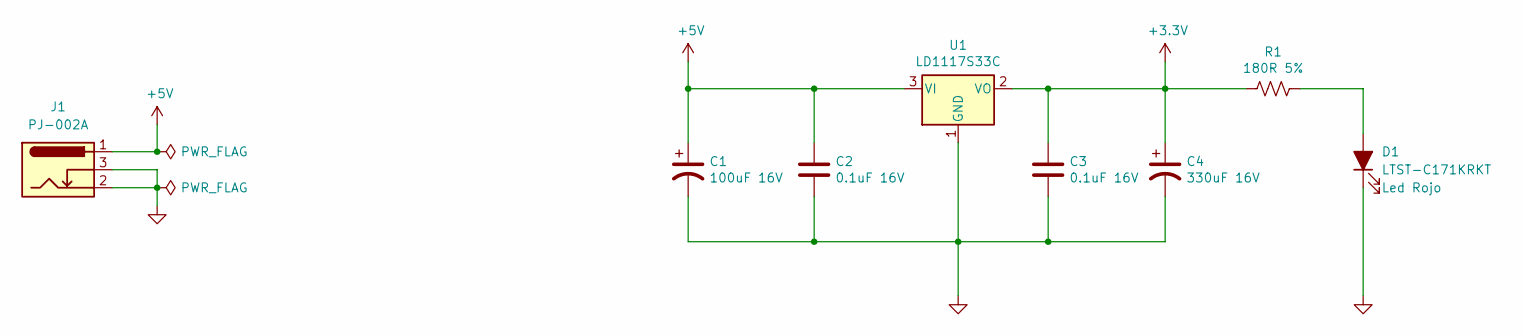
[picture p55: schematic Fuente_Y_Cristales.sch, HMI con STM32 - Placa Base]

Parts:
C1: 100uF 16V; CP_Elec_8x10.5; Manufacturer P/N EEE-HB1C101AP; Digikey P/N PCE4744CT-ND
C2, C3: 0.1uF 16V; C_0603_1608Metric; Manufacturer P/N CL10B104KO8NNNC; Digikey P/N 1276-1005-1-ND
C4: 330uF 16V; CP_Elec_10x10.5; Manufacturer P/N EEE-HB1C331AP; Digikey P/N PCE4748CT-ND
D1: LTST-C171KRKT; LED_0805_2012Metric; Manufacturer P/N LTST-C171KRKT; Digikey P/N 160-1427-2-ND
J1: PJ-002A; Manufacturer P/N PJ-002A; Digikey P/N CP-002A-ND
R1: 180R 5%; R_0603_1608Metric; Manufacturer P/N RC0603JR-07180RL; Digikey P/N 311-180GRCT-ND
U1: LD1117S33C; SOT-223-3_TabPin2; Manufacturer P/N LD1117S33CTR; Digikey P/N 497-1241-1-ND

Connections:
+3V3: C3.1, C4.1, R1.2, U1.2 (VO); also elsewhere on the board
+5V: C1.1, C2.1, J1.1, U1.3 (VI); also elsewhere on the board
GND: C1.2, C2.2, C3.2, C4.2, D1.1 (K), J1.2, J1.3, U1.1 (GND); also elsewhere on the board
unnamed: D1.2 (A), R1.1

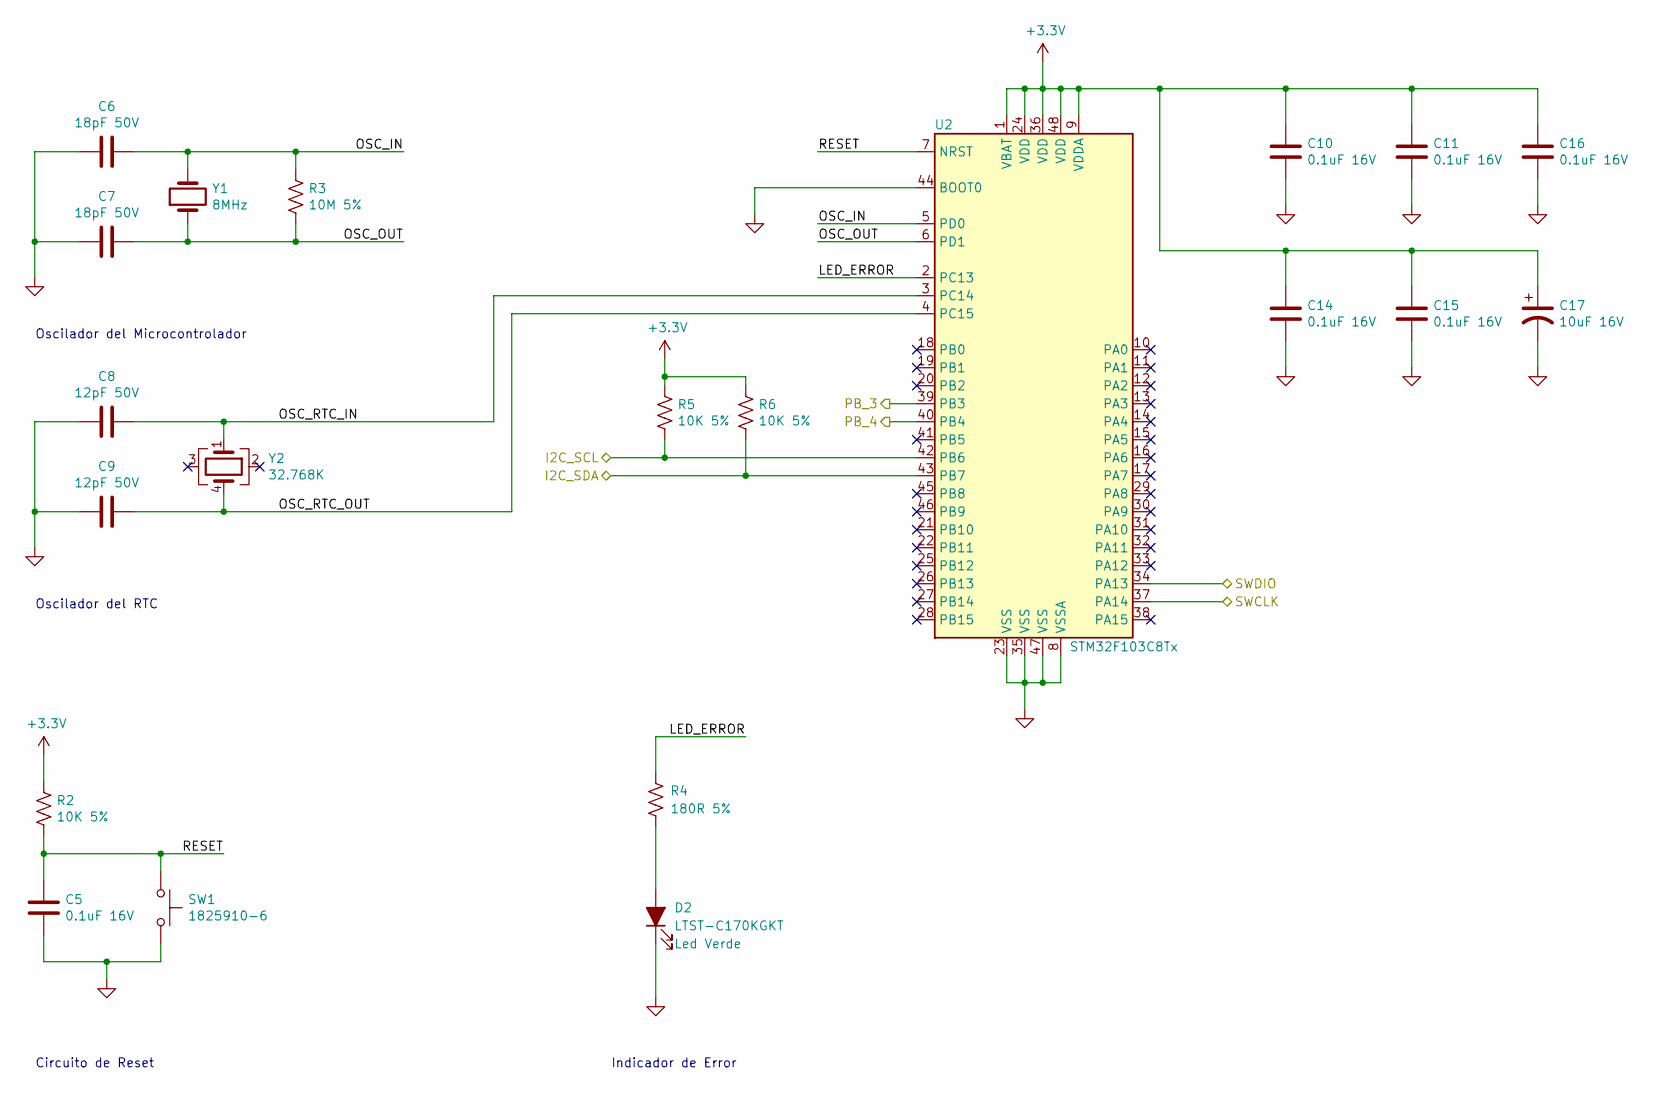
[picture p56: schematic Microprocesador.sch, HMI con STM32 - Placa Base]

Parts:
C5, C10, C11, C14, C15, C16: 0.1uF 16V; C_0603_1608Metric; Manufacturer P/N CL10B104KO8NNNC; Digikey P/N 1276-1005-1-ND
C6, C7: 18pF 50V; C_0603_1608Metric; Manufacturer P/N CL10C180JB8NNNC; Digikey P/N 1276-1089-1-ND
C8, C9: 12pF 50V; C_0603_1608Metric; Manufacturer P/N CL10C120JB8NNNC; Digikey P/N 1276-1254-1-ND
C17: 10uF 16V; CP_Elec_4x5.8; Manufacturer P/N EEE-HB1C100AR; Digikey P/N PCE4743CT-ND
D2: LTST-C170KGKT; LED_0805_2012Metric; Manufacturer P/N LTST-C170KGKT; Digikey P/N 160-1414-1-ND
R2, R5, R6: 10K 5%; R_0603_1608Metric; Manufacturer P/N AC0603JR-0710KL; Digikey P/N 311-10KLECT-ND
R3: 10M 5%; R_0603_1608Metric; Manufacturer P/N RC0603JR-0710ML; Digikey P/N 311-10MGRCT-ND
R4: 180R 5%; R_0603_1608Metric; Manufacturer P/N RC0603JR-07180RL; Digikey P/N 311-180GRCT-ND
SW1: 1825910-6; SW_PUSH_6mm_H5mm; Manufacturer P/N 1825910-6; Digikey P/N 450-1650-ND
U2: STM32F103C8Tx; LQFP-48_7x7mm_P0.5mm; Manufacturer P/N STM32F103C8T6TR; Digikey P/N 497-17666-1-ND
Y1: 8MHz; Crystal_SMD_Abracon_ABM7-2Pin_6.0x3.5mm; Manufacturer P/N ABM7-8.000MHZ-D2Y-T; Digikey P/N 535-9831-1-ND
Y2: 32.768K; Crystal_SMD_Abracon_ABS25-4Pin_8.0x3.8mm; Manufacturer P/N ABS25-32.768KHZ-T; Digikey P/N 535-9166-1-ND

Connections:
+3V3: C10.1, C11.1, C14.1, C15.1, C16.1, C17.1, R2.1, R5.1, R6.1, U2.1 (VBAT), U2.9 (VDDA), U2.24 (VDD), U2.36 (VDD), U2.48 (VDD); also elsewhere on the board
/I2C_SCL: R5.2, U2.42 (PB6); also elsewhere on the board
/I2C_SDA: R6.2, U2.43 (PB7); also elsewhere on the board
/Microprocesador/LED_ERROR: R4.2, U2.2 (PC13)
/Microprocesador/OSC_IN: C6.2, R3.1, U2.5 (PD0), Y1.2
/Microprocesador/OSC_OUT: C7.2, R3.2, U2.6 (PD1), Y1.1
/Microprocesador/OSC_RTC_IN: C8.2, U2.3 (PC14), Y2.1
/Microprocesador/OSC_RTC_OUT: C9.2, U2.4 (PC15), Y2.4
/Microprocesador/RESET: C5.1, R2.2, SW1.1, U2.7 (NRST)
/PB_3: U2.39 (PB3); also elsewhere on the board
/PB_4: U2.40 (PB4); also elsewhere on the board
/SWCLK: U2.34 (PA13); also elsewhere on the board
/SWDIO: U2.37 (PA14); also elsewhere on the board
GND: C5.2, C6.1, C7.1, C8.1, C9.1, C10.2, C11.2, C14.2, C15.2, C16.2, C17.2, D2.1 (K), SW1.2, U2.8 (VSSA), U2.23 (VSS), U2.35 (VSS), U2.44 (BOOT0), U2.47 (VSS); also elsewhere on the board
unnamed: D2.2 (A), R4.1

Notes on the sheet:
Circuito de Reset
Oscilador del RTC
Oscilador del Microcontrolador
Indicador de Error

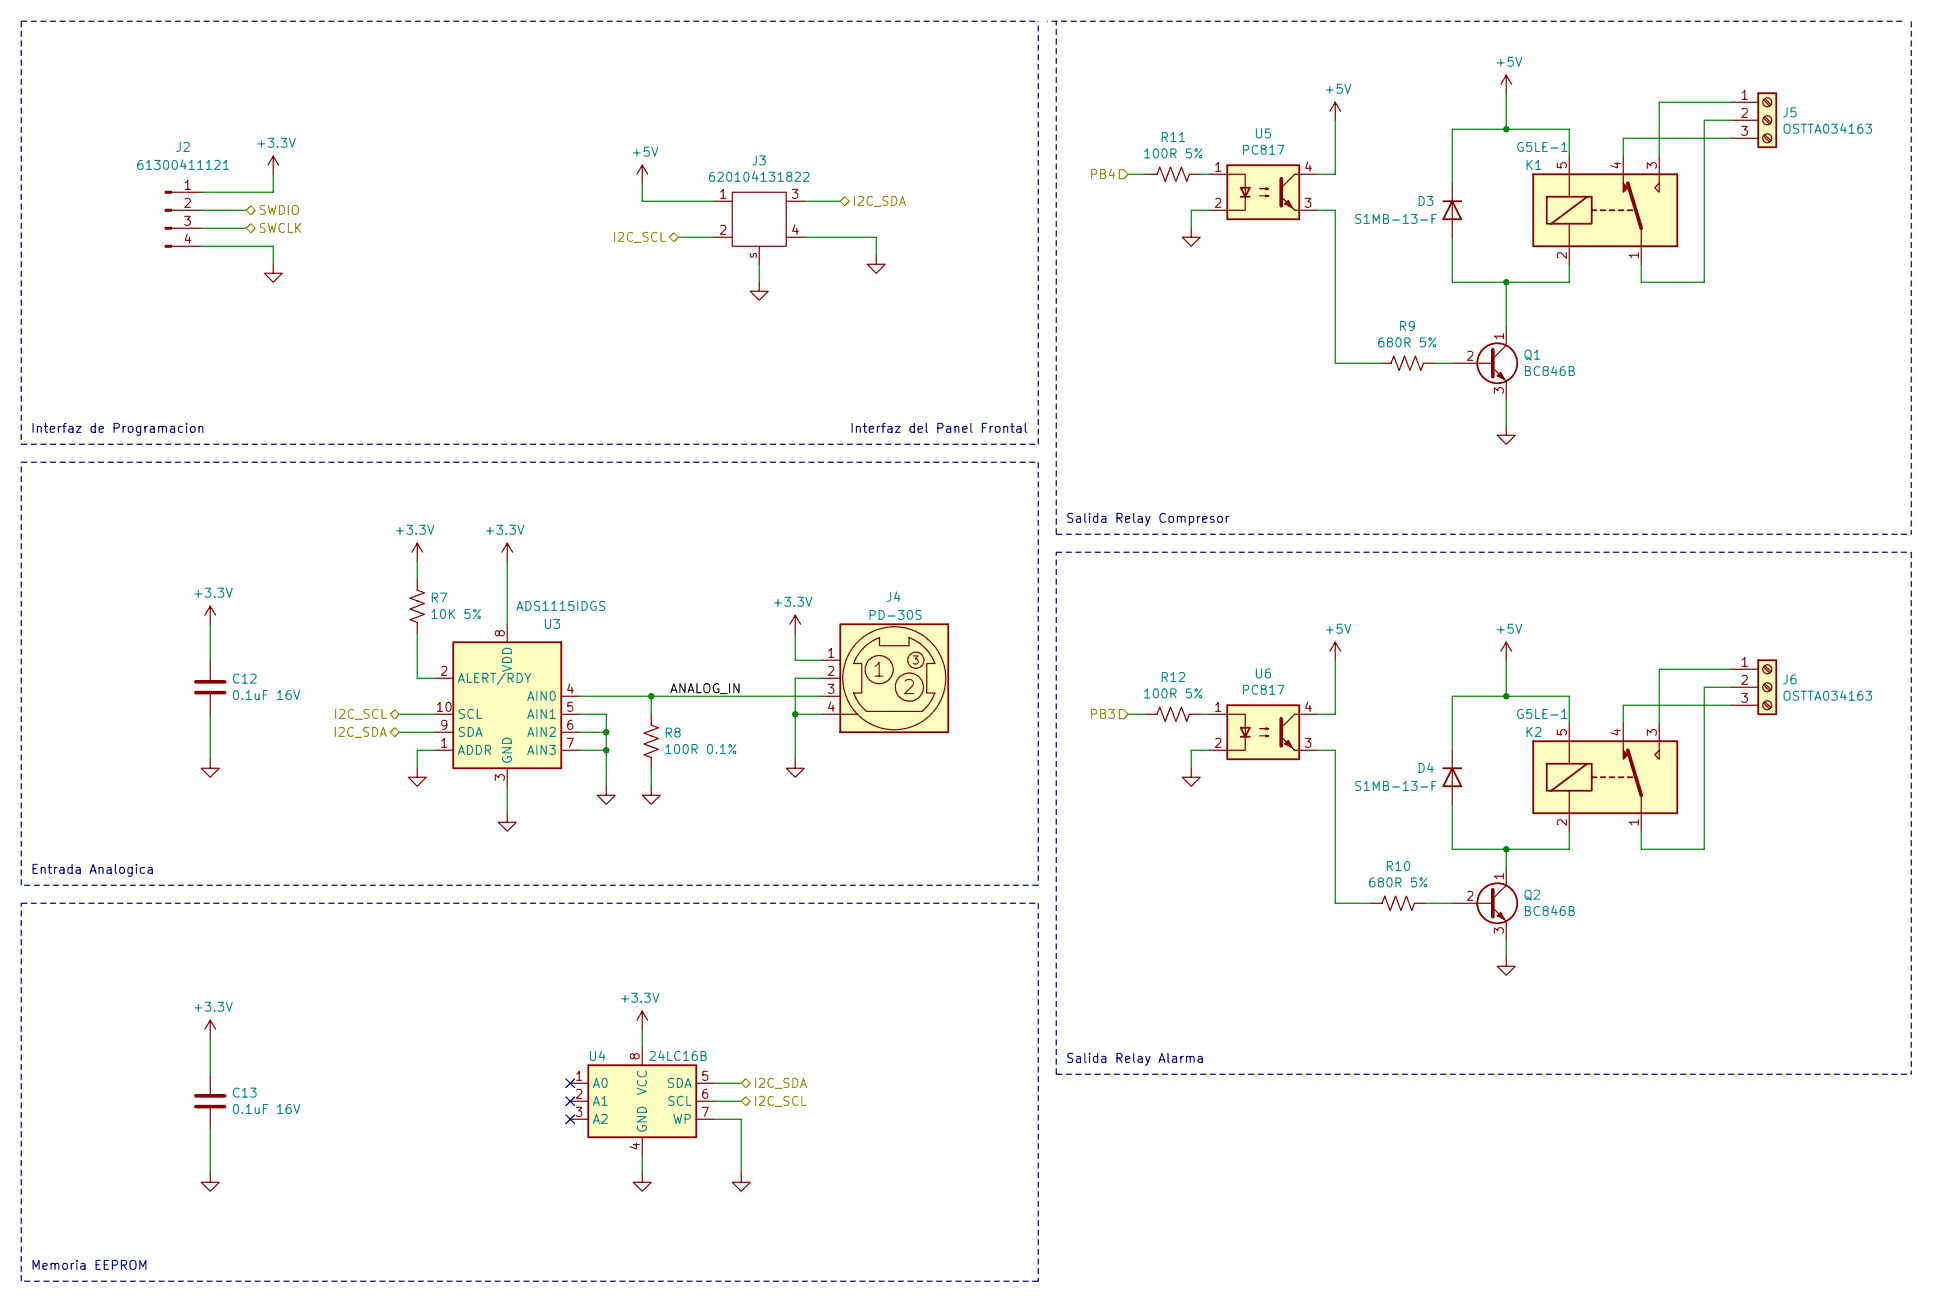
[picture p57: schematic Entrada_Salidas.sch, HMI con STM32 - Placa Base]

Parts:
C12, C13: 0.1uF 16V; C_0603_1608Metric; Manufacturer P/N CL10B104KO8NNNC; Digikey P/N 1276-1005-1-ND
D3, D4: S1MB-13-F; D_SMB; Manufacturer P/N S1MB-13-F; Digikey P/N S1MB-FDICT-ND
J2: 61300411121; PinHeader_1x04_P2.54mm_Vertical; Manufacturer P/N 61300411121; Digikey P/N 732-5317-ND
J3: 620104131822; Manufacturer P/N 620104131822; Digikey P/N 732-2713-1-ND
J4: PD-30S; CUI_PD-30S; Manufacturer P/N PD-30S; Digikey P/N CP-7230-ND
J5, J6: OSTTA034163; Manufacturer P/N OSTTA034163; Digikey P/N ED2581-ND
K1, K2: G5LE-1; Relay_SPDT_Omron-G5LE-1; Manufacturer P/N G5LE-14 DC5; Digikey P/N Z1011-ND
Q1, Q2: BC846B; SOT-23; Manufacturer P/N BC846BLT3G; Digikey P/N BC846BLT3GOSCT-ND
R7: 10K 5%; R_0603_1608Metric; Manufacturer P/N AC0603JR-0710KL; Digikey P/N 311-10KLECT-ND
R8: 100R 0.1%; R_0603_1608Metric; Manufacturer P/N RT0603BRD07100RL; Digikey P/N YAG1497DKR-ND
R9, R10: 680R 5%; R_0603_1608Metric; Manufacturer P/N RC0603JR-07680RL; Digikey P/N 311-680GRCT-ND
R11, R12: 100R 5%; R_0603_1608Metric; Manufacturer P/N RC0603JR-07100RL; Digikey P/N 311-100GRCT-ND
U3: ADS1115IDGS; TSSOP-10_3x3mm_P0.5mm; Manufacturer P/N ADS1115IDGSR; Digikey P/N 296-38849-1-ND
U4: 24LC16B; SOIC-8_3.9x4.9mm_P1.27mm; Manufacturer P/N 24LC16BT-I/SN; Digikey P/N 24LC16BT-I/SNCT-ND
U5, U6: PC817; DIP-4_W7.62mm; Manufacturer P/N PC81710NIP1B; Digikey P/N 1855-1014-1-ND

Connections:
+3V3: C12.1, C13.1, J2.1, J4.1, R7.2, U3.8 (VDD), U4.8 (VCC); also elsewhere on the board
+5V: D3.1 (K), D4.1 (K), J3.1, K1.5, K2.5, U5.4, U6.4; also elsewhere on the board
/Entrada_Salidas/ANALOG_IN: J4.3, R8.2, U3.4 (AIN0)
/I2C_SCL: J3.2, U3.10 (SCL), U4.6 (SCL); also elsewhere on the board
/I2C_SDA: J3.3, U3.9 (SDA), U4.5 (SDA); also elsewhere on the board
/PB_3: R12.1; also elsewhere on the board
/PB_4: R11.1; also elsewhere on the board
/SWCLK: J2.2; also elsewhere on the board
/SWDIO: J2.3; also elsewhere on the board
GND: C12.2, C13.2, J2.4, J3.4, J3.s, J4.2, J4.4 (Shield), Q1.3 (E), Q2.3 (E), R8.1, U3.1 (ADDR), U3.3 (GND), U3.5 (AIN1), U3.6 (AIN2), U3.7 (AIN3), U4.4 (GND), U4.7 (WP), U5.2, U6.2; also elsewhere on the board
unnamed: D3.2 (A), K1.2, Q1.1 (C)
unnamed: D4.2 (A), K2.2, Q2.1 (C)
unnamed: J5.1, K1.3
unnamed: J5.2, K1.1
unnamed: J5.3, K1.4
unnamed: J6.1, K2.3
unnamed: J6.2, K2.1
unnamed: J6.3, K2.4
unnamed: Q1.2 (B), R9.2
unnamed: Q2.2 (B), R10.2
unnamed: R7.1, U3.2 (ALERT/RDY)
unnamed: R9.1, U5.3
unnamed: R10.1, U6.3
unnamed: R11.2, U5.1
unnamed: R12.2, U6.1

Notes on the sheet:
Salida Relay Compresor
Salida Relay Alarma
Interfaz de Programacion
Interfaz del Panel Frontal
Entrada Analogica
Memoria EEPROM

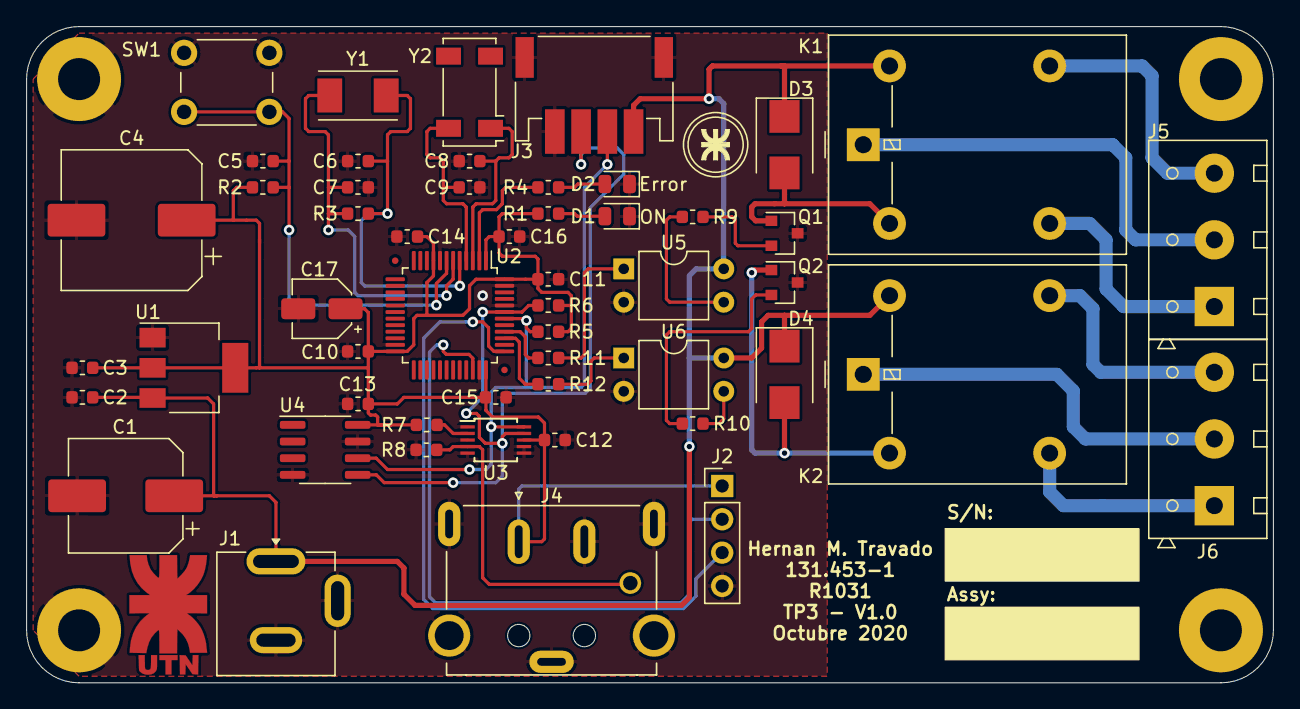
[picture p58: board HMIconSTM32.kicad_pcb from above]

Board: 2 copper layers, 95.0 x 50.0 mm, 57 parts (0 on the bottom side), 33 nets.

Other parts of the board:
LogoUTN.BA: UTN.BA

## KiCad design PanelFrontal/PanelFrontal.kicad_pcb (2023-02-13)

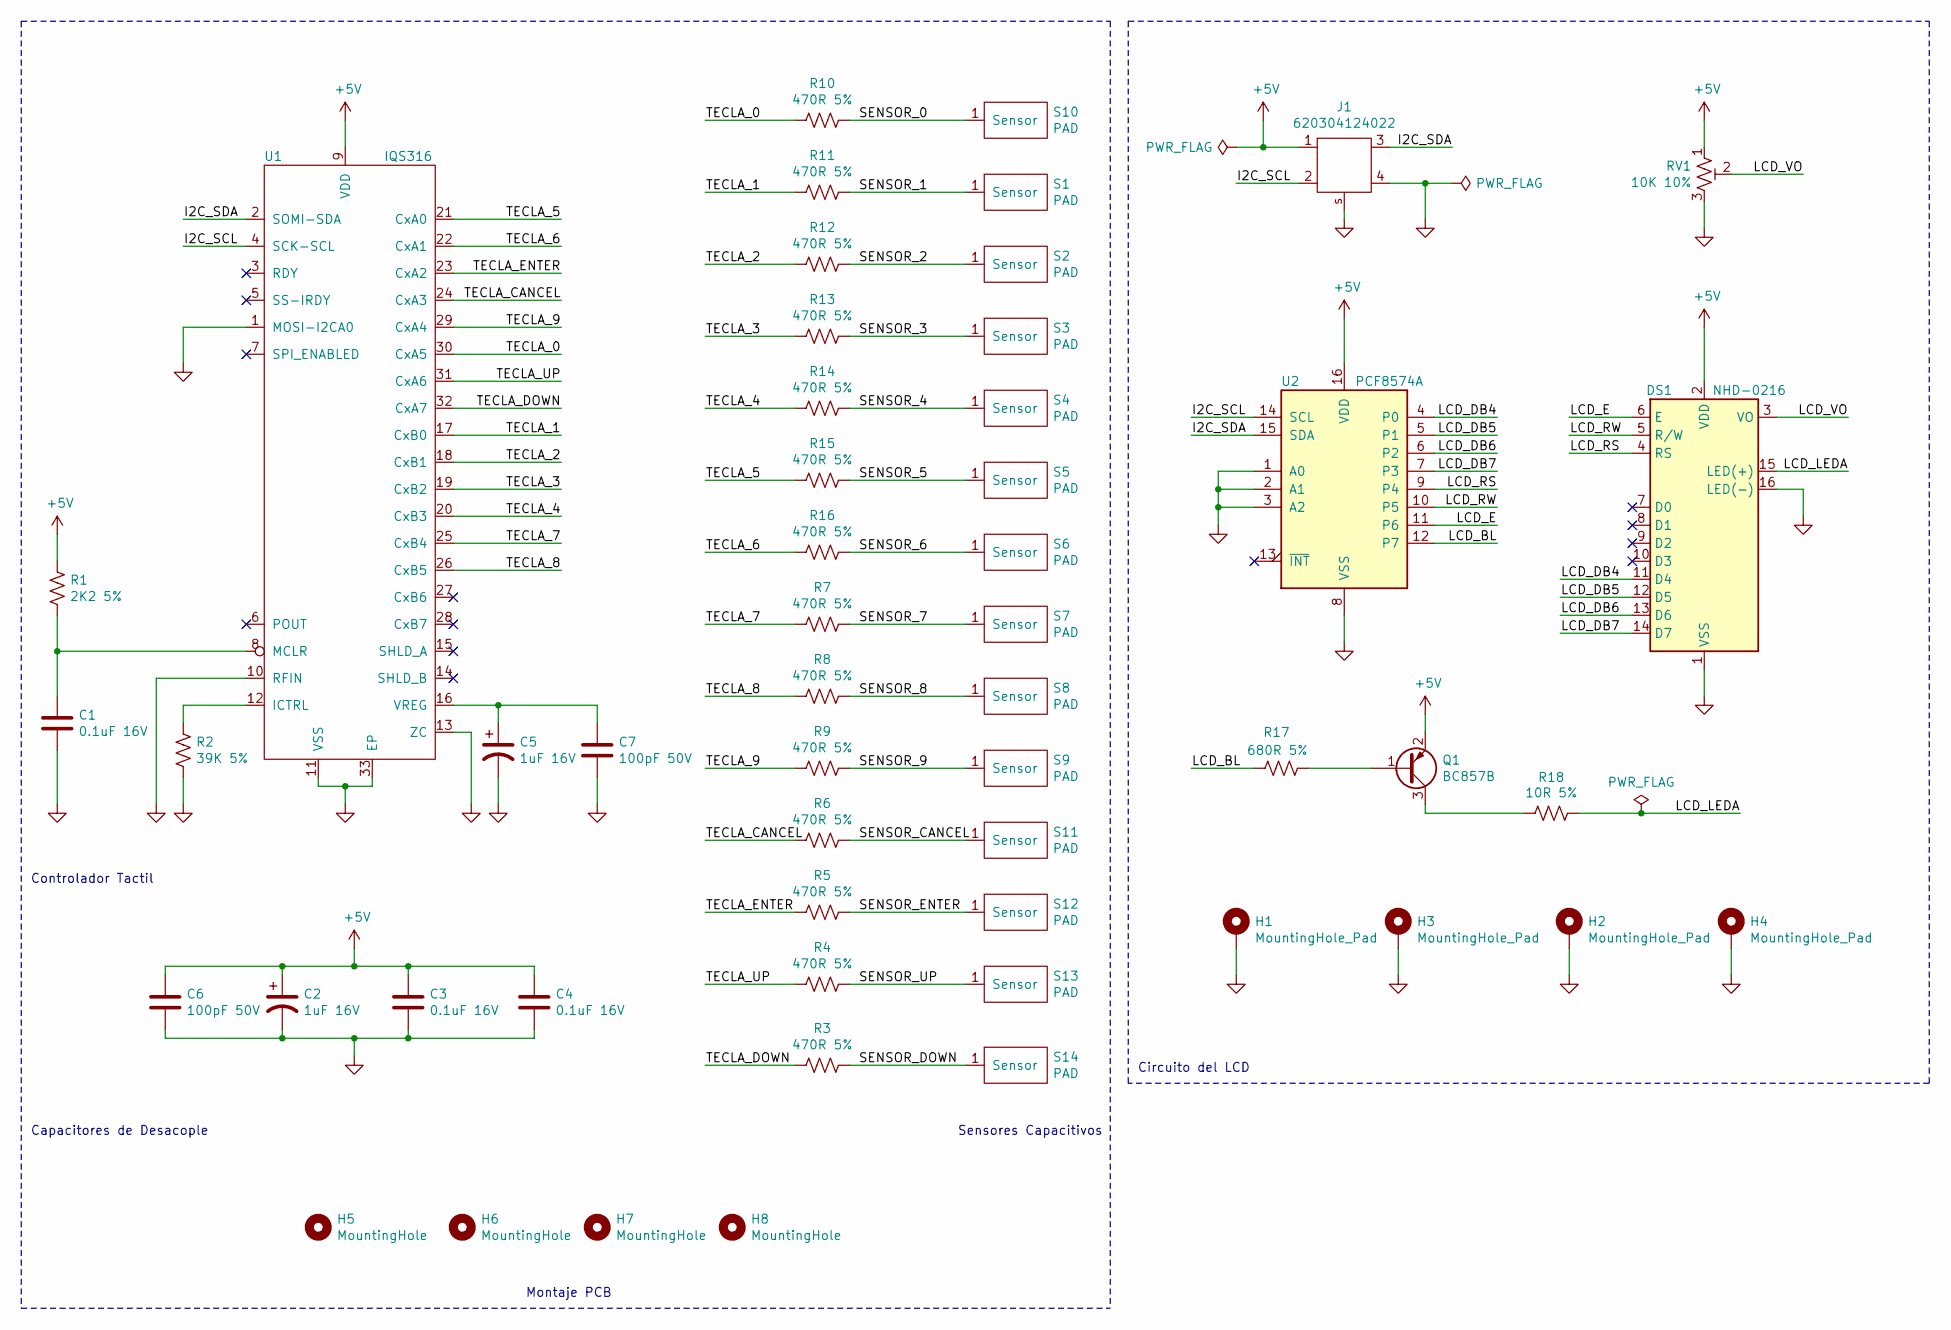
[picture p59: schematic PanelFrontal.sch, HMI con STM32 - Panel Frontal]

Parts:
C1, C3, C4: 0.1uF 16V; C_0603_1608Metric; Manufacturer P/N CL10B104KO8NNNC; Digikey P/N 1276-1005-1-ND
C2, C5: 1uF 16V; CP_Elec_4x5.4; Manufacturer P/N EEE-FC1V1R0R; Digikey P/N PCE4024CT-ND
C6, C7: 100pF 50V; C_0603_1608Metric; Manufacturer P/N CL10C101JB8NNNC; Digikey P/N 1276-1008-1-ND
DS1: NHD-0216; Manufacturer P/N NHD-0216K1Z-FL-YBW; Digikey P/N NHD-0216K1Z-FL-YBW-ND
H1, H2, H3, H4: MountingHole_Pad; 9774070243R; Manufacturer P/N 9774070243R; Digikey P/N 732-7107-1-ND
H5, H6, H7, H8: MountingHole; MountingHole_3.2mm_M3
J1: 620304124022; Manufacturer P/N 620304124022; Digikey P/N 732-2709-1-ND
Q1: BC857B; SOT-23; Manufacturer P/N BC857BLT1G; Digikey P/N BC857BLT1GOSCT-ND
R1: 2K2 5%; R_0603_1608Metric; Manufacturer P/N RC0603JR-072K2L; Digikey P/N 311-2.2KGRCT-ND
R2: 39K 5%; R_0603_1608Metric; Manufacturer P/N RC0603JR-0739KL; Digikey P/N 311-39KGRCT-ND
R3, R4, R5, R6, R7, R8, R9, R10, R11, R12, R13, R14, R15, R16: 470R 5%; R_0603_1608Metric; Manufacturer P/N RC0603JR-07100RL; Digikey P/N 311-100GRCT-ND
R17: 680R 5%; R_0603_1608Metric; Manufacturer P/N RC0603JR-07680RL; Digikey P/N 311-680GRCT-ND
R18: 10R 5%; R_0603_1608Metric; Manufacturer P/N RC0603JR-0710RL; Digikey P/N 311-10GRCT-ND
RV1: 10K 10%; 3361P-1-XXXGLF; Manufacturer P/N 3361P-1-103GLF; Digikey P/N 3361P-103GLFCT-ND
S1, S2, S3, S4, S5, S6, S7, S8, S9, S10, S11, S12, S13, S14: PAD; TouchSensor
U1: IQS316; QFN-32-1EP_5x5mm_P0.5mm_EP3.65x3.65mm; Manufacturer P/N IQS316-0-QFR; Digikey P/N 1790-1042-1-ND
U2: PCF8574A; SOIC-16W_7.5x10.3mm_P1.27mm; Manufacturer P/N PCF8574AT/3,518; Digikey P/N 568-1074-1-ND

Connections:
+5V: C2.1, C3.1, C4.1, C6.1, DS1.2 (VDD), J1.1, Q1.2 (E), R1.1, RV1.1, U1.9 (VDD), U2.16 (VDD)
/I2C_SCL: J1.2, U1.4 (SCK-SCL), U2.14 (SCL)
/I2C_SDA: J1.3, U1.2 (SOMI-SDA), U2.15 (SDA)
/LCD_BL: R17.1, U2.12 (P7)
/LCD_DB4: DS1.11 (D4), U2.4 (P0)
/LCD_DB5: DS1.12 (D5), U2.5 (P1)
/LCD_DB6: DS1.13 (D6), U2.6 (P2)
/LCD_DB7: DS1.14 (D7), U2.7 (P3)
/LCD_E: DS1.6 (E), U2.11 (P6)
/LCD_LEDA: DS1.15 (LED(+)), R18.1
/LCD_RS: DS1.4 (RS), U2.9 (P4)
/LCD_RW: DS1.5 (R/W), U2.10 (P5)
/LCD_VO: DS1.3 (VO), RV1.2
/SENSOR_0: R10.1, S10.1
/SENSOR_1: R11.1, S1.1
/SENSOR_2: R12.1, S2.1
/SENSOR_3: R13.1, S3.1
/SENSOR_4: R14.1, S4.1
/SENSOR_5: R15.1, S5.1
/SENSOR_6: R16.1, S6.1
/SENSOR_7: R7.1, S7.1
/SENSOR_8: R8.1, S8.1
/SENSOR_9: R9.1, S9.1
/SENSOR_CANCEL: R6.1, S11.1
/SENSOR_DOWN: R3.1, S14.1
/SENSOR_ENTER: R5.1, S12.1
/SENSOR_UP: R4.1, S13.1
/TECLA_0: R10.2, U1.30 (CxA5)
/TECLA_1: R11.2, U1.17 (CxB0)
/TECLA_2: R12.2, U1.18 (CxB1)
/TECLA_3: R13.2, U1.19 (CxB2)
/TECLA_4: R14.2, U1.20 (CxB3)
/TECLA_5: R15.2, U1.21 (CxA0)
/TECLA_6: R16.2, U1.22 (CxA1)
/TECLA_7: R7.2, U1.25 (CxB4)
/TECLA_8: R8.2, U1.26 (CxB5)
/TECLA_9: R9.2, U1.29 (CxA4)
/TECLA_CANCEL: R6.2, U1.24 (CxA3)
/TECLA_DOWN: R3.2, U1.32 (CxA7)
/TECLA_ENTER: R5.2, U1.23 (CxA2)
/TECLA_UP: R4.2, U1.31 (CxA6)
GND: C1.2, C2.2, C3.2, C4.2, C5.2, C6.2, C7.2, DS1.1 (VSS), DS1.16 (LED(-)), H1.1, H2.1, H3.1, H4.1, J1.4, J1.s, R2.2, RV1.3, U1.1 (MOSI-I2CA0), U1.10 (RFIN), U1.11 (VSS), U1.13 (ZC), U1.33 (EP), U2.1 (A0), U2.2 (A1), U2.3 (A2), U2.8 (VSS)
unnamed: C1.1, R1.2, U1.8 (MCLR)
unnamed: C5.1, C7.1, U1.16 (VREG)
unnamed: Q1.1 (B), R17.2
unnamed: Q1.3 (C), R18.2
unnamed: R2.1, U1.12 (ICTRL)

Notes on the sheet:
Circuito del LCD
Controlador Tactil
Capacitores de Desacople
Sensores Capacitivos
Montaje PCB

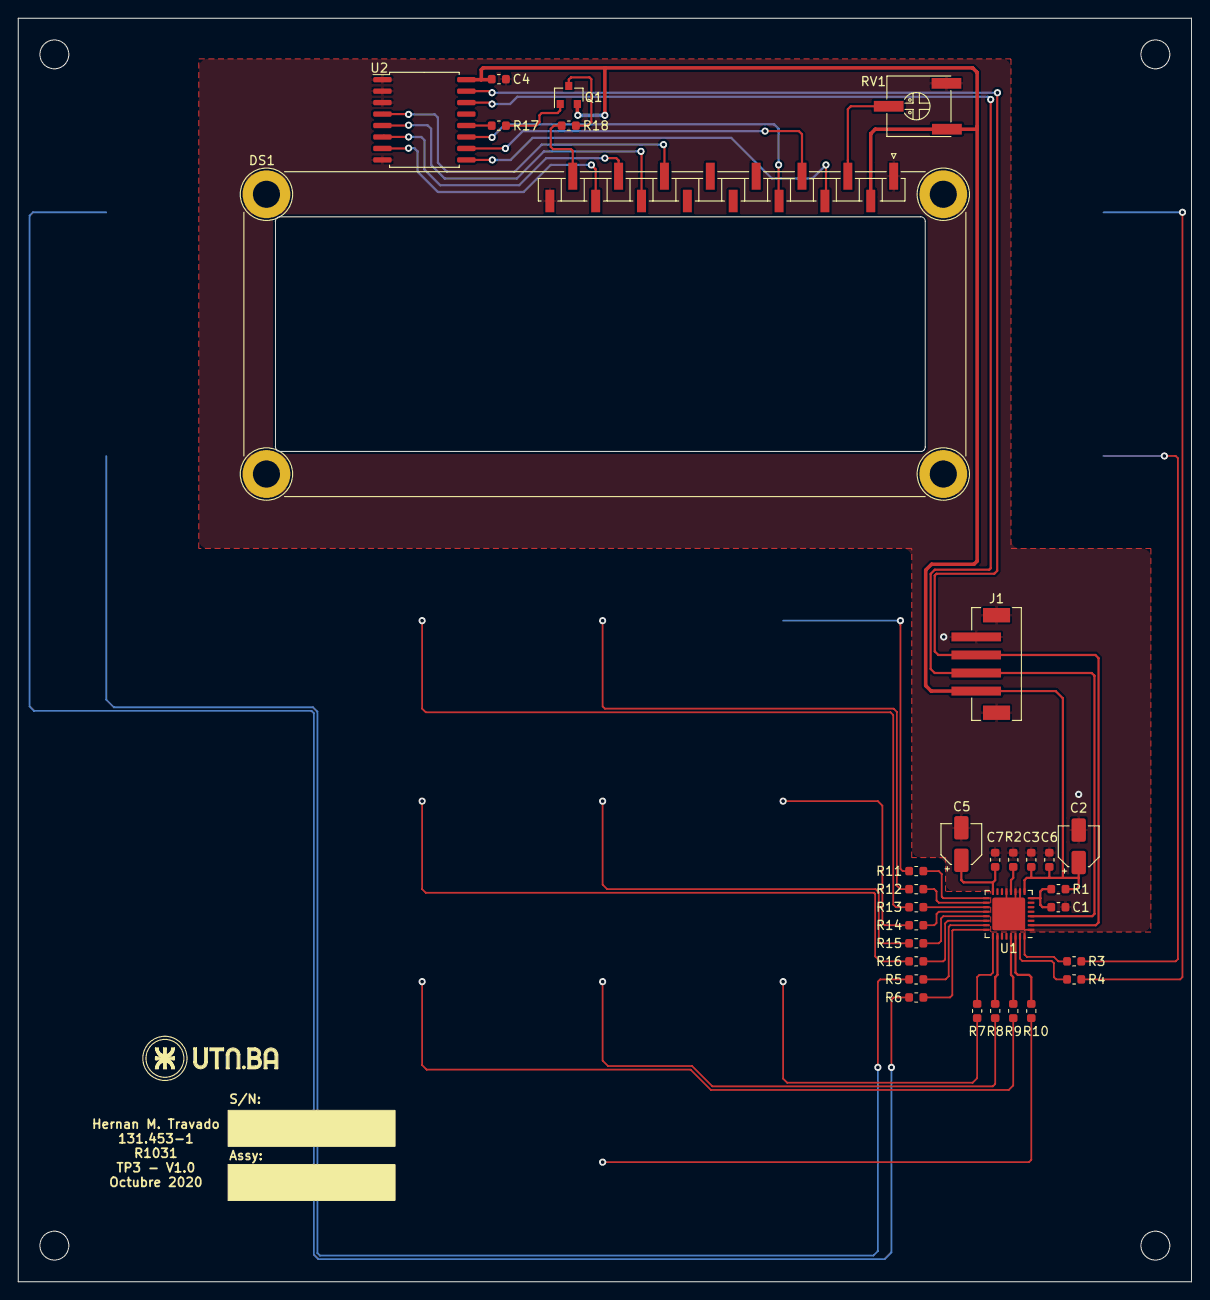
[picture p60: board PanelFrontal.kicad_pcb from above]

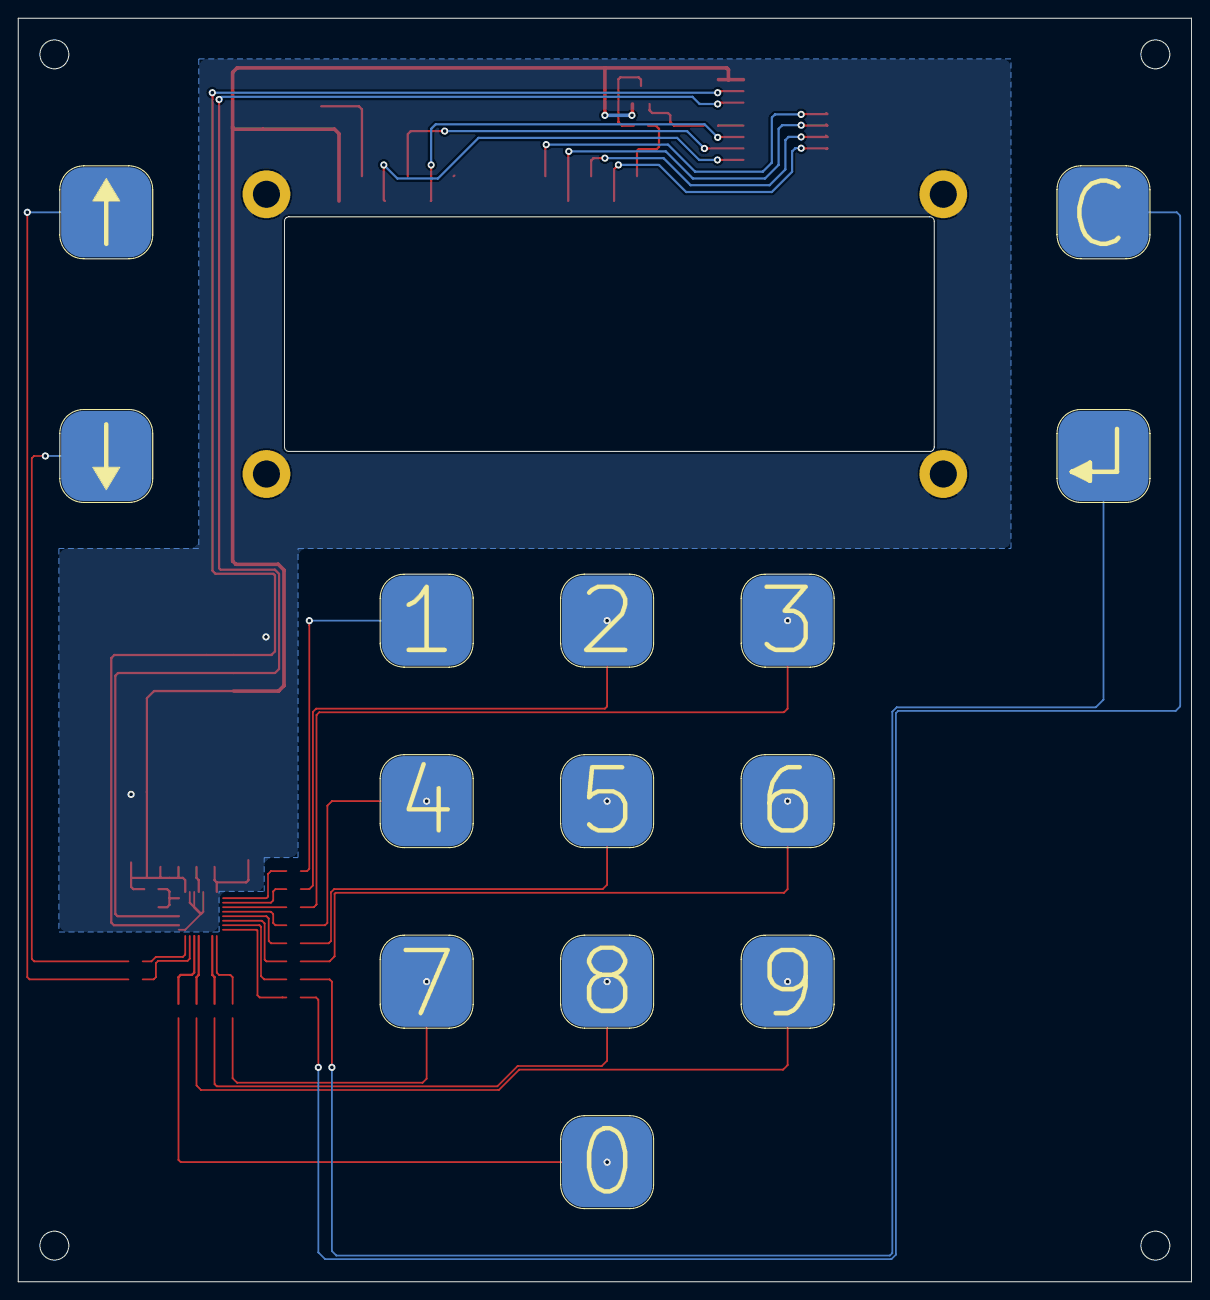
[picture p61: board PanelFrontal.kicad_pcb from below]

Board: 2 copper layers, 130.0 x 140.0 mm, 54 parts (14 on the bottom side), 47 nets.

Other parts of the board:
LogoUTN.BA-Letras: UTN.BA-Letras

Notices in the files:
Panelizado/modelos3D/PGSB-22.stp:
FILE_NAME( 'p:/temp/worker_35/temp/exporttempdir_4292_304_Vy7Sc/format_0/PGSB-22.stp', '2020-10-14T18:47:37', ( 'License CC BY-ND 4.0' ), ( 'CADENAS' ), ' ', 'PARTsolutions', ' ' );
